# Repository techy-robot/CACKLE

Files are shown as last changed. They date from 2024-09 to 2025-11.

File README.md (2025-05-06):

---
modified: 2025-05-05T23:28:19-07:00
---
# CACKLE - Card Adaptable Controller Kinetic Link Electronics
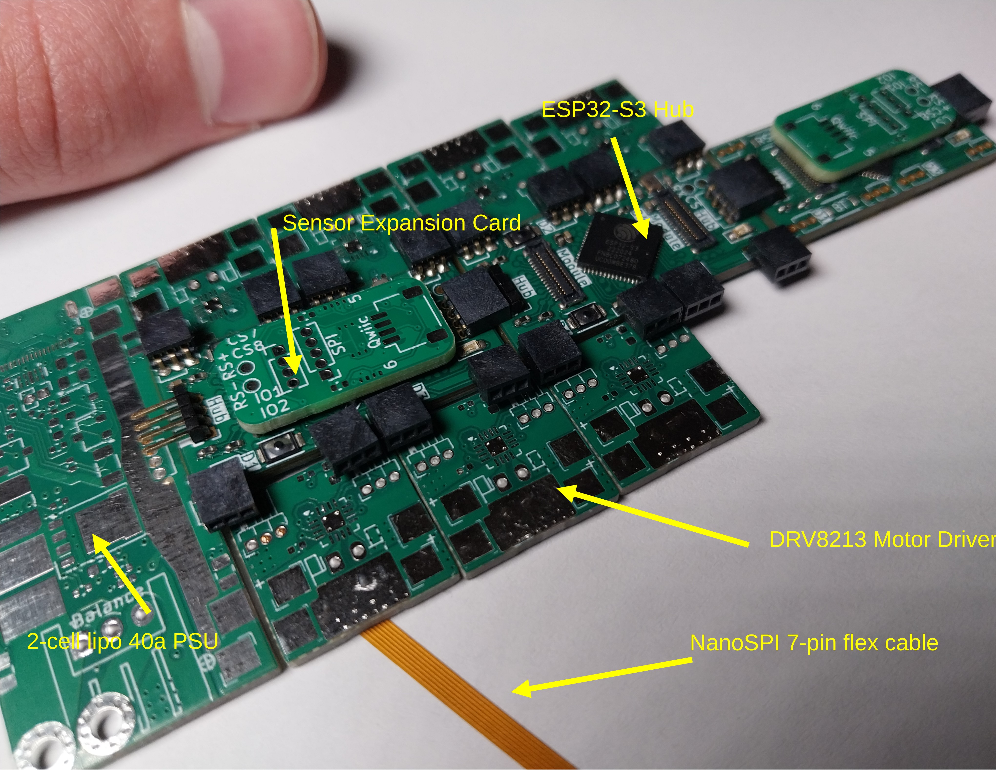
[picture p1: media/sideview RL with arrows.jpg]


This is designed to be a super small, open source, adaptable control board. Each module is arranged in units of 1.5cm squared, but can handle high power micro robotic actuators, such as my [Mighty-Micro-Motors](https://github.com/techy-robot/Mighty-Micro-Motors). Ideally this board can be reused and rebuilt for all sorts of small robots.

You can read up on specific modules in their respective folders in Hardware, or take a look at the overall architecture

Real Life pictures:




3D model demo:
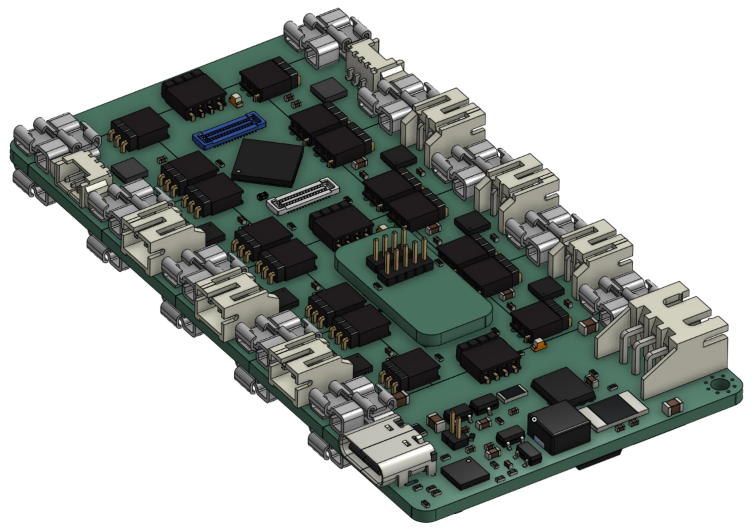
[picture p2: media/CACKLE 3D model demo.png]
CACKLE 3D model demo


# Architecture
There are currently 6 types of sub-boards:
- Hubs (with a MCU on it, supports 2 or 4 drivers, 2 expansion cards, and a chain of peers)
- PSUs (typically only one board)
- Expansion Cards (vertical mezzanine connector boards for breaking out sensors and other interfaces)
- Drivers (Any high power driver)
- nanoSPI devices (Small 7-pin flex cable SPI devices, mostly for sensors)
- Passives (spacers, end caps, etc...)

The base unit for this project is 1.5 cm squared. The expansion cards and drivers should each be 1 unit, the Hubs 1x1 or 1x2, and the PSUs 3x1 units. For example, with a 12 motor board you would need 1 PSU, 3 1-by-2 hubs, and 12 drivers; the board would be 45x105mm. nanoSPI devices can be much smaller due to the  2.4mm wide flex cable, such as a 5mm diameter magnetic encoder.

Unfortunately I was unable to create a 45x15mm PSU for the first version, it had to be extended up by 5mm to fit the high current circuitry.

My initial idea was to have spring contacts to allow easy clip in clip out, but finding no connectors quite what I wanted and unable to manufacture my own, I went with 1.27mm pitch pin headers and micro Keystone edge board connectors for power.

Original (bit outdated) sketch of the architecture:
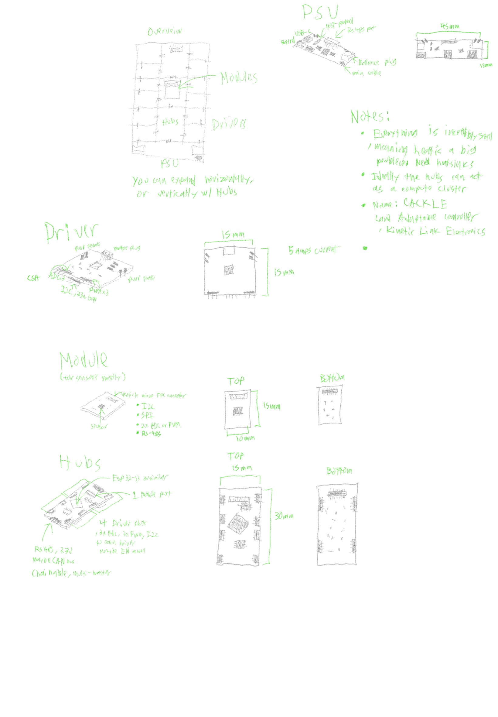
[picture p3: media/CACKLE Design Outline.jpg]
Cackle Design Outline


# Goals
- Adaptable 
- Small
- Extendable by other developers
- Easy to use
- Powerful

# Features
## Required:
- Super Small modules
- Hubs with an mcu that can talk to its peers and a master
- Motor driver boards that can handle several amps
- Sensor ports with protocols like i2c and SPI
- Extendable architecture
- PSUs
- LED status lights

## Nice to Have
- Distributed computing with a multi-master network
- Easy automatic hardware configuration
- Ability to stack hubs vertically using the Expansion Card system, in addition to horizontal chaining.

# Software
As of now software is very limited in scope, I have not had the time to fully assembly and test the boards I have made. I am planning on using SimpleFOC and Luos Engine. SimpleFOC is a motor driver library for Field Oreinted Control for motors. Luos Engine is a lightweight-distributed communication engine that aims to make hardware as modular as software. Combined, I have covered 50% of the use-cases of the code necessary for this project.

See [Software](Software/README.md) for more.

# Contributing
Feal free to contribute in any way possible! This is an open-source project, and with so many modules yet to be explored, I encourage you to help test boards, create modules or code, or ask about the project!

- GitHub Discussions: Participate in discussions on GitHub to share your experiences and ask questions.
- Contribute: Help develop the project, create PRs with new features or modules
- Report: Open issues, give me feedback!

Read the Architecture notes and [CONTRIBUTING.md](CONTRIBUTING.md) for more in-depth on this.

# A Note on Project Management
This project is managed transparently in this very repo. I am using Obsidian.md as my notetaking, documentation, and project management tool. A lot of the markdown files you will see in this repo might look a bit weird; that is due to the Wiki-links instead of markdown links and the YAML file front-matter that Obsidian supports. My system works well for one person, but I'm not sure how future proof this system is. You can find my sample vault here, which explains more: [GitHub - techy-robot/Project-Management-Obsidian-Sample-Vault](https://github.com/techy-robot/Project-Management-Obsidian-Sample-Vault).

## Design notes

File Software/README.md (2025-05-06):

# Software

Software is such a big element of any hardware project, and I do not like to write software, so I am using some really nice software libraries that I have found. The first is [SimpleFOC](https://www.simplefoc.com/), a motor driver library for Field Oreinted Control for motors, and the second is [Luos Engine](https://www.luos.io/), a lightweight distributed communication engine that aims to make hardware as modular as software. Combined, I have covered 50% of the use-cases of the code necessary for this project.

Most of the code found here are luos node definitions and driver services for each of the hardware modules, designed to be easily reusable in your project. There are also some tests and example code.

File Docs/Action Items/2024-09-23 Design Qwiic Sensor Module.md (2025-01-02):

---
title: Design Qwiic Sensor Module
aliases:
  - Design Qwiic Sensor Module
modified: 2024-09-23T19:24:35-06:00
tags: 
completed: true
itemtype: task
status: Done
date: 2024-10-21
startTime: 
endDate: 2024-10-26
endTime: 
deadline: 
allDay: true
priority: Low
effort: S
id: 
planned_hours: 
logged_hours: 
product_version: 
subitems: 
peeritems: 
milestone: 
createdby: 
assignees: 
completedby: 
completedDate: 2025-01-01
---
`BUTTON[complete, uncomplete]`

# Description:

This is just a sensor module to plug in to the top that fans out 4 adafruit qwiic connectors. Nothing major, not that important

# Comments:
- [ ] Comment ➕ YYYY-MM-DD ^1

# Time Tracking:
```simple-time-tracker
{"entries":[]}
```

# Changelog:
- 2024-09-23 Created

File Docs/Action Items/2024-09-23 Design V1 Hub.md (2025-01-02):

---
title: Design V1 Hub
aliases:
  - Design V1 Hub
modified: 2025-01-01T17:26:17-07:00
tags: 
completed: true
itemtype: task
status: Done
date: 2024-10-07
startTime: 
endDate: 2024-10-21
endTime: 
deadline: 
allDay: true
priority: Normal
effort: L
id: 
planned_hours: 30
logged_hours: 70
product_version: 
subitems: 
peeritems: 
milestone: "[[2024-09-23 Design V1 of all 4 modules|Design V1 of all 4 modules]]"
createdby: 
assignees: 
completedby: 
completedDate: 2025-01-01
---
`BUTTON[complete, uncomplete]`

# Description:

This is the central point of the modular control board. It talks to other hubs, drivers motor modules, and has multiple sensor interfaces. This is the most complex board followed by the PSU. See [[Architecture]].

This is a 6 layer board, which tries to follow the order Sig/Gnd/Pwr/Sig/Gnd/Sig. I did have to sacrifice the lower ground layer and route a few signals to make it all work together.

# Comments:
- [x] Shift all the motor pwm pins down, and stick the FREEx pins and the i2c pins near the end. Now, only the motor pins and the analog pins will have glitching. Since it is a low level glitch, and there are no pullups on those lines, it should be fine. ➕ 2024-10-17 ✅ 2024-10-17 ^1
- [x] Move out the pin headers a few 0.1mms so that the headers are exactly the distance required for connection to the motor cards ➕ 2024-10-18 ✅ 2024-10-18 ^2
- [x] Fix port 2 and 4 being swapped ➕ 2024-10-18 ✅ 2024-10-18 ^3
- [x] If I go with a 6 layer board design I will have more space to route, and JLC offers free filled vias with the increased cost, saving me even more space. ➕ 2024-10-18 ✅ 2024-10-18 ^4
- [x] The Free 1 and Free 2 pins might be more capable going on an analog capable pin. This, however, would require a fairly complex restructuring of the routing, which causes delay for not much gain ➕ 2024-10-19 ✅ 2025-01-01 ^5
- [x] There is a potentially big cross talk problem on layer In3. There is a high speed differential pair running on that layer, along with the lowspeed i2c lines, all right next to thick power traces. ➕ 2024-10-19 ✅ 2024-10-20 ^6
- [x] Disconnect all pins except RS485 and i2c from the bottom mezzanine connectors. If we stack hubs on top of eachother, we only want multi-master capable communications running through, otherwise there will be some fights. ➕ 2024-10-20 ✅ 2024-10-20 ^7

# Time Tracking:
```simple-time-tracker
{"entries":[{"name":"Schematic work","startTime":"2024-09-30T02:20:10.000Z","endTime":"2024-09-30T03:48:27.000Z"},{"name":"Schematic work","startTime":"2024-10-08T02:10:23.000Z","endTime":"2024-10-08T03:20:52.000Z"},{"name":"Finished rough schematic","startTime":"2024-10-09T01:45:54.000Z","endTime":"2024-10-09T03:20:43.000Z"},{"name":"Component Research","startTime":"2024-10-13T23:14:51.000Z","endTime":"2024-10-14T00:10:14.000Z"},{"name":"Designing footprint for mezzanine connectors","startTime":"2024-10-14T00:47:13.000Z","endTime":"2024-10-14T02:04:04.000Z"},{"name":"Component downsizing research, finished layout","startTime":"2024-10-15T20:15:11.000Z","endTime":"2024-10-16T01:59:11.000Z"},{"name":"started wire fanout","startTime":"2024-10-16T22:00:40.000Z","endTime":"2024-10-16T23:51:07.000Z"},{"name":"routing","startTime":"2024-10-17T21:36:40.000Z","endTime":"2024-10-18T00:03:41.000Z"},{"name":"routing and part rearrangement","startTime":"2024-10-18T15:54:34.000Z","endTime":"2024-10-18T16:56:00.000Z"},{"name":"routing 6 layers","startTime":"2024-10-18T19:45:01.000Z","endTime":"2024-10-19T00:06:37.000Z"},{"name":"debugging how to route a tricky wire","startTime":"2024-10-19T00:50:32.000Z","endTime":"2024-10-19T03:08:28.000Z"},{"name":"routing tricky wires","startTime":"2024-10-19T20:01:01.000Z","endTime":"2024-10-20T00:20:07.374Z"},{"name":"finished routing","startTime":"2024-10-20T14:49:04.000Z","endTime":"2024-10-20T15:50:43.000Z"},{"name":"finishing up","startTime":"2024-10-20T16:00:37.000Z","endTime":"2024-10-20T19:34:19.609Z"}]}
```

# Changelog:
- 2024-09-23 Created

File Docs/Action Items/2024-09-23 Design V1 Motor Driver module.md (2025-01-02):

---
title: Design V1 Motor Driver module
aliases:
  - Design V1 Motor Driver module
modified: 2025-01-01T17:26:04-07:00
tags: 
completed: true
itemtype: task
status: Done
date: 2024-09-23
startTime: 
endDate: 2024-10-07
endTime: 
deadline: 2024-10-07
allDay: true
priority: Normal
effort: M
id: 
planned_hours: 10
logged_hours: 7
product_version: 
subitems: 
peeritems: 
milestone: "[[2024-09-23 Design V1 of all 4 modules|Design V1 of all 4 modules]]"
createdby: 
assignees: 
completedby: 
completedDate: 2025-01-01
---
`BUTTON[complete, uncomplete]`

# Description:

# Comments:
- [x] I need to redo the power connector scheme, to make it work in reverse 180 orientation and to use the cheaper connectors. Reverse orientation capability would mean I need 4 connectors per edge. It *should* save time and hassle so that I don't have to produce a mirror board copy, but it will be costly. Another benefit is double the current capacity. ➕ 2024-10-14 ✅ 2024-10-21 ^1

# Time Tracking:
```simple-time-tracker
{"entries":[{"name":"Initial modifications from prev design","startTime":"2024-09-24T01:32:53.000Z","endTime":"2024-09-24T02:37:31.819Z"},{"name":"Finished basic layout","startTime":"2024-09-24T02:38:05.000Z","endTime":"2024-09-24T03:05:01.000Z"},{"name":"Finished basic routing","startTime":"2024-09-25T02:00:09.000Z","endTime":"2024-09-25T03:17:32.000Z"},{"name":"Finished design and silkscreen","startTime":"2024-09-27T21:37:55.000Z","endTime":"2024-09-27T23:19:31.000Z"},{"name":"Segment 5","startTime":"2024-10-21T14:00:11.000Z","endTime":"2024-10-21T15:50:21.000Z"}]}
```

# Changelog:
- 2024-09-23 Created

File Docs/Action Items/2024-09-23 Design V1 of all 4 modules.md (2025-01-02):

---
title: Design V1 of all 4 modules
aliases:
  - Design V1 of all 4 modules
modified: 2024-09-23T18:46:33-06:00
tags: 
completed: true
itemtype: milestone
status: Done
date: 2024-09-23
startTime: 
endDate: 2024-10-31
endTime: 
deadline: 2024-10-31
allDay: true
id: 
product_version: 
peeritems: 
subitems: 
createdby: 
assignees: 
completedDate: 2025-01-01
---
`BUTTON[complete, uncomplete]`

# Description:

In 1 month and 1 week, I hope to have a complete basic set of boards complete, with all 4 types of boards. See [[Architecture]]. 

# Comments:
- This I believe is achievable, because I've already done half the design work from other projects, all I need to do is change the form factor! ➕ 2024-09-23 ^1
- 
# Changelog:
- 2024-09-23 Created

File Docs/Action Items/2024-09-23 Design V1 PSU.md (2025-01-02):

---
title: Design V1 PSU
aliases:
  - Design V1 PSU
modified: 2025-01-01T17:25:49-07:00
tags: 
completed: true
itemtype: task
status: Done
date: 2024-10-25
startTime: 
endDate: 2024-11-10
endTime: 
deadline: 2024-11-10
allDay: true
priority: Normal
effort: L
id: 
planned_hours: 50
logged_hours: 40
product_version: 
subitems: 
peeritems: 
milestone: "[[2024-09-23 Design V1 of all 4 modules|Design V1 of all 4 modules]]"
createdby: 
assignees: 
completedby: 
completedDate: 2025-01-01
---
`BUTTON[complete, uncomplete]`

# Description:

# Comments:
- [x] I found several design errata from the original, such as swapped polarity on the balance plug, and incorrect input voltage source. My prototype will need modification ➕ 2024-10-27 ✅ 2025-01-01 ^1
- [-] I should add a secondary rs485 transceiver for redundancy for the host. The battery charge mcu should not have to act as a passthrough for the main compute module. Still, for this prototype it is unneccessary ➕ 2024-11-08 ❌ 2025-01-01 ^2
- [-] Use XT30 connectors for the main battery plug ➕ 2024-11-08 ❌ 2025-01-01 ^3
- [x] The BQ24780s does not handle charge profiles by itself, the i2c host has to handle all the battery charge profiles by itself. ➕ 2024-11-08 ✅ 2025-01-01 ^4

# Time Tracking:
```simple-time-tracker
{"entries":[{"name":"Initial arrangment of schem","startTime":"2024-10-26T02:39:49.000Z","endTime":"2024-10-26T03:48:16.000Z"},{"name":"schematic verification","startTime":"2024-10-26T22:47:46.000Z","endTime":"2024-10-27T00:24:49.000Z"},{"name":"rearranging schematic","startTime":"2024-10-27T00:57:04.000Z","endTime":"2024-10-27T02:34:08.000Z"},{"name":"component research, schematic work","startTime":"2024-10-27T22:02:31.000Z","endTime":"2024-10-28T00:08:18.000Z"},{"name":"verification and component switching","startTime":"2024-10-28T00:53:49.000Z","endTime":"2024-10-28T01:40:12.000Z"},{"name":"Adding MCU","startTime":"2024-11-07T02:06:24.000Z","endTime":"2024-11-07T03:01:16.000Z"},{"name":"Starting routing from scratch","startTime":"2024-11-08T00:29:47.000Z","endTime":"2024-11-08T01:08:36.609Z"},{"name":"Working on MCU section again","startTime":"2024-11-08T02:23:47.000Z","endTime":"2024-11-08T05:26:09.000Z"},{"name":"schematic work","startTime":"2024-11-08T16:56:29.000Z","endTime":"2024-11-08T17:57:02.000Z"},{"name":"research of components","startTime":"2024-11-08T22:13:40.000Z","endTime":"2024-11-09T01:58:19.000Z"}]}
```

# Changelog:
- 2024-09-23 Created

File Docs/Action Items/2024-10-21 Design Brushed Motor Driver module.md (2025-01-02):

---
title: Design V1 Motor Driver module
aliases:
  - Design V1 Motor Driver module
modified: 2024-10-25T17:01:51-06:00
tags: 
completed: true
itemtype: task
status: Done
date: 2024-10-21
startTime: 
endDate: 2024-10-26
endTime: 
deadline: 2024-10-26
allDay: true
priority: Normal
effort: M
id: 
planned_hours: 10
logged_hours: 9
product_version: 
subitems: 
peeritems: 
milestone: "[[2024-09-23 Design V1 of all 4 modules|Design V1 of all 4 modules]]"
createdby: 
assignees: 
completedby: 
completedDate: 2025-01-01
---
`BUTTON[complete, uncomplete]`

# Description:

# Comments:
- [ ]  ➕ 2024-10-14 ^1

# Time Tracking:
```simple-time-tracker
{"entries":[{"name":"Initial work","startTime":"2024-10-22T00:30:45.000Z","endTime":"2024-10-22T03:30:47.000Z"},{"name":"edited schemtatic for the more complex chip","startTime":"2024-10-24T03:18:30.000Z","endTime":"2024-10-24T03:45:03.000Z"},{"name":"Changing Schematic","startTime":"2024-10-24T16:01:49.000Z","endTime":"2024-10-24T16:20:35.000Z"},{"name":"Changing Schematic to enable inrush limits at all times","startTime":"2024-10-24T18:30:52.000Z","endTime":"2024-10-24T19:11:00.554Z"},{"name":"routing and adding testpoints","startTime":"2024-10-25T02:22:25.000Z","endTime":"2024-10-25T03:50:00.000Z"},{"name":"Segment 6","startTime":"2024-10-25T19:56:10.000Z","endTime":"2024-10-25T22:56:19.697Z"}]}
```

# Changelog:
- 2024-09-23 Created

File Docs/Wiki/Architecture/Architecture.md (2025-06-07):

---
aliases: 
tags: 
append_modified_update: true
modified:
  - 2024-08-09T20:39:57-06:00
  - 2024-08-11T20:12:22-06:00
  - 2024-09-07T17:55:38-06:00
  - 2024-09-08T09:46:12-06:00
  - 2024-09-16T21:17:40-06:00
  - 2024-09-23T18:45:05-06:00
  - 2024-10-19T17:45:06-06:00
  - 2024-11-06T17:24:05-07:00
  - 2024-11-22T22:24:30-07:00
  - 2025-01-01T19:29:53-07:00
  - 2025-03-02T16:29:23-07:00
---
# Types of sub-boards
- Hubs (with an MCU on it, supports 2 or 4 drivers, 2 expansion cards, and a chain of peers)
- PSUs (typically only one board)
- Expansion Cards (vertical mezzenine connector boards for breaking out sensors and other interfaces)
- Drivers (Any high power driver)
- nanoSPI devices (Small 7-pin flex cable SPI devices, mostly for sensors)
- Passives (spacers, end caps, etc...)

# Dimensions
The base unit for this project is 1.5 cm squared. The expansion cards and drivers should each be 1 unit squared, the Hubs 1x1 or 1x2, and the PSUs 3x1 units. With a 12 motor board with PSU for example, the board would be 45x105mm. nanoSPI devices can be much smaller due to the flex cable, such as a 5mm diameter tip and 2.4mm wide cable.

Any board on the ends of the main board (PSUs or sensor arrays) can be extended beyond the 1 unit vertical limitation. For example, the V1 PSU is 20mm instead of 15mm high, meaning its 3x1 & 1/3 units.

# Communication Protocol
The Hubs communicated over a 3.3v (NOT 5v!) RS485 bus using Modbus or a derivative communication protocol. It is a multi master system.

Sensors can communicate to the hubs using I2c or SPI, and the hubs can subsequently advertise the sensor resources on the main network.

The one exception to the RS485 network is for GPU intensive modules, such as displays or cameras. Those are expected to go directly to the board requiring the resources and not to be broadcasted over the network, due to bandwidth limitations.

# MCU requirements
Highspeed 32-bit MCUs for the hubs are ideal with over 100mhz clock speed. Dual-core MCUs are nice but not required. The chips should operated on 3.3volts and not be sensitive to voltage fluctuations. 

The chips should also have DMA access or a highspeed peripherial for PWM and ADC pins, and all external driver connections must be connected directly to them. Other pins do not have to be connected directly to the hub since they are less demanding. 

At least one I2c and one SPI bus is required for the expansion ports and the nanoSPI connectors. If the device has multiple buses and can afford it in pins, you can split the networks per expansion connector or between nanoSPI connectors and expansion connectors.

Only 2 ADC lines per driver slot are required, though 3 is nice. There isn't currently a need for 3 ADC lines because both brushed and brushless motor drivers can work fine with only 2 current sense feedback lines. This may change

The first chip I used is the esp32-s3. This chip is a low on pins, so some tricks such as disabling USB, programming over the sensor SPI bus, and using a shift register for SPI chip selects were used. I also have exposed only 2 adc lines per driver.

# Numbering Scheme
The numbering scheme between hubs is bottom up, with the PSU at the very bottom as address 0, and hubs connected on top of that with subsequent numbers. All the sensor and motor ports per hub follow this numbering scheme as well, with a left to right scheme added. Even the individual driver pins follow the bottom up scheme

# Changelog:
- 2024-08-09 Created
- 2025-01-01 Updated ideas and spec
- 2024-03-02 Added jumbo size and power bypass ideas

See also:
```dataview
LIST
FROM outgoing([[]])
```

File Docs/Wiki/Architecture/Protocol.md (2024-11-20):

---
aliases: 
tags: 
append_modified_update: true
modified:
  - 2024-09-16T21:19:03-06:00
  - 2024-09-29T21:48:08-06:00
  - 2024-10-08T20:11:50-06:00
  - 2024-10-27T21:47:33-06:00
---

# Protocol
Ideally I want this board is to be **asymmetrical** in communication, where no one MCU is master. This theoretically would allow me to have a **compute cluster** using onboard MCUs, without relying on a powerful SBC. I will still likely have a host SBC talk with the board for advance AI. Each MCU has a customizable config that can be updated to help it understand it's place and connected motors and sensors. The best multi-master/ multi-drop busses I found are differential, such as RS485, ethernet, and CAN. They all support buses and collision detection, though RS485 is just a hardware spec and you have to write your own multi-master protocol on top.

Yet there are also a lot of **dis-advantages** with this setup, namely **Speed and cost**. Any sort of differential bus is NOT usually supported natively, and therefore will require a 1 dollar transceiver per board. It is also really slow, with CAN bus topping out at 1MB/s. Ethernet is much higher speed, but it requires really expensive chips or a lot of pins. SPI bus in this case would win for speed and cost savings, though it would mean a master and slave architecture

SPI bus has its own problems though, such as not being infinitely expandable. The number of devices is limited to the number of pins on the master, meaning I can't plug in boards forever.

It appears like I am in a sticky conundrum, with no where to turn without sacrifices. I want infinite expandibilty, high speed, and low cost. I could write my own ring-based protocol, but that would be slow speed and probably not that reliable. If I wrote a protocol and wanted it high-speed, the best way to achieve that would be to use an existing hardware protocol..

For a project like my robot dog with limited motor potential, it is easier to choose a protocol. I could probably just use SPI, since I will unlikely have more than 4 hubs. I loose out on asymmetrical, but I save cost and have super high speeds. For any other projects though it is tough, especially since the board will be its own commercial product.

THE ONLY bus that seems to balance everything is I2C. It is low speed like CAN bus, but it is virtually in every micro controller in modern times, which is cheap. If you add a layer on top you get SMbus, which supports arbitration and multimaster easily. Bus speeds are limited to 100khz with SMbus.

A bus that I found very interesting is called I3C. Its meant to be a replacement bus operating at 12.5mhz and supporting everything that i2c does. Think SMbus, with hotplug and a 100x speed. It is not supported by most board yet though.

RS-485 is my ideal second choice, because I can implement whatever protocol I wanted and use some cheap $1 transceivers (like the TI 1420 ($1.03) or  ISP3485EN-L/TR ($0.87)). CAN bus transceivers cost more, even in the same SOIC-8 package. If I wanted a smaller package I could pay more and get THVD1420DRLR for $1.42

Another Idea I had was using a RP2040 as a repeater. If I had a 15x15mm module between, then it could repeate the SPI signals and have infinite number of chip selects. The RP2040 can also have 2 motor driver modules plugged in, (it has exactly 4 ADC), and it can also act as a node itself for computing. Its only a dollar, which is about the price of a differential bus transceiver!

I could write a protocol that supports user-assisted auto addressing. The user could press the BOOT buttons on each board in order, and the address will be broadcasted on the network on by one! The ordered number would also be saved on chip, and each chip would have its own map. This idea works for both multi-master and master-slave architecture, and does not need external connections to setup a network. Each device added afterward initial setup would broadcast its mac address, and would be assigned a number based on the existing map. You can trigger a map reset too. 

For hotplugging rs 485 support I should have the chip assume on powerup that nothing is talking to it, and only after a set delay of idle bus should it respond

I also found an opensource product that does almost exactly what I want for my modular robot control system! Its called [luos_engine](https://github.com/Luos-io/luos_engine). Every MCU knows all the others in the system and can communicate with any of the servicies. This was just a random discussion I found on the SimpleFOC discord about its integration. [Luos Technology | Luos](https://www.luos.io/docs/luos-technology). Luos has its own communication protocol built in, called Robus, which supporst Rs485 or One wire. It supports 700kbs per second for data max on a 1mhz bus. I would write my own motor services and process data commands.

# Changelog:
- 2024-09-16 Created

See also:
```dataview
LIST
FROM outgoing([[]])
```

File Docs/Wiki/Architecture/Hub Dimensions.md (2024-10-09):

---
aliases: 
tags: 
append_modified_update: true
modified:
  - 2024-10-08T21:05:46-06:00
---

Each hub has 4 motor ports, with 1.27mm pin header sockets sticking past the edge of the board

The board should have two M2 screw holes in the board somewhere.

There are two mezzanine connectors receptors on the top, and two headers on the bottom. They are centered in each half of the board, so 8.5mm away from the edges. This provides room for the esp32 to be in the direct center, and it provides future opportunities such as 2 sensors per board, spanning sensor mounts between boards, or a half length 2 motor hub.

# Changelog:
- 2024-10-08 Created

See also:
```dataview
LIST
FROM outgoing([[]])
```

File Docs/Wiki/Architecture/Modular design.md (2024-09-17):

---
aliases: 
tags: 
append_modified_update: true
modified:
  - 2024-08-09T20:39:57-06:00
  - 2024-08-11T20:12:22-06:00
  - 2024-09-07T17:55:38-06:00
  - 2024-09-08T09:46:12-06:00
  - 2024-09-16T21:17:40-06:00
---
It is a modular control board design, with 4 main types of units:
- Hubs (with an MCU on it, supports 4 drivers, one sensor with a vertical micro connector, and a chain of peers)
- PSUs (typically only one board)
- Modules/ Sensors (vertical mezzenine connector boards for sensors)
- Drivers (Any high power motor driver, plus a SPI bus for feedback sensors)

The base unit for this project is 1.5 cm squared. The modules and drivers should each be 15x15mm, while the Hubs are 15x30mm. There is a slight possibility it can be 15x10mm instead.

With a 12 motor board that would be 45x90mm

The PSU and any extra peripheral such as speakers will have to be off-board and crammed somewhere else, though small sensors can be mounted vertically on the connectors. If the Battery charger is too difficult to cram in the provided space, I could move the battery charger off the board and have the battery protector in the robot only.

My idea is to use some highspeed dual core MCUs for the hubs, something like the ESP32-s3. The esp32-s3 is low on pins, therefore I will have to use some tricks such as disabling USB, programming over the sensor SPI bus, and using a multiplexor or shift register for SPI chip select. Depending on the chosen inter-hub protocol I may have a few more pins.

Ideally I will have spring contacts for all the modules, and you can just clip them in. But I will have to custom manufacture these board springs that clip into through holes, because I haven't found any commercially available ones. Alternately I can use some Keystone micro SMD tab pins.

3.3v should be supplied to the Drivers, in case I wanted to plug in a bigger or power hungry sensor board, or if I have a driver chip that doesn't have a built in regulator.

# Changelog:
- 2024-08-09 Created

See also:
```dataview
LIST
FROM outgoing([[]])
```

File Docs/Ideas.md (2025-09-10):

---
aliases:
tags:
append_modified_update: true
modified:
  - 2025-06-06T20:38:58-06:00
  - 2025-09-09T16:25:11-06:00
---

# New Module Types
- A compute board would be nice, I'm thinking it would be a 45mm x45mm SBC with connectors to pass power and signals through
- Various "passive" board types, like power hubs, horizontal or vertical spacers where you want empty space, and blank driver and sensor boards where all the signals are exposed for easier prototyping and soldering.
- I also have an idea for sensor array's, which are on the opposite ends of a PSU. They measure 15x45 and exist for advanced sensors such as cameras, LIDAR, or anything really that doesn't fit in the normal 10mmx15mm sensor package.
- Jumbo sized modules, that are 30x30. This is for really complex items that need highpower and more surface area, like a mosfet or relay.
- Isolators for power and signals that prevent interferance
- Translators, for rs485 to canbus or usb or whatever.
- 1 sided PSUs and PSUs with no driver output

# New Modules
- DRV8850 motor driver, a high current (5-8amps), low voltage (5v) H-bridge driver. Needs 4 control pins

# Other ideas
- Move from 3pwm outputs to 4 pwm outputs for each port on the hubs, in-case you wanted to have a manual h-bridge a dual motor controller, or a stepper driver that didn't have step/dir control.
- Shrink the base unit from 15mm squared to 10mm squared.
- Power Bypass connection ecosystem, a bunch of thick wires and jumpers between boards instead of board to board. This should be for highvoltage or high currant applications

# Changelog:
- 2025-06-06 Created

See also:
```dataview
LIST
FROM outgoing([[]])
```

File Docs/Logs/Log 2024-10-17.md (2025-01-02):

---
aliases:
  - 2024-10-17
append_modified_update: true
modified:
  - 2024-10-17T22:31:13-06:00
  - 2025-01-01T17:30:37-07:00
---
←[[Log 2024-09-23|2024-09-23]] [[Logs]] [[Log 2025-01-01|2025-01-01]]→
# Thursday
___

I've started the pcb routing and have discovered some issues.

I changed the schematic so that the Shift Register clock is also on a dual high/low glitching pins. I swapped out a test pad for a Free 2 pin, for the second expansion connector.

I2c w/ pullups will likely have problems with glitching on those first 20 pins, so I have shifted all the motor pwm pins down, and stuck the FREEx pins and the i2c pins near the end. Now, only the motor pins and the analog pins will have glitching. Since it is a low level glitch, and there are no pullups on those lines, it should be fine.

# Ongoing:
- 
# Changelog:
- 2024-10-17 Created

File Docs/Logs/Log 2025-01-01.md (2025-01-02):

---
aliases:
  - 2025-01-01
append_modified_update: true
modified:
  - 2025-01-01T17:30:29-07:00
---
←[[Log 2024-10-17|2024-10-17]] [[Logs]] [[]]→
# Wednesday
___

I finally finished all my designs! Horray! It was really difficult and I made many mistakes that had to be fixed.

I haven't kept the most faithful time track, mostly due to other activities and finding a better time tracking method with Wakatime.

# Ongoing:
- Order V1 boards!
# Changelog:
- 2025-01-01 Created

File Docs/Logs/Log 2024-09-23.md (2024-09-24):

---
aliases:
  - 2024-09-23
append_modified_update: true
modified:
  - 2024-09-23T21:06:18-06:00
---
←[[]] [[Logs]] [[]]→
# Monday
___

Today I am kicking off my design phase. I will design one of each type of board, and I have 1 month and 1 week to do so. Milestone: [[2024-09-23 Design V1 of all 4 modules|Design V1 of all 4 modules]]. 

I finished the basic layout of a 15mmx15mm driver card. It will need some tuning, and the power connectors as of now have no way of contacting adjacent cards.

# Ongoing:
- [[2024-09-23 Design V1 Motor Driver module|Design V1 Motor Driver module]]
# Changelog:
- 2024-09-23 Created

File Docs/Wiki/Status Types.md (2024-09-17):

---
modified:
  - 2024-01-11T15:55:46-07:00
  - 2024-05-13T11:26:11-06:00
append_modified_update: true
---

Ideally these will all have specific colors. I will list the colors here, even if I haven't implemented the css yet.

status:
- New:   Dark Blue
- Blocked:   Red
- In Progress:   Yellow
- Pending:   Yellow
- Done:  Green
- Archived:  Grey

priority:
- Low: Dark Green
- Normal: Green
- Medium: Yellow
- High: Orange
- Critical: Red

effort:
- XS
- S
- M
- L
- Xl
- XXL

type:
- task
- subtask
- bug
- story
There are also types that have their own template:
- milestone
- goal

goalstatus:
- On Track: Green
- Off-Track: Yellow
- At Risk: Yellow
- Miss: Red
- Not Started: Grey
- Finished: Green
- Discontinued: Grey

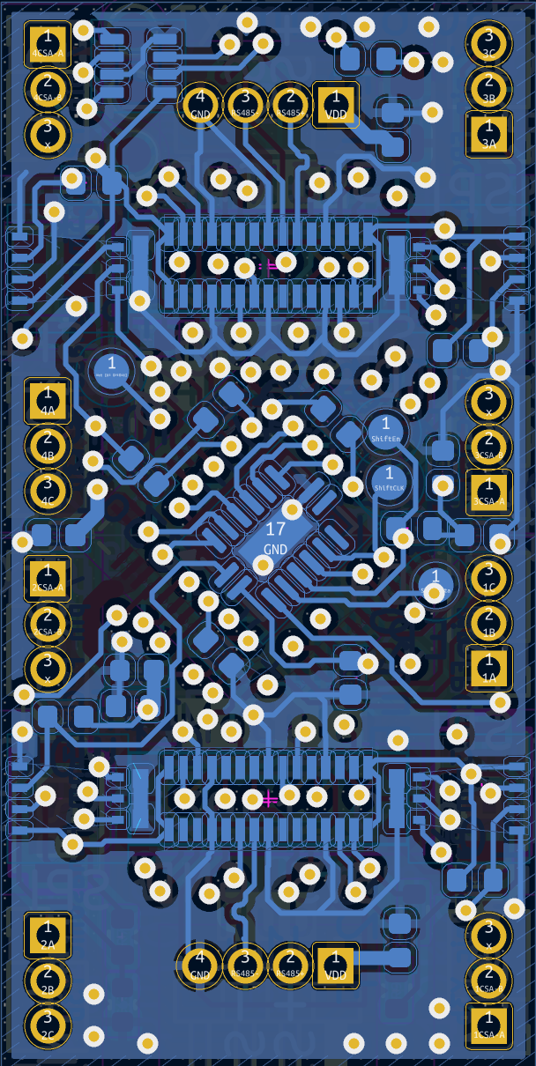
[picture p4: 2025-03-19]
Hardware/Hubs/ESP32-S3 Hub/media/ESP32-S3 hub Bottom.png

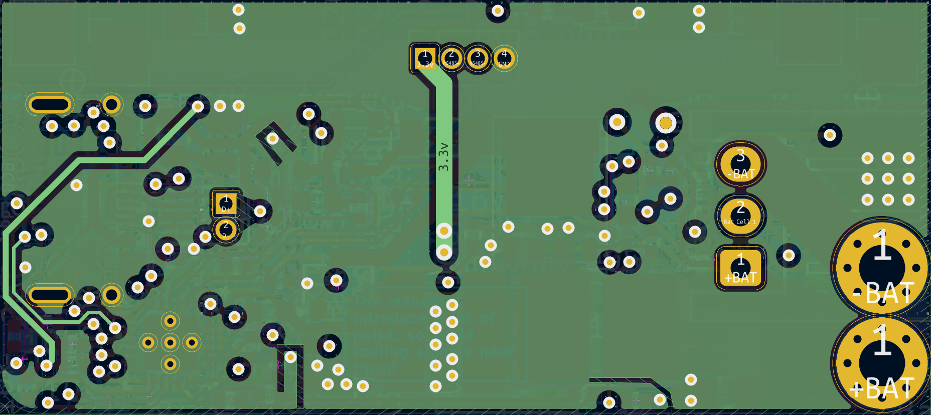
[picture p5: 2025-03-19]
Hardware/PSUs/2s 40A PSU and charger/media/2s 40a PSU In1.png

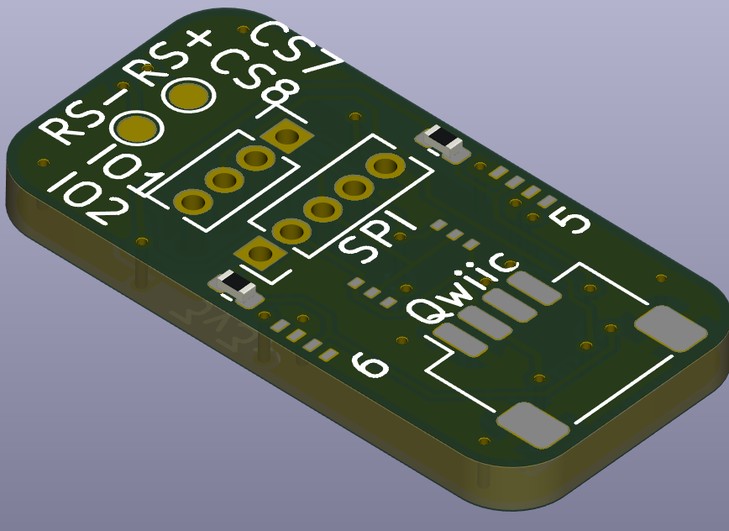
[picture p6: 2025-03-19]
Hardware/Expansion cards/2 connector Sensor Board/media/2 conn Sensor Board 3D.png

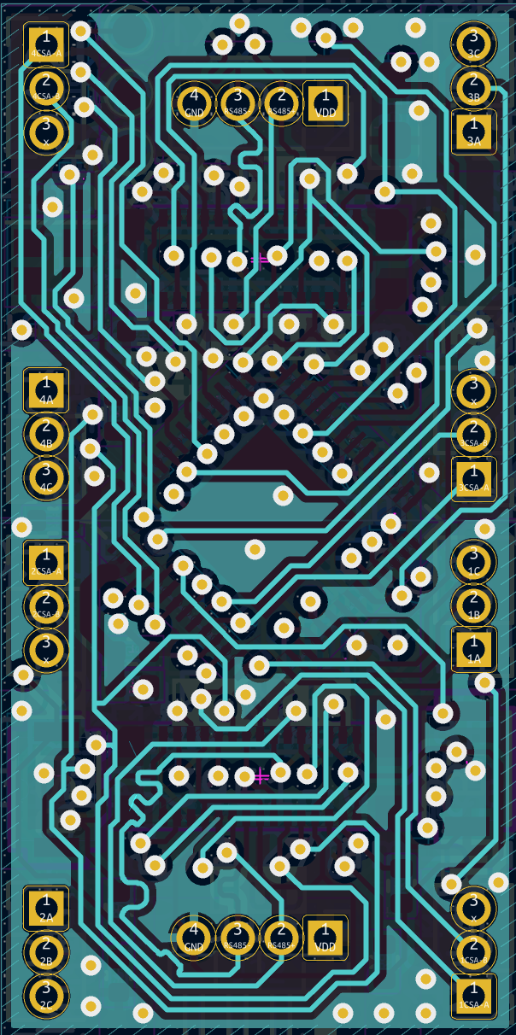
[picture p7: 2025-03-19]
Hardware/Hubs/ESP32-S3 Hub/media/ESP32-S3 hub In3.png

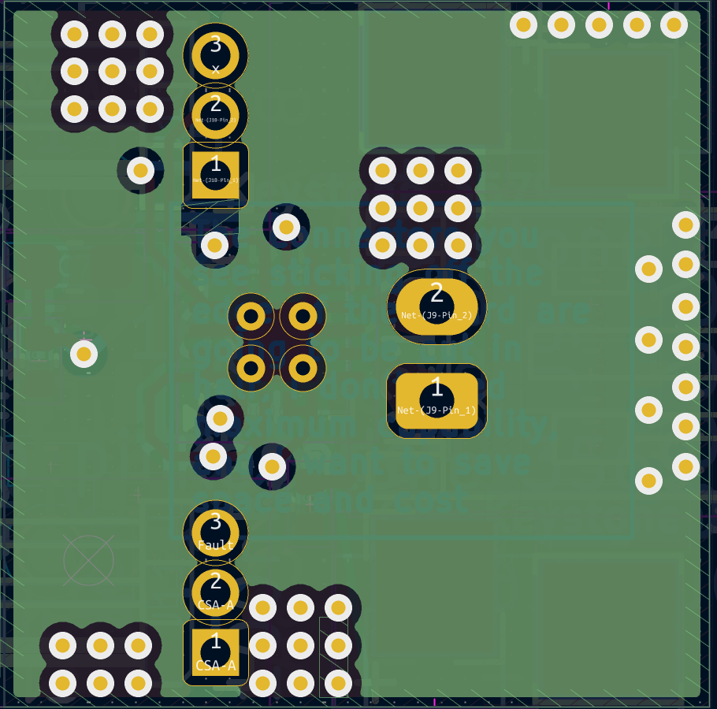
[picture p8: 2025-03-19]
Hardware/Drivers/DRV8213 brushed Motor Driver/media/DRV8213 In1.png

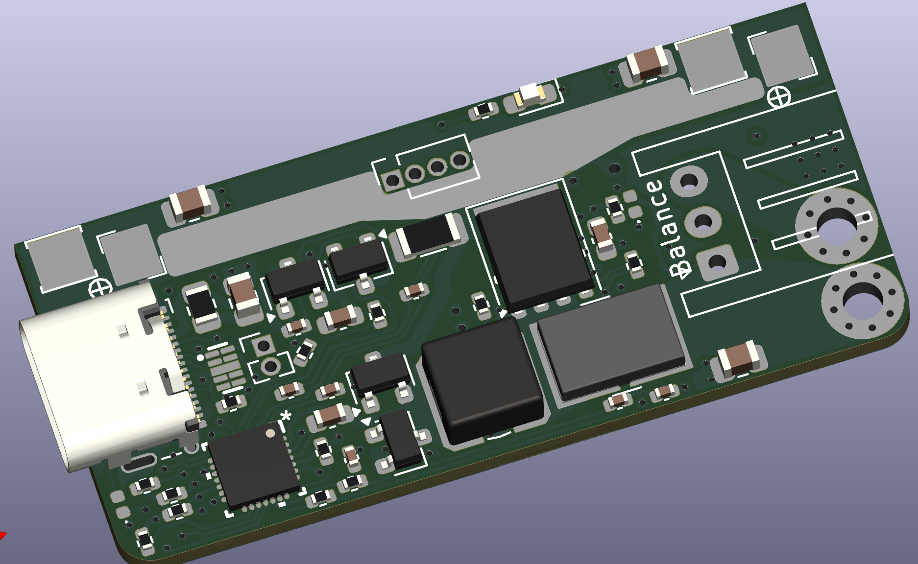
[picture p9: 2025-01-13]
Hardware/PSUs/2s 40A PSU and charger/media/2s 40a PSU 3D picture.png

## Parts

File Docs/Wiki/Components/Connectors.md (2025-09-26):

---
aliases:
tags:
append_modified_update: true
modified:
  - 2024-10-14T22:13:06-06:00
  - 2025-09-23T16:41:40-06:00
---

I am trying to save money while still acheiving what I need. Currently, for signal lines I am using 1.27mm right angle pin headers, and for Power, I'm using Keystone 6100 and 6102 quick connect edge connectors. For vertical Mezzanine connectors, I am using TE 3-2363961-0 receptacle and TE 3-2363962-0 connector, 30 pins.

The power connectors are expensive, around $1.8 per pair. I have found a sister product that is much cheaper however, and provides almost the exact same functionality. Its Keystone 3579, which is tin plated instead of gold plated. It can still carry 10 amps per connector. The matching component is 3569, which is a fuse clip. Now, this is much longer than the 610x receptacle, and the blade doesn't stick completely into it. I had a fun idea of chopping the part in half, and using it twice. The length would match, it would just be unstable on the board (ie not usable on a PnP).

If I cut in half, the price per pair would be $0.83! This seems like a pretty good deal for a high current SMD connector, at least compared to everything else I've seen. I would probably get lower only if I stamped my own spring connectors.

# Alternative connectors:
- https://www.digikey.com/en/products/detail/amphenol-cs-fci/10120045-401LF/4996150. 4 position LED lighting connector. This has a much wider spacing than I want, but is a good style with the blades. The connector is Hermaphroditic too.
- https://www.digikey.com/en/products/detail/hirose-electric-co-ltd/TB4-10P-1F-800/26223934 This is interesting, fpc connector to a different type of connector. There is no board to board option though.
- https://www.digikey.com/en/products/detail/sullins-connector-solutions/EBC06MMBD/1922770 This is the only right angle edge card connector I can find, there are millions of female connectors.
- https://www.digikey.com/en/products/detail/amphenol-cs-fci/10162583-411111LF/15216696 Something that has right angle header but no right angle receptacle.
- [504275-E : ERNI PCB Headers & Receptacles \| TE Connectivity](https://www.te.com/en/product-504275-E.html) This is pretty good.
- [917360-6 : AMPMODU PCB Headers & Receptacles \| TE Connectivity](https://www.te.com/en/product-917360-6.html) Looks like what I want, but its obselete!!

# Changelog:
- 2024-10-14 Created

See also:
```dataview
LIST
FROM outgoing([[]])
```

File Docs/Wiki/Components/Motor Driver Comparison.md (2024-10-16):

---
modified:
  - 2024-03-10T20:55:09-06:00
  - 2024-03-25T23:00:11-04:00
  - 2024-03-26T23:00:08-04:00
  - 2024-03-27T23:03:02-04:00
  - 2024-03-28T20:45:51-05:00
  - 2024-03-29T21:33:36-06:00
  - 2024-04-18T10:13:47-06:00
  - 2024-04-23T19:48:00-06:00
  - 2024-04-25T20:01:09-06:00
  - 2024-04-27T14:00:26-06:00
  - 2024-04-29T18:03:12-06:00
  - 2024-10-14T22:05:33-06:00
append_modified_update: true
---

I want a FOC controller that is compact and not to expensive. This is not in the task/goal system.

Helpful page for TI drivers: [Brushless DC (BLDC) motor drivers | TI.com](https://www.ti.com/motor-drivers/brushless-dc-bldc-drivers/overview.html)

# Position Control

FOC controllers already can detect relative position of a motor. However it is not that precise, and at slow speed useless. Since my motors will be on a reduction gear box, it should be fine. I will have to figure out absolute position anyway. 3d Hall effect sensors are an attractive option, because they don't need an encoder wheel.

Another option is designing a complex driver that can inject high-frequency pulses and measuring those to get absolute motor position.

# Types
Most of these chips still require output gate transistors.

- Integrated XXX. A chip that has everything already built in to drive. Replace XXX with the control algorithm. It may or may not be a FOC, but it still is standalone and space saving. 
- Normal cheap ESC.
- Driver. These have FETs and current sensors, but they still need a microchip to support. Has 3 PWM inputs usually
- Microcontroller [[Microcontroller Comparison]]. Useful for installing Simple FOC, it may be a good cheap option, but a microchip + driver takes up more space
- 
# Driver Table

| Driver | Type | Voltage | Drive Current | Indv Price per 10 Qty | Online Rating | Notes | Link |
| --- | --- | --- | --- | --- | --- | --- | --- |
| AMT49406 | Integrated FOC | 5.5-50v | Needs FETs | $2.91 | | First option I found for code-less FOC. Similar is A89301 | [AMT49406GESSR \| Digikey](https://www.digikey.com/en/products/detail/allegro-microsystems/AMT49406GESSR/10498710) |
| TI DRV8311  | Driver | 3-20v | 5A | $1.41 | | S and P variants have a 1 pwm input mode that automatically generates signals. Also SPI interface, which can be a driver | [Site Unreachable](https://www.mouser.com/new/texas-instruments/ti-drv8311-bldc-motor-driver/) |
| TI MCT8315Z | Integrated trapezoidal | 4.5-40v | 4A | ($0.98 per 1k) exception | | 1 PWM input. Cant purchase from distributer | [MCT8315Z data sheet, product information and support \| TI.com](https://www.ti.com/product/MCT8315Z) |
| TI DRV10974 | Integrated sinusoidal  | 4.4-20v | 2.5A | $1.21 | | Order from Arrow. Smallest ESC. | [DRV10974 data sheet, product information and support \| TI.com](https://www.ti.com/product/DRV10974) |
| TI DRV10970 | Integrated sinusoidal  | 5-20v | 3A | $2.2 | | Similar to DRV10974  except more current, and require hall sensors. In TSSOP package | |
| TI DRV8313  | Driver | 8-65v | 2.5A | $3.19 | | | [DRV8313 data sheet, product information and support \| TI.com](https://www.ti.com/product/DRV8313) |
| TI DRV8317  | Driver | 4.5-24v | 5A | | | Need to order 1k | |
| ST SPIN233  | Driver | 1.8-10v | 1.3A | $1.96 | | Nice and simple triple half bridge, Smallest ESC. Over priced for functionality | [Fetching Title#mc68](https://www.st.com/en/motor-drivers/stspin233.html) |
| TI DRV8316c | Driver | 4.5-40v | 8A | | | Has better current sensing than 8316. Need to be in 3k orders. | |
| ST L6234 | Driver | 7-45v | 5A | | | Basic, bigger package | |
| MCF8316A | Integrated FOC | 4.5-40v | 8A | $4.12 | | An interesting option from TI. I think it is limited to 12-24 volt motors | |

## Top Picks:
- TI DRV8311.
- TI DRV10974. 

Both are cost effective. DRV10974 is more design compact, with a sinusoidal wave generation built in. Sinusoidal is the best thing below FOC control. It also is a little bit smaller, with 4 pins on each side

However the DRV8311 supports a voltage and current range more suitable for my application. The docs specifically state 1s-4s for mobile applications. Unbalanced 5x7 pin count. It supports SPI control(S variant, P variant for multi-device address selector), which will reduce a lot of pin count if it works. Maybe I can do FOC control over SPI, but this is a bit of a stretch. Note that the P variant has NO support for hardware, and vice-versa. I will have to buy two chip versions and test each to see how SPI FOC works. This may help[TMC6200 SPI With Simple FOC - hardware support - SimpleFOC Community](https://community.simplefoc.com/t/tmc6200-spi-with-simple-foc/4157/3) BTW the S variant IS NOT PRUCHASABLE.

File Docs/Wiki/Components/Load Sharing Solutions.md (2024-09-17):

---
aliases: 
tags: 
append_modified_update: true
modified:
  - 2024-04-26T22:01:06-06:00
  - 2024-04-27T22:10:46-06:00
  - 2024-04-28T21:32:27-06:00
  - 2024-05-03T21:08:05-06:00
  - 2024-05-04T16:27:51-06:00
  - 2024-05-07T22:05:46-06:00
  - 2024-05-08T17:33:46-06:00
  - 2024-05-27T22:30:01-06:00
---
[[2024-04-26 21-30-46 - Lithium Ion Battery Charger Circuit Load Sharing]]
[[2024-04-26 22-00-06 - Power path management  diode OR-ing  Details  Hackaday.io]]

Article on designing power path using discrete components: [BQ24650: Power path design using BQ24650 - Power management forum - Power management - TI E2E support forums](https://e2e.ti.com/support/power-management-group/power-management/f/power-management-forum/756067/bq24650-power-path-design-using-bq24650)

The LTC44 series from Analog Devices seams like a good option. There also is the TI BQ series.

I'm looking for a controller that has something like DPPM (Dynamic Power-Path Management) from TI's DQ charger series. This prioritizes output current.

Another thing I may need is a Load switch IC or a hot swap controller.

# Power Path Chips:
All the chips on here must meet one requirement: Supports an external FET between battery and Vout

| Name | Voltage | Current | Price | Notes | Link |
| --- | --- | --- | ----- | --- | --- |
| LTC4416 | | | | Can drive 2 supplies | |
| | | | | | |
| bq25060 | | 1 | 1.62  | Nice simple charger design, 1 cell 1 amp | |
| bq25050 | | 1 | 1.65  | Same as 25060 except it has a single input control, and current sense output. | |
| BQ25730 | | | 2.77  | Complex external circuit, supports USB PD. Similar to BQ25700A Needs 5 mosfets. 1-5 cell, and i2c controlled | |
| bq24780S  | | | 2.81  | i2c controlled charger 1-4 cells. Doesn't have power path but instead calls it hybrid power boost. Complex layout, not as bad as BQ25730.  Needs 5 mosfets | |
| bq24600 | | | 2.89  | Very complex with all required external components. 1-6 cell charger. Can't tell if it has power path though | |
| BQ24133 | | | 3.22  | 1-3 cells. Medium complexity circuit Needs 3 mosfets. 2.5 amps charge. Doesn't support battery suplliment | |
| bq24170 | | | 3.36  | 1-3 cell. Medium complexity circuit, needs only 3 mosfets. Virtually identical circuit to BQ24133, except supports higher charge current. | |
| LTC4412 | 2.5-28v | | 4 | Single fet controller (Mimics an Ideal Diode). Can be daisy chained for multiply supples. Very common, and it has lots of potential applications | |
| BQ24725A  | | | 4.22  | I2c controlled charger, supports big power supplies and 1-4 cells. Needs 5 mosfets. Can't be configured in standalone | |
| LTC4088-2 | | | 4.49  | Charges battery and load shares, with external mosfet for battery. downside is its tailored to USB charging at low currents.  It has fixed charge values (100, 500, or 1000mah), and only has one power input. The -1 and -2 variants don't have a 3.3v regulator, but instead have auto charge current reduction, and show the external gate driver as default. For Li-ion, but should be fine for lipo with 4.2 float | |
| LTC4085 | | | 5.38  | Nice charger, similar to 4088. Has support for both wall input and USB. Max charge 1.5 amps. The -3 or -4 variant have a 3.95 float voltage. For Li-ion, but if I get a variant with 4.2 float voltage it should be fine. | |
| LTC4162-L | | | 7.24  | Almost perfect! Supports a variety of power inputs. Only requires 2 mosfets and a lot of inductors. I2c telementary, but not required for control. Power path bit is unclear if it has battery suppliment when the power supply is on. | [Site Unreachable](https://www.digikey.com/en/products/detail/analog-devices-inc/LTC4162EUFD-LAD-PBF/9446106) |
| BQ25750 | | | 8.39  | 1-14 lipo batteries, High voltage and current. Standalone or i2c controlled | |
| bq2477x | | | | 1-4 cell i2c controlled charger | |
| | | | | | |
A lot of the medium complexity circuits have inductors on the power lines, and resistor voltage dividers for all the settings.

Honorable mentions:

| Name | Voltage | Current | Price | Notes | Link |
| --- | --- | --- | ----- | --- | ---- |
| BQ25180 | | | 2.65  | 8 pin BGA package with 1 amp charge current. I2c | |
| LTC1479 | | | 19 | Manages a ton of other power related chips. Too complex | |
| BQ2461x | | | | Supports a lot, but it unfortunately does not prioritize output current | |
| bqTINY  | | | | A series of chips with integrated fets | |

# Battery Chargers
Chargers W/O power path control

| Name | Voltage | Current  | Price | Notes | Link |
| --- | --- | --- | ----- | --- | --- |
| TP4056 | 4.2v | up to 1A | 0.5 | VERY common in chinese battery charging stuff. Seems decent | |
| MCP73871 | 4.2v | 2a | 3 | Nice all around charger and PMIC | [ww1.microchip.com/downloads/en/DeviceDoc/MCP73871-Data-Sheet-20002090E.pdf](https://ww1.microchip.com/downloads/en/DeviceDoc/MCP73871-Data-Sheet-20002090E.pdf) |

# Battery balancers/ protectors 
| Name | Voltage | Current | Price | Notes | Link |
| --- | --- | --- | ----- | --- | ---- |
| BQ76905  | 27 | | 1.85  | 2-5 cell i2c protector, battery balancer and battery monitor (coulomb and voltage). Honestly really good for a BMS | |
| BQ28Z620 | | | | i2c fuel gauge, 1-2 cell, balancing, battery protection. Logic level 1.8v | |
| bq78z100 | | | | Virtually the same as BQ28Z620, except provides HDQ protocol. Has a more limited current resitor range | |
| BQ77307  | | | | 2-7 cell protector, no balancing just measurement | |
| bq298xxx | | | | 1 cell battery protector. | |

# Top Picks 
- LTC4088-2 Most expensive
-  ~~BQ24133~~ Doesn't support DPPM, where output current is prioritized
- bq25060. Single cell, simple
- BQ25730. Most complex. Requires i2c host for settings
- bq24780S. Requires SMbus host for settings. For hybrid boost the input current must be over 1.5 amps
- LTC4162-L Expensive ($7~9), but it only requires two mosfets, and some inductors. Supports i2c telementary, not required. Power path is unclear if the battery can supply current if the system is overloaded, see note.
- BQ24171 (ADD TO LIST) A cheap 2 dollar charger that is stand-alone. Requires 3 mosfets. Switches mode with a 200mV difference

It seems like for anything above 1 cell batteries I have to have a really complex circuit and an additional microchip to control it all. This is frustrating, that I can't find a standalone, cheap, DPPM or Hybrid Boost Mode battery charger chip with external FETs and support for several lipo cells and high amperage.

The ones that require a host also have very low regulator output currents. I mean, seriously 6volts at 13ma?!! I can't run a host very well on that. I did find a low current regulator that could work: TPS62745. The chip I chose for motor power seems to have low current consumption, but I think that would be pushing the limits when the peripheral is enabled. If I have to have a dedicated chip, I may go with the RP2040 to save cost.

**LTC4162-L**
> These drivers make up a dual unidirectional power path system that allows power to be delivered to the system load by either the input supply or the battery, whichever is greater

I think if the system draws too much current the voltage should drop and the system will switch over to the battery. The datasheet says 20mV is the threshold.

# Changelog:
- 2024-05-27 Added battery balancers and protections

See also:
```dataview
LIST
FROM outgoing([[]])
```

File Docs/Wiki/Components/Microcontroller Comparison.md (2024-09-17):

---
aliases: 
tags: 
append_modified_update: true
modified:
  - 2024-04-25T22:05:07-06:00
  - 2024-04-26T18:00:30-06:00
  - 2024-04-27T14:00:19-06:00
  - 2024-06-02T22:10:16-06:00
  - 2024-06-03T14:10:25-06:00
  - 2024-07-05T13:40:14-06:00
---

# Micro-controller Table

| Chip | Voltage  | Current | Indv Price per 10 Qty | Online Rating | PWM | ADC | Price per Motor | Flash/RAM | MHz | Notes | Link |
| --- | --- | --- | --- | --- | --- | --- | --- | --- | --- | --- | --- |
| ATTinyXX | 3.3-5v | | $0.5~$1 | | | | | | | bad budget option, if it is even fast enough. | |
| STM32G474RC  | 1.7-3.3  | | $7.47 | | 52  | 42  | 0.53 | 256/64kb  | 170 | 12 are advanced motor control PWM. Digikey is cheaper. Not all capabilities are exposed in 64 pin package | |
| STM32U073CC  | 1.7-3.3  | | $3.03 | | 16  | 16  | 0.61 | 256/40kb  | 48  | Seem to be in low stock. Low power chip. Very good value | |
| STM32G474RE  | 1.7-3.3  | | $8.78 | | 52  | 42  | 0.63 | 512/128kb | 170 | 12 are advanced motor control PWM. Digikey is cheaper. | |
| stm32g070rb  | 1.7-3.3  | | $2.67 | | 12  | 16  | 0.67 | 128/36kb  | 64  | Similar to other g070. Very good value. Rb is the highest pin count at 64 | |
| STM32G071R8  | 1.7-3.3  | | $3.57 | | 16  | 16  | 0.71 | 64/36kb | 64  | Its confusing with the PWM, as they have many different timers that have different channel amounts. Can have 5 | |
| STM32F072R8  | 1.7-3.3  | | $3.53 | | 16  | 16  | 0.71 | 64/16kb | 48  | | |
| ATSAMD51P20A | 1.7-3.3v | | $8.1 | | 40  | 32  | 0.81 | 128kb | 120 | 15 ADC, 22 PWM, on Adafruit Grand central. In datasheet it can go upto 32 ADC, 40 PWM. This is a beast that could support 5 motors or 10 with bare chip | |
| STM32G071RB  | 1.7-3.3  | | $4.11 | | 16  | 16  | 0.82 | 128/36kb  | 64  | | |
| STM32G473RB  | | | $6.77 | | 24  | 42  | 0.85 | 128kb | 170 | 12 are advanced motor timers. Has usb controller | |
| STM32G0B1RB  | | | $5.17 | | 20  | 16  | 1.03 or 0.86 | 128/144kb | 64  | Mouser. same as other 0b1 | |
| STM32G0B1RC  | 1.7-3.3  | | $5.2 | | 20  | 16  | 1.04, or 0.87 | 256/144kb | 64  | Interesting upgrade to the other G0x1s. Can have 5 motors, unless you drop a current sense line . USB c controller built in. | |
| STM32L412RB  | 1.7-3.3v | | $4.55 | | 11  | 16  | 1.52 | | 80  | Low power chip | [Site Unreachable](https://www.mouser.com/ProductDetail/STMicroelectronics/STM32L412RBT6P?qs=l7cgNqFNU1hh%252BU1wOZs5Xg%3D%3D) |
| Esp32-s3F8 | | | $2.28 | | 12  | | 0.46 | | | Supports running pwm on ANY pin using MCPWM, and has several adcs. Up to 4 motors. This has 8mb flash | |
| | | | | | | | | | | | |
## Notes
The STM 32 G0x1 series seems to be the best budget option for chips, and most 64 pin chips have enough outputs to drive 4-5 motors. Cortex M0. $3.5~6

The price is higher for STM32 G4XXX, only the lowest option is 3.95 for 64 pin. This is good if I can operate a lot of motors.

Each motor needs 3 pwm out, and 3 adc lines for current sensing. Another unspecified requirement are pins for encoders, which I have not figured out. I will most likely be doing a 3d hall effect sensor over i2c or spi. You can drop a current sense line, but I don't know the performance impact.

All chips on the table have at least one SPI port. I have not identified which chips are easier to set up however.

Most chips are qfn 64, and 32 bit. I have not checked if all the outputs listed are available in that package format

STM32 chips are well supported in Simple FOC.

**My current choice:** stm32g070cb. **Reasons:** Supports 4 motors w/ simple config tweak, $0.64 a motor, supports a cheaper clock type, same size as 32 pin packages.

# Top Picks
- STM32G071RB
- STM32G0B1RC 
- stm32g070cb
- STM32U073CC
- STM32G474RC
- STM32G473RB
- ESP32-S3 with built in flash

## Findings from using STM-32 Cube MX for pin configs.
Note that cost is still per 10 units.

### STM32G071KB 
- 32 pin package 
- Max 10 ADC
- Max 10 PWM
- 1 i2c, 1 spi, 1 swd
- 2 extra gpio.
- Cost 2.85 Mouser
- 3 motors, 0.95 per motor
- 
### STM32G071RB 
- 64 pin package 
- Max 12 ADC
- Max 17 PWM
- All comms are able to run with this 2 i2c and 2 spi. USB is not on this chip.
- Cost 4.11
- 4 motors, 1.03 per motor

### STM32G0B1KC 
- 32 pin package, no leads.
- Max 9 ADC
- Max 9 PWM
- 1 i2c, 1 spi, 1 usb, and 1 SWD
- 3 extra GPIO, BOOT0 is conflicting. This is a very dense layout.
- cost $4.63. KB is 4.18, 1.39 a motor
- 3 motors, $1.54 a motor. Expensive with 256 kb flash, a little smaller package, USB capability and other features I don't need.
- DO NOT GET THE N version. It is impossible to get all outputs.
![[STM32G0B1KCUx.jpg|400]]
### STM32G0B1RC 
- 64 pin package 
- Max 12 ADC
- Max 21 PWM
- All comms are available except USB pwr delivery.
- Has USB-C pwr delivery and USB.
- cost $5.2
- 4 motors, $1.3 a motor

### stm32g070kb.
- 32 pin package 
- 9 ADC
- 10 PWM
- 1 I2c and 1 SPI, no usb, 1 SWD
- 3 GPIO pin free
- Cost $1.89
- 3 motors, $0.63 a motor
![[STM32G070KB.jpg|400]]

### stm32g070cb GOOD DEAL W/O USB
![[STM32G070CB.jpg|400]]
- 48 pin package 
- Max 12 adc
- Max 12 PWM (10w/o the config change below)
- All comms are available. No usb
- Cost $2.57
- 4 motor, $0.64 PPM (old: 3 motor support, $0.89 a motor)
- There is a confusing setting in STMCube MX called Sequencer. If this is set to not fully configurable, then two more ADC pins appear, and I can rearrange stuff to get 12 pwm pins. PPM would then be $0.64! Reading online forums it appears that the only thing that would change is setting different sampling rates for different channels, which I don't care about.
- This package is the same size as KB, except with finer pitch.
- Combined with a cheaper clock (Since I now have OSC in and out), I could actually save quite a few dimes!
UPDATE: With simplefoc you can only run 3 motors because not all timers support syncing. Also, the price changed to $2.01 !! That means it is $0.67 a motor

### stm32g070rb 
- 64 pin package 
- Max 12 adc
- Max 13 PWM
- All comms are available. No usb
- Cost $2.67
- 4 motor support, $0.67 a motor

### STM32U073CC 
- 48 pin package 
- Max 8 ADC pins
- Max of 14 PWM pins (Don't do N channels, which eliminates all communication interfaces besides SWD
- I can disable output from TIM1_CH4 to get USB, and TIM16_CH1 to get I2C1.
- I can disable TIM2_CH2, TIM3_CH1, and TIM3_CH2 to get SPI1.
- That leaves me with 9 PWM
- The ADC pins and the PWM pins stay in separate areas, broken up by communication interfaces
- cost ~~$3.03~~ $3.37
- 2 motors max, ~~$1.52~~ $1.69 a motor. Not a good deal. The 32 pin version also has 8 adc ports

UPDATE: I got it to 3 motors, which is $1.12 a motor.

### STM32U073RC. GOOD DEAL, Lot of space
- 64 pin package 
- Max 12 ADC pins
- Max 15 PWM pins
- 3 I2c and 2 SPI buses are available without disabling other pins, but USB needs TIM1_CH4 disabled like above.
- Cost $3.11
- 4 motors, $0.78

### STM32G474RC. BIG BOY
- Max 26 ADC
- Max 29 PWM
- Not all ADC and PWM can be on at once, and I need other communication interfaces. 
- If I enable USB, SPI3 and I2C1, and all other pins in various configurations, then I could have 20 ADC and 20 PWM. 
- Cost $7.47
- 6 motors a chip, $1.25 a motor. Not the best deal.
- It reduces the amount of chips, but I'm not sure about actual space savings because LQFP64 is 10mm x 10mm chip, vs 7mm of a LQFP48.

Config:
![[STM32G474RC.jpg|400]]

### STM32G473CB
- 48 pin
- Cost $6 per 10 at digikey
- Max 20 ADC
- Max 27 PWM
- Similar to above, it needs some playing around. With one usb, SPI, and I2c, I can have 13 ADC, and 14 PWM. This maximizes most of the pins
- 4 motors, $1.5 per motor, expensive
Config:
![[STM32G473CB.jpg|400]]

### ESP32-S3 

Yes, this is not an stm32 product. But it is still a top pick due to the price and capability
- 240 mhz dual core
- 12 pwm all through a dedicated motor interface 
- $2.28, $0.57 a motor
- 20 channels and two adcs
- Side note that it has fewer strapped pins than the original esp32
- I2c, spi, and USB.
- Very particular on some pins about behavior.

Helpful website for finding what all the pins do on power up, reset, etc... [Schematic Checklist - ESP32-S3 - — ESP Hardware Design Guidelines latest documentation](https://docs.espressif.com/projects/esp-hardware-design-guidelines/en/latest/esp32s3/schematic-checklist.html)

Specifics: I need to use pins all on the same adc for Simplefoc

# Changelog:
- Migrated microcontrollers to this file from [[Motor Driver Comparison]]
- Reconsidered STM32G070cb as an option, with a simple config change I now get a better clock source option and 4 motor support.
- 2024-06-02 Added ESP32-S3 option

See also:
```dataview
LIST
FROM outgoing([[]])
```

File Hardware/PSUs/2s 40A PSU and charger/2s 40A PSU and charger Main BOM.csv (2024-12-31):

Id | Designator | Footprint | Quantity | Designation | Supplier and ref
1 | R14 | R_2512_6332Metric_6W | 1 | 1mOhm, 6W
2 | R18 | R_Vishay_2818 | 1 | 5mOhm, 10W, 2818
3 | C9,C23,C10,C21,C11,C22,C32,C25,C4,C3 | C_0402_1005Metric | 10 | 100nF, 16v
4 | D11 | CDDFN103324P | 1 | CDDFN10-3324P
5 | R24,R20,R23,R29,R11 | R_0402_1005Metric | 5 | 10k
6 | R10,R8,R7 | R_0402_1005Metric | 3 | 4.02k
7 | C20,C12,C7,C14 | C_0805_2012Metric | 4 | 10uF, 16v
8 | R1 | R_1206_3216Metric | 1 | 10mOhm, 1W
9 | Q1,Q5,Q4,Q2 | SC-59 | 4 | PJA3430, or HL 2320A
10 | D1,D3,D2 | D_0402_1005Metric | 3 | GSDH3005
11 | R19,R6,R33 | R_0402_1005Metric | 3 | 5.1k
12 | C2,C24 | C_0603_1608Metric | 2 | 2.2uf, 16v
13 | R25 | R_0402_1005Metric | 1 | 80.6 ohm
14 | C5 | C_0402_1005Metric | 1 | 1nF, 16v
15 | J3,J1,J7,J6 | Keystone_3579 | 4 | Keystone 3579
16 | R3,R5,R4 | R_0402_1005Metric | 3 | 100ohm
17 | L2 | L_Bourns_SDR0604 | 1 | 6.8uH HPC HPC5040NF-6R8M
18 | J2 | JST_XH_S3B-XH-A_1x03_P2.50mm_Horizontal | 1 | JST XH-S Balance Plug
19 | J5,J4,J8,J9 | Keystone_3569_half | 4 | Keystone 3569
20 | J11 | PinSocket_1x04_P1.27mm_Vertical | 1 | 1.27mm 4 pin socket
21 | R2 | R_0805_2012Metric | 1 | 2ohm
22 | R21,R12,R22,R16,R17,R15 | R_0402_1005Metric | 6 | 10ohm
23 | D4 | LED_0603_1608Metric_Pad1.05x0.95mm_HandSolder | 1 | 2.6~3.1 Fv Green 5ma
24 | Q3,Q6 | PQFN-8-EP_6x5mm_P1.27mm_Generic | 2 | Vishay sir404dp, or SiR500DP
25 | U3 | RUY0028A | 1 | BQ24780SRUYR
26 | C6,C17 | C_0603_1608Metric | 2 | 47nF, 16v
27 | J10 | USB_C_G-Switch_GT-USB-7025-JLCPCBv | 1 | G-Switch-GT-USB-7025
28 | R30,R31 | R_0402_1005Metric | 2 | 866k
29 | U7 | WSON-6-1EP_2x2mm_P0.65mm_EP1x1.6mm | 1 | TPS7A2633DRV
30 | R26,R27,R28 | R_0402_1005Metric | 3 | 120 ohm
31 | C15 | C_0402_1005Metric | 1 | 1uf, 16v
32 | C28,C27 | C_1206_3216Metric | 2 | 22uf, 16v CL31A226MOCLNN
33 | C31 | C_0603_1608Metric | 1 | 10uF, 16v
34 | C40 | C_0603_1608Metric | 1 | 100nF, 16v
35 | U5 | SOT-583-8 | 1 | THVD1420DRLR
36 | C13,C19,C18 | C_0402_1005Metric | 3 | 220nF, 16v
37 | L3 | L_1008_2520Metric | 1 | 2.2uH, WIP322512A-2R2MLDG
38 | C30,C29 | C_0402_1005Metric | 2 | 100pF
39 | C33 | C_0402_1005Metric | 1 | 2.2uF, 16v
40 | U1 | VQFN20_RGR_TEX | 1 | BQ76905RGRR
41 | U6 | QFN-28-1EP_4x4mm_P0.4mm_EP2.8x2.8mm | 1 | CH32X035G8U6
42 | R9 | R_0805_2012Metric | 1 | 10ohm
43 | U2 | TSOT-23-6 | 1 | AP63203WU
44 | C26 | C_0603_1608Metric | 1 | 4.7uF, 16v

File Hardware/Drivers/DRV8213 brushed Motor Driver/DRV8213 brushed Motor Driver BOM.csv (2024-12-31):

Id | Designator | Footprint | Quantity | Designation | Supplier and ref
1 | J3,J2,J7,J6 | Keystone_3579 | 4 | Keystone 3579
2 | J4,J1,J8,J5 | Keystone_3569_half | 4 | Keystone 3569
3 | C6,C8 | C_0402_1005Metric | 2 | 100nF, 16v
4 | J11,J10 | PinHeader_1x03_P1.27mm_Horizontal | 2 | 1.27mm pin header
5 | C7,C1,C4,C5,C3,C2 | C_0603_1608Metric | 6 | 10uF, 16v
6 | J9 | JST_PH_S2B-PH-K_1x02_P2.00mm_Horizontal | 1 | JST PH 2mm horizontal
7 | U1 | WQFN-16-1EP_3x3mm_P0.5mm_EP1.68x1.68mm_ThermalVias | 1 | DRV8213RTER
8 | C9 | C_0402_1005Metric | 1 | 2.2uF, 10v
9 | R2 | R_0402_1005Metric | 1 | 3.3k
10 | U2 | SOT-23-5 | 1 | LP2981-3.3
11 | R1 | R_0402_1005Metric | 1 | 10k

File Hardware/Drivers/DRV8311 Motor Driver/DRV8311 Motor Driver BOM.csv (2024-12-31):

Id | Designator | Footprint | Quantity | Designation | Supplier and ref
1 | J7,J9,J3,J11 | Keystone_3579 | 4 | Keystone 3579
2 | J4 | Molex_PicoBlade_53048-0310_1x03_P1.25mm_Horizontal | 1 | Molex Picoblade
3 | C1 | C_0402_1005Metric | 1 | 4.7uF, 10v
4 | U1 | DRV8311_0.3mmVias | 1 | DRV8311HRRWR
5 | J8,J6,J10,J5 | Keystone_3569_half | 4 | Keystone 3569
6 | C6,C2 | C_0603_1608Metric | 2 | 100nF, 16v
7 | J2,J1 | PinHeader_1x03_P1.27mm_Horizontal | 2 | 1.27mm pin header
8 | C7,C3 | C_0402_1005Metric | 2 | 100nF, 16v
9 | R1 | R_0402_1005Metric | 1 | 300k
10 | C4,C9,C10,C8,C5 | C_0603_1608Metric | 5 | 10uF, 16v
11 | R3 | R_0402_1005Metric | 1 | 47k
12 | R2 | R_0402_1005Metric | 1 | 100k

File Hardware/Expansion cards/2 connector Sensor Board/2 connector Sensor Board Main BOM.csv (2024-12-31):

Id | Designator | Footprint | Quantity | Designation | Supplier and ref
1 | J1 | PinHeader_1x05_P1.27mm_Vertical | 1 | SPI
2 | J7 | JST_SH_SM04B-SRSS-TB_1x04-1MP_P1.00mm_Horizontal | 1 | JST SH
3 | R2,R4 | R_0402_1005Metric | 2 | 10k
4 | J3 | PinHeader_1x04_P1.27mm_Vertical | 1 | free pins
5 | J2,J5 | fpc_7pin_0.3mm_connector Panasonic | 2 | 7 pin FPC 0.3mm Panasonic Y3b
6 | J4,J15 | TE_mezzanine_conn_3-2363962-0 | 2 | TE 3-2363962-0 Connector

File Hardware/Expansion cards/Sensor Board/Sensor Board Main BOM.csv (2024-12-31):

Id | Designator | Footprint | Quantity | Designation | Supplier and ref
1 | J1 | PinHeader_1x05_P1.27mm_Vertical | 1 | SPI
2 | J7 | JST_SH_SM04B-SRSS-TB_1x04-1MP_P1.00mm_Horizontal | 1 | JST SH
3 | J3 | PinHeader_1x03_P1.27mm_Vertical | 1 | free pins
4 | J2,J5 | fpc_7pin_0.3mm_connector Panasonic | 2 | 7 pin FPC 0.3mm Panasonic Y3b
5 | R2,R4 | R_0603_1608Metric | 2 | 10k
6 | J15 | TE_mezzanine_conn_3-2363962-0 | 1 | TE 3-2363962-0 Connector

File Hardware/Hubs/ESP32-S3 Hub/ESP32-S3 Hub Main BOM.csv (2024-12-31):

Id | Designator | Footprint | Quantity | Designation | Supplier and ref
1 | D1 | LED_0603_1608Metric_Pad1.05x0.95mm_HandSolder | 1 | 2.6~3.1 Fv Green 5ma
2 | J22 | PinHeader_1x04_P1.27mm_Horizontal | 1 | 1.27mm 4 pin header
3 | C13,C9,C2,C7 | C_0402_1005Metric | 4 | 1uF
4 | C10,C4,C6,C8,C5,C3 | C_0402_1005Metric | 6 | 0.1uF
5 | R8,R9,R7,R20,R19,R11,R18,R2 | R_0402_1005Metric | 8 | 10k
6 | J10,J6,J2,J1,J7,J12,J4,J9 | PinHeader_1x03_P1.27mm_Vertical | 8 | 1.27mm 3pin socket
7 | C12,C11 | C_0402_1005Metric | 2 | 12pF
8 | SW2,SW1 | R-667995_MIT | 2 | Mitsumi R-667996
9 | Y1 | Crystal_SMD_2016-4Pin_2.0x1.6mm | 1 | ABM11-40.000MHZ-B1U-T3, 10ppm, 10pF
10 | FB1 | L_0402_1005Metric | 1 | 120ohm imp @100mhz, 1 amp
11 | U1 | QFN-56-1EP_7x7mm_P0.4mm_EP4x4mm | 1 | ESP32-S3
12 | J16,J13 | TE_mezzanine_rec_3-2363961-0 | 2 | TE 3-2363961-0 receptacle
13 | J21 | PinSocket_1x04_P1.27mm_Vertical | 1 | 1.27mm 4 pin socket
14 | R6 | R_0402_1005Metric | 1 | 22 ohm
15 | R1 | R_0402_1005Metric | 1 | 100k
16 | R10 | R_0402_1005Metric | 1 | 80.6 ohm
17 | C1,C14 | C_0402_1005Metric | 2 | 22uF
18 | U2 | DHVQFN-16-1EP_2.5x3.5mm_P0.5mm_EP1x2mm | 1 | 74HC595
19 | R3,R4,R5 | R_0402_1005Metric | 3 | 33ohm
20 | J14,J17 | TE_mezzanine_conn_3-2363962-0 | 2 | TE 3-2363962-0 Connector
21 | J11,J8,J5,J3 | fpc_7pin_0.3mm_connector Panasonic | 4 | 7 pin FPC 0.3mm Panasonic Y3b
22 | U3 | SOT-583-8 | 1 | THVD1420DRLR

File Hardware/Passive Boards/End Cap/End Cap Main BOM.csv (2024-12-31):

Id | Designator | Footprint | Quantity | Designation | Supplier and ref
1 | J1 | PinHeader_1x04_P1.27mm_Vertical | 1 | 1.27mm 4 pin header
2 | J3,J7,J5,J9 | Keystone_3569_half | 4 | Keystone 3569
3 | J2,J6,J4,J8 | Keystone_3579 | 4 | Keystone 3579
4 | TP3 | TestPoint_Pad_D1.0mm | 1 | 3.3v
5 | R1 | R_0402_1005Metric | 1 | 120ohm
6 | TP4 | TestPoint_Pad_D1.0mm | 1 | GND

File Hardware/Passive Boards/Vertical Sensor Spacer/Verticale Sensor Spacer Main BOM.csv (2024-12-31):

Id | Designator | Footprint | Quantity | Designation | Supplier and ref
1 | J1 | TE_mezzanine_rec_3-2363961-0 | 1 | TE 3-2363961-0 Connector
2 | J15 | TE_mezzanine_conn_3-2363962-0 | 1 | TE 3-2363962-0 Connector

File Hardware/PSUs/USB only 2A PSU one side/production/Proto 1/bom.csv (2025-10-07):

Designator | Footprint | Quantity | Value | LCSC Part #
C1, C31 | 0805 | 2 | 10uF, 16v | C96446
C2, C27, C28, C3 | 1206 | 4 | 22uf, 16v CL31A226MOCLNN | C159758
C32, C5 | 0805 | 2 | 100nF, 16v | C1525
C33 | 0805 | 1 | 2.2uF, 16v | C12530
C4, C40 | 0805 | 2 | 100nF, 16v | C14663
C6 | 0805 | 1 | 4.7uF, 16v | C19666
C7 | 0805 | 1 | 10uF, 16v | C15850
D11 | CDDFN103324P | 1 | CDDFN10-3324P | C913227
D3 | 0402 | 1 | GSDH3005 | C2837790
D4 | 0603 | 1 | 2.6~3.1 Fv Green 5ma | C3028858
J1 | PinHeader_2x02_P1.27mm_Horizontal | 1 | Precidip 853-87-004-20-001101
J10 | USB_C_G-Switch_GT-USB-7025-JLCPCBv | 1 | G-Switch-GT-USB-7025 | C963213
L3 | 1008 | 1 | 2.2uH, WIP322512A-2R2MLDG | C5832372
Q1, Q2 | SC-59 | 2 | PJA3430, or HL 2320A
R1 | 2512 | 1 | 50mOhm
R19, R33 | 0805 | 2 | 5.1k | C25905
R2 | 0805 | 1 | 2ohm | C17521
R25 | 0805 | 1 | 80.6 ohm | C185392
R26, R27, R28 | 0805 | 3 | 120 ohm | C25079
R3, R4 | 0805 | 2 | 10k | C25744
R9 | 0805 | 1 | 10ohm | C17415
U1 | SOT-23-5 | 1 | FAN3111E
U2 | TSOT-23-6 | 1 | AP63203WU | C780769
U3 | SOT-23-8 | 1 | INA219AxDCN
U4 | QFN-28-1EP_4x4mm_P0.4mm_EP2.8x2.8mm | 1 | CH32X035G8U6 | C7437027
U5 | SOT-583-8 | 1 | THVD1420DRLR
U7 | WSON-6-1EP_2x2mm_P0.65mm_EP1x1.6mm | 1 | TPS7A2633DRV | C2876256

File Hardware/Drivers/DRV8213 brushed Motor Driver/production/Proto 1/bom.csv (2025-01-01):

Designator | Footprint | Quantity | Value | LCSC Part #
C1, C2, C3, C4, C5, C7 | 0603 | 6 | 10uF, 16v | C96446
C6, C8 | 0402 | 2 | 100nF, 16v | C1525
C9 | 0402 | 1 | 2.2uF, 10v | C12530
J9 | JST_PH_S2B-PH-K_1x02_P2.00mm_Horizontal | 1 | JST PH 2mm horizontal | C160237
R1 | 0402 | 1 | 10k | C25744
R2 | 0402 | 1 | 3.3k | C25890
U2 | SOT-23-5 | 1 | LP2981-3.3 | C129997

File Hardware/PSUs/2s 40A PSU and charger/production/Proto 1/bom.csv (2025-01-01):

Designator | Footprint | Quantity | Value | LCSC Part #
C10, C11, C21, C22, C23, C25, C3, C32, C4, C9 | 0402 | 10 | 100nF, 16v | C1525
C12, C14, C20, C7 | 0805 | 4 | 10uF, 16v | C15850
C13, C18, C19 | 0402 | 3 | 220nF, 16v | C16772
C15 | 0402 | 1 | 1uf, 16v | C52923
C17, C6 | 0603 | 2 | 47nF, 16v | C1622
C2, C24 | 0603 | 2 | 2.2uf, 16v | C23630
C26 | 0603 | 1 | 4.7uF, 16v | C19666
C27, C28 | 1206 | 2 | 22uf, 16v CL31A226MOCLNN | C159758
C29, C30 | 0402 | 2 | 100pF | C1546
C31 | 0603 | 1 | 10uF, 16v | C96446
C33 | 0402 | 1 | 2.2uF, 16v | C12530
C40 | 0603 | 1 | 100nF, 16v | C14663
C5 | 0402 | 1 | 1nF, 16v | C1523
D1, D2, D3 | 0402 | 3 | GSDH3005 | C2837790
D11 | CDDFN103324P | 1 | CDDFN10-3324P | C913227
D4 | 0603 | 1 | 2.6~3.1 Fv Green 5ma | C3028858
J10 | USB_C_G-Switch_GT-USB-7025-JLCPCBv | 1 | G-Switch-GT-USB-7025 | C963213
L2 | L_Bourns_SDR0604 | 1 | 6.8uH HPC HPC5040NF-6R8M | C357072
L3 | 1008 | 1 | 2.2uH, WIP322512A-2R2MLDG | C5832372
Q1, Q2, Q4, Q5 | SC-59 | 4 | PJA3430, or HL 2320A | C7437078
Q3, Q6 | PQFN-8-EP_6x5mm_P1.27mm_Generic | 2 | Vishay sir404dp, or SiR500DP | C3289487
R1 | 1206 | 1 | 10mOhm, 1W | C473031
R10, R7, R8 | 0402 | 3 | 4.02k | C43251
R11, R20, R23, R24, R29 | 0402 | 5 | 10k | C25744
R12, R15, R16, R17, R21, R22 | 0402 | 6 | 10ohm | C25077
R14 | 2512 | 1 | 1mOhm, 6W | C19270875
R18 | R_Vishay_2818 | 1 | 5mOhm, 10W, 2818 | C2090564
R19, R33, R6 | 0402 | 3 | 5.1k | C25905
R2 | 0805 | 1 | 2ohm | C17521
R25 | 0402 | 1 | 80.6 ohm | C185392
R26, R27, R28 | 0402 | 3 | 120 ohm | C25079
R3, R4, R5 | 0402 | 3 | 100ohm | C25076
R30, R31 | 0402 | 2 | 866k | C137931
R9 | 0805 | 1 | 10ohm | C17415
U1 | VQFN20_RGR_TEX | 1 | BQ76905RGRR | C22394458
U2 | TSOT-23-6 | 1 | AP63203WU | C780769
U3 | RUY0028A | 1 | BQ24780SRUYR
U6 | QFN-28-1EP_4x4mm_P0.4mm_EP2.8x2.8mm | 1 | CH32X035G8U6 | C7437027
U7 | WSON-6-1EP_2x2mm_P0.65mm_EP1x1.6mm | 1 | TPS7A2633DRV | C2876256

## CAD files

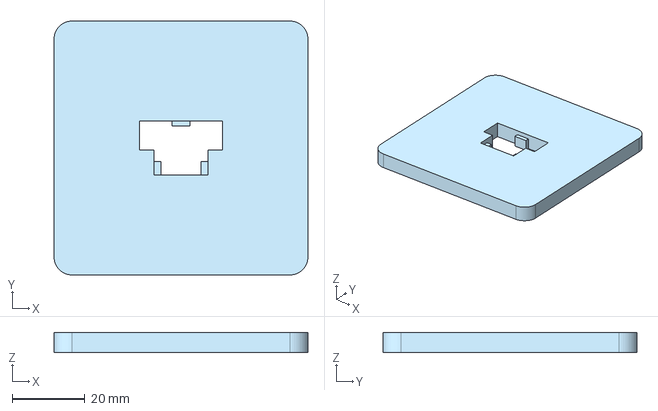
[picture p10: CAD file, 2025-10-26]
Hardware/Assembly Jigs/DRV8213 2nd side Stencil Jig.step
70.0 x 70.0 x 5.60 mm

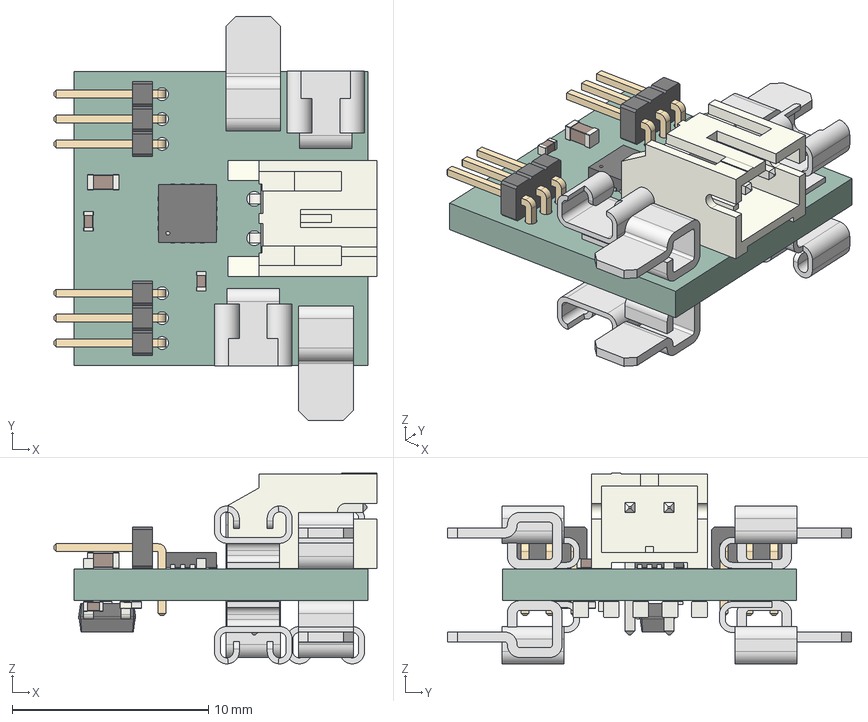
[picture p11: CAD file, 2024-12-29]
Hardware/Drivers/DRV8213 brushed Motor Driver/DRV8213 brushed Motor Driver.step
16.4 x 20.6 x 9.73 mm
Keystone 3579 x 4
Keystone 3569 half x 4
C_0402_1005Metric x 3
PinHeader_1x03_P127mm_Horizontal x 2
C_0603_1608Metric x 6
JST_S2B_PH_K
WQFN_16_1EP_3x3mm_P05mm_EP16x16mm
R_0402_1005Metric x 2
SOT_23_5
DRV8213 brushed Motor Driver_PCB

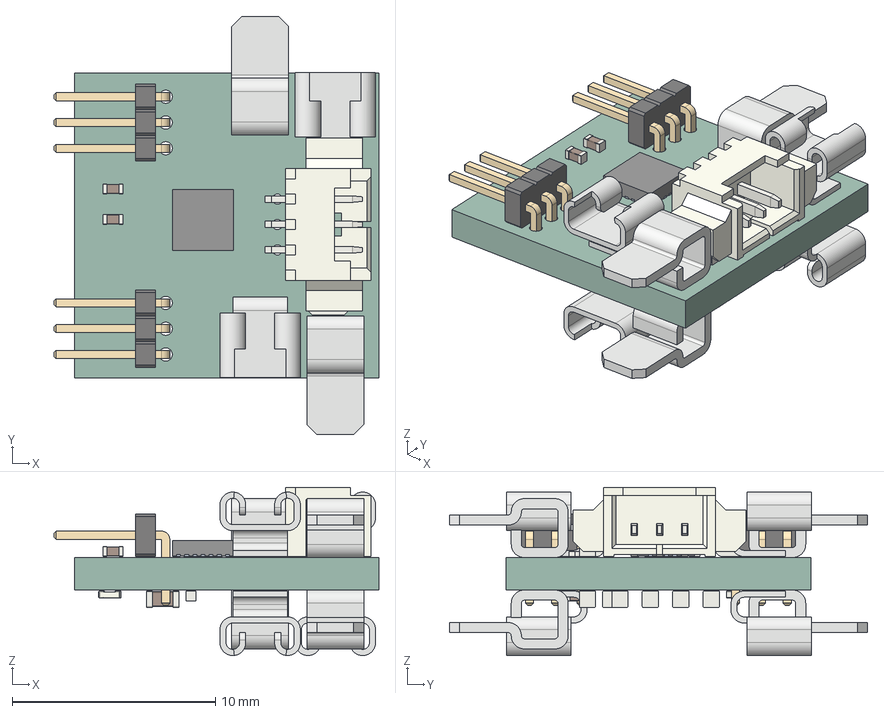
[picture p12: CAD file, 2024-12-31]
Hardware/Drivers/DRV8311 Motor Driver/DRV8311 Motor Driver.step
16.0 x 20.6 x 8.28 mm
Keystone 3579 x 4
Molex_53261_0371
C_0402_1005Metric x 3
RRW0024A_ASM
Keystone 3569 half x 4
C_0603_1608Metric x 7
PinHeader_1x03_P127mm_Horizontal x 2
R_0402_1005Metric x 3
DRV8311 Motor Driver_PCB

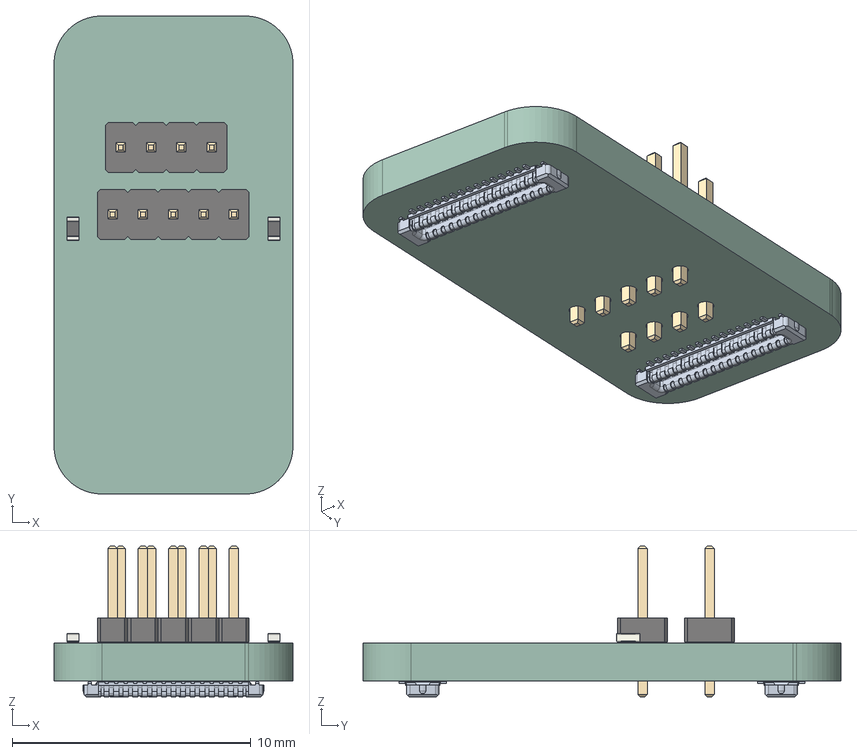
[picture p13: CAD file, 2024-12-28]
Hardware/Expansion cards/2 connector Sensor Board/2 connector Sensor Board.step
10.0 x 20.0 x 6.30 mm
PinHeader_1x05_P127mm_Vertical
R_0402_1005Metric x 2
PinHeader_1x04_P127mm_Vertical
C-3-2363962-0 x 2
2 connector Sensor Board_PCB

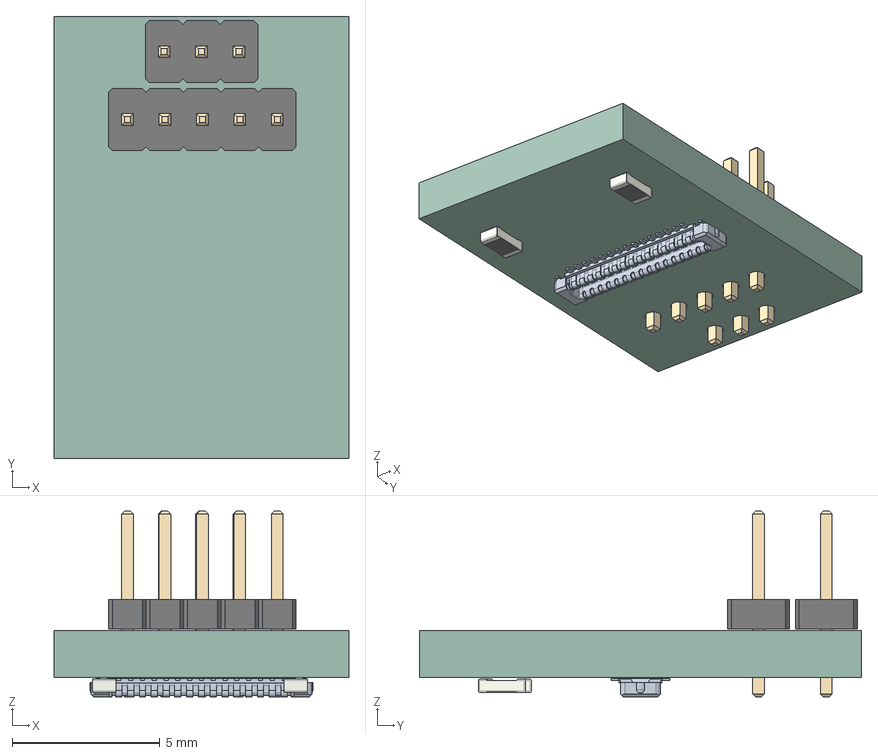
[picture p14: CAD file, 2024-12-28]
Hardware/Expansion cards/Sensor Board/Sensor Board.step
10.0 x 15.0 x 6.30 mm
PinHeader_1x05_P127mm_Vertical
PinHeader_1x03_P127mm_Vertical
R_0603_1608Metric x 2
C-3-2363962-0
_autosave-Sensor Board_PCB

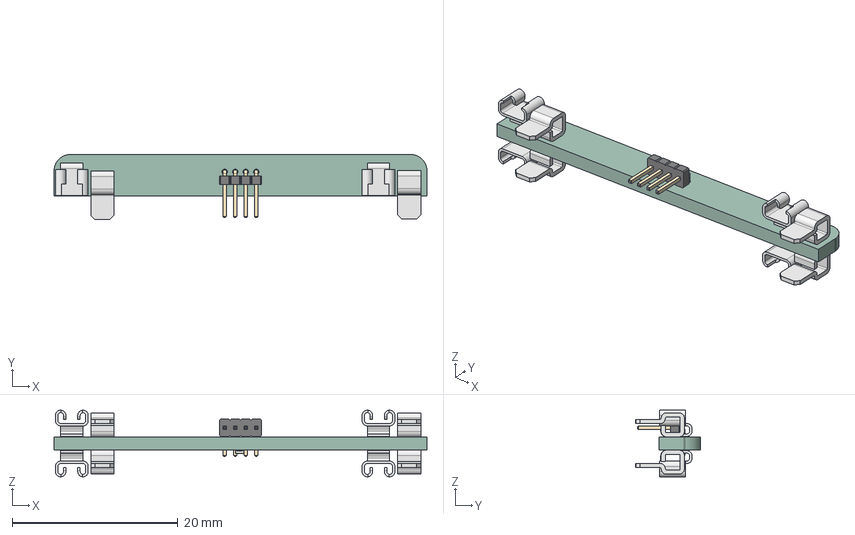
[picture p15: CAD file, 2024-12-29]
Hardware/Passive Boards/End Cap/End Cap.step
45.0 x 7.85 x 8.05 mm
PinHeader_1x04_P127mm_Horizontal
Keystone 3569 half x 4
Keystone 3579 x 4
R_0402_1005Metric
End Cap_PCB

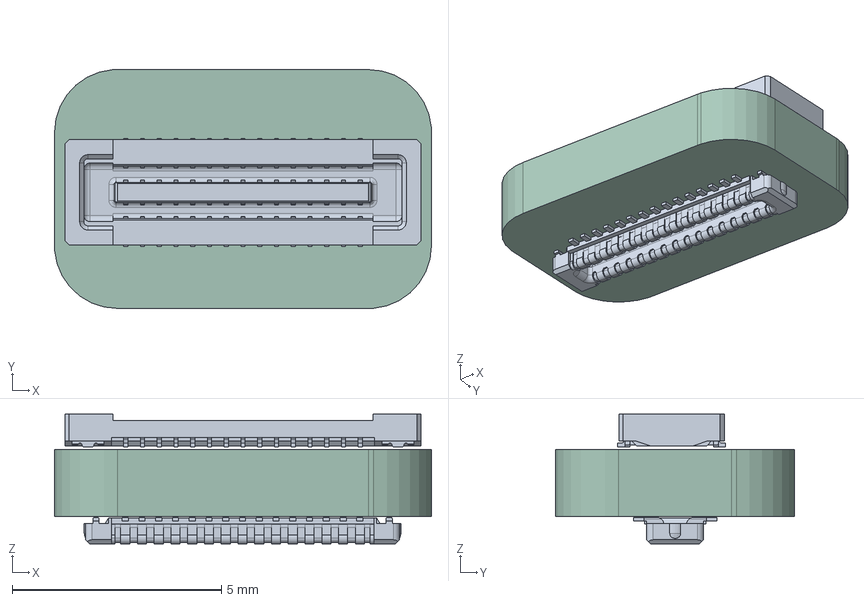
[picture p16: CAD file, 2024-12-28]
Hardware/Passive Boards/Vertical Sensor Spacer/Verticale Sensor Spacer.step
9.00 x 5.70 x 3.10 mm
C-3-2363961-0
C-3-2363962-0
Verticale Sensor Spacer_PCB

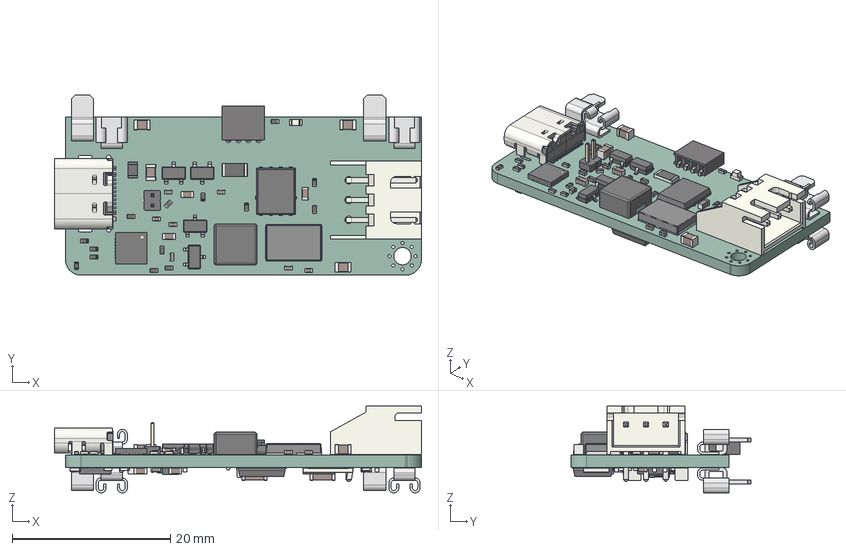
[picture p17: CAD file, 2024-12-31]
Hardware/PSUs/2s 40A PSU and charger/2s 40A PSU and charger.step
46.4 x 22.8 x 11.0 mm
C_0402_1005Metric x 18
R_0402_1005Metric x 26
C_0805_2012Metric x 4
R_1206_3216Metric
SC_59 x 4
C_0603_1608Metric x 7
Keystone 3579 x 4
WSHM2818
CQ assembly
JST_S3B_XH_A
Keystone 3569 half x 4
BD090-04-A-L-G
R_0805_2012Metric x 2
PinHeader_1x02_P127mm_Vertical
LED_0603_1608Metric
Vishay_PowerPAK_SO-8 x 2
QFN-28-1EP_4x4mm_Pitch0.4mm x 2
USB_C_Receptacle_16P_TopMnt_Horizontal_GCT_USB4105-xx-A
WSON_6_1EP_2x2mm_P065mm_EP1x16mm
C_1206_3216Metric x 2
SOT_563
L_1008_2520Metric
R_2512_6332Metric
QFN-20-1EP_4x4mm_Pitch0.5mm
TSOT_23_6
_autosave-2s 40A PSU and charger_PCB

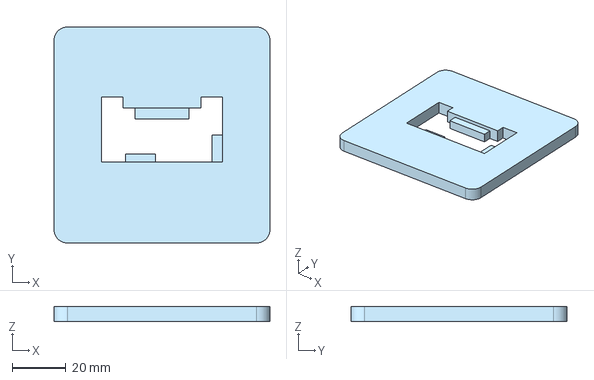
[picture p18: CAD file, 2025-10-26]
Hardware/Assembly Jigs/2s 40amp PSU 2nd side Stencil Jig.step
80.0 x 80.0 x 5.60 mm

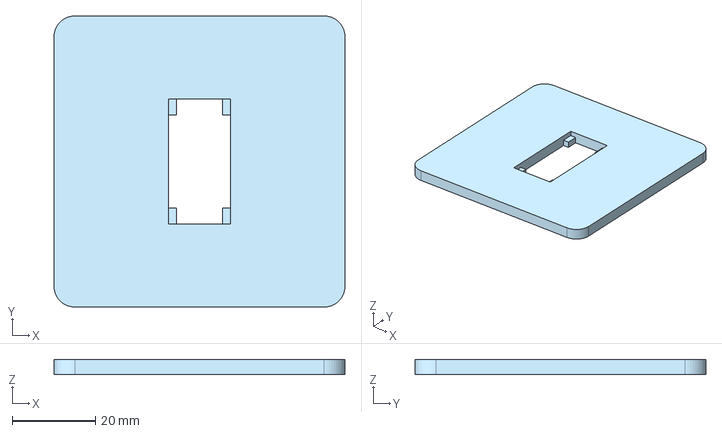
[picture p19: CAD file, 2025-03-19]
Hardware/Assembly Jigs/ESP32-S3 2nd side Stencil Jig.step
70.0 x 70.0 x 3.60 mm

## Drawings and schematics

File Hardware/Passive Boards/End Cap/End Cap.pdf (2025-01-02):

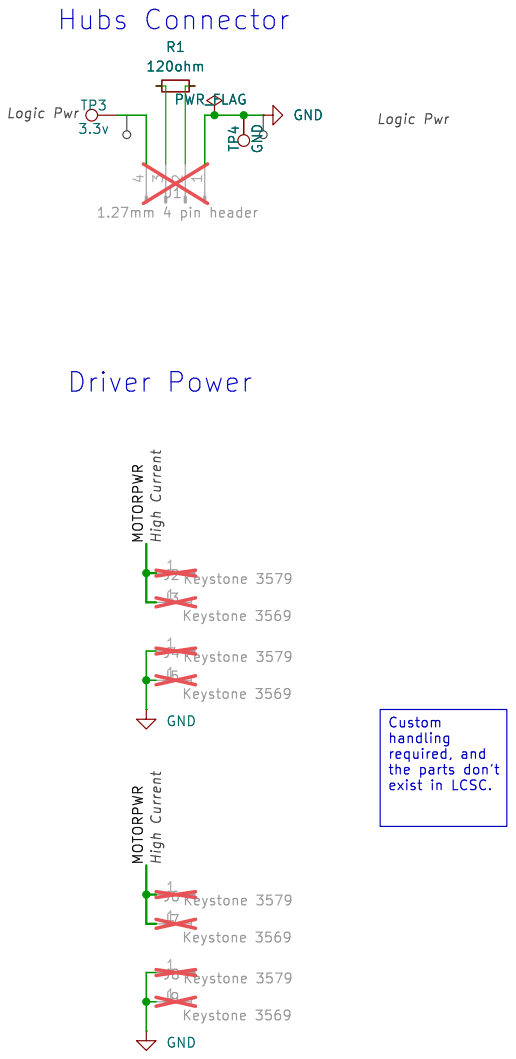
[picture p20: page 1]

Id: 1/1 Title: CACKLE Blank End Cap

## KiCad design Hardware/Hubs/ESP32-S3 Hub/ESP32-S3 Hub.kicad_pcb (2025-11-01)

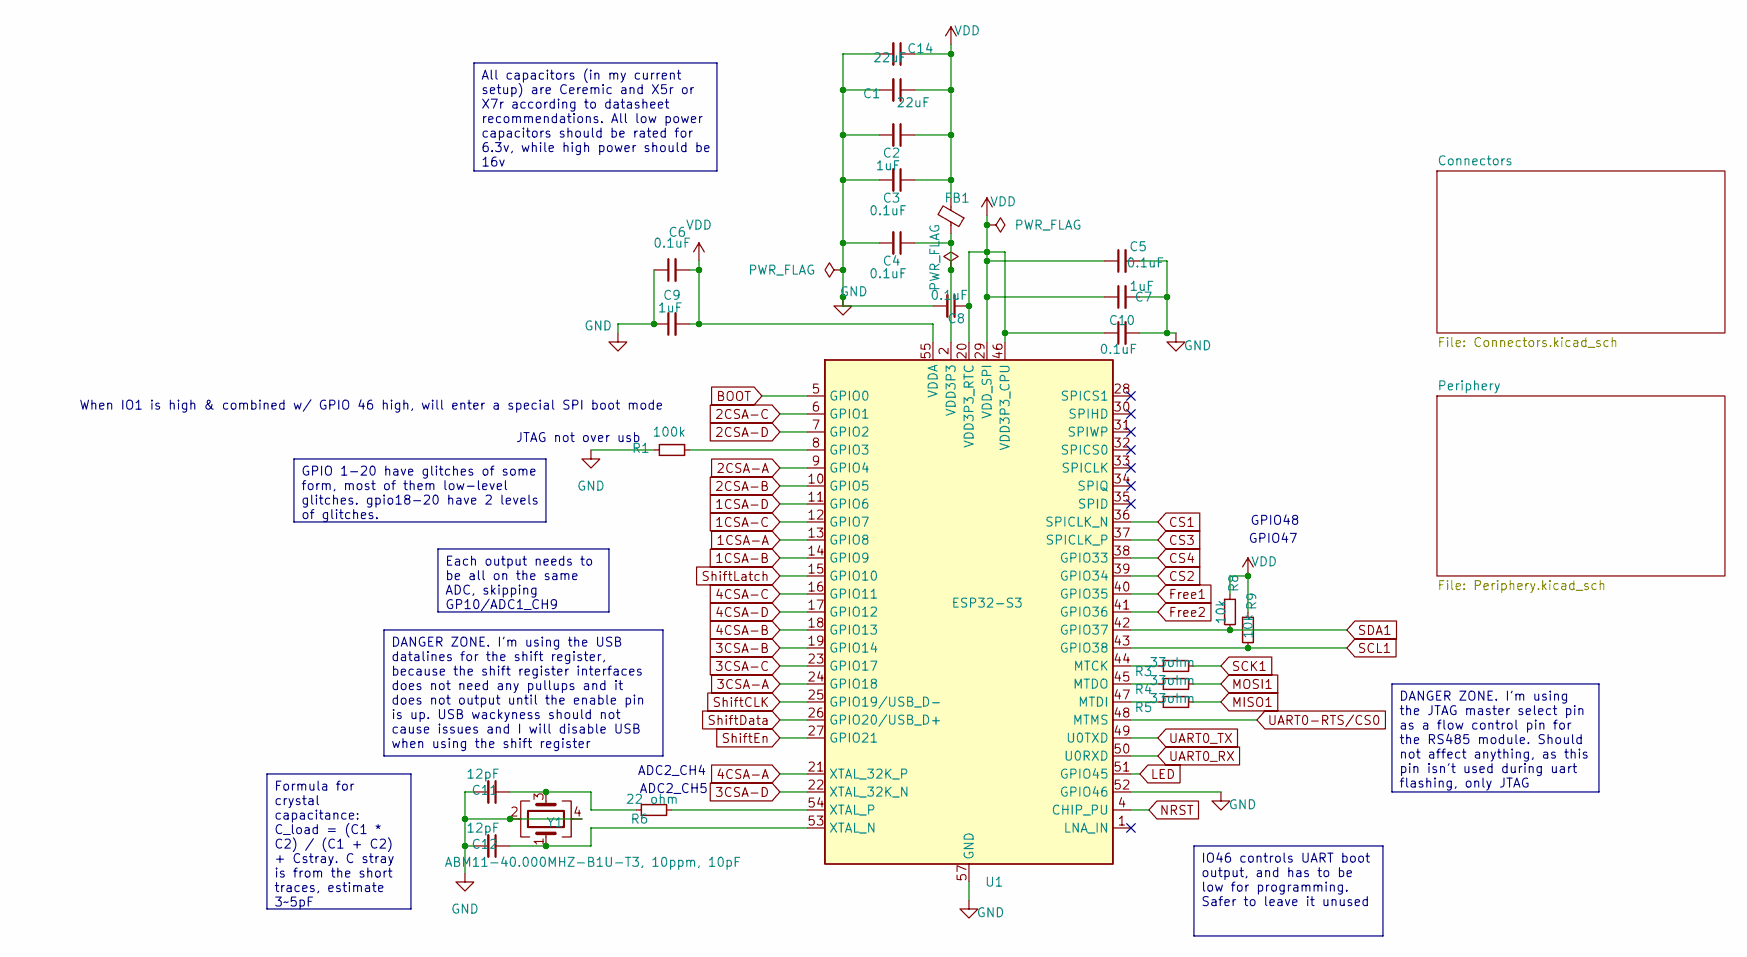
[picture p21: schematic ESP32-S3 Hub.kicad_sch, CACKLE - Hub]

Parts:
C1, C14: 22uF; C_0402_1005Metric; LCSC C415703
C2, C7, C9: 1uF; C_0402_1005Metric; LCSC C52923
C3, C4, C5, C6, C8, C10: 0.1uF; C_0402_1005Metric; LCSC C1525
C11, C12: 12pF; C_0402_1005Metric; LCSC C1547
FB1: 120ohm imp @100mhz, 1 amp; L_0402_1005Metric; LCSC C82861
R1: 100k; R_0402_1005Metric; LCSC C25741
R3, R4, R5: 33ohm; R_0402_1005Metric; LCSC C25105
R6: 22 ohm; R_0402_1005Metric; LCSC C25092
R8, R9: 10k; R_0402_1005Metric; LCSC C25744
U1: ESP32-S3; QFN-56-1EP_7x7mm_P0.4mm_EP4x4mm; LCSC C3013940
Y1: ABM11-40.000MHZ-B1U-T3, 10ppm, 10pF; Crystal_SMD_2016-4Pin_2.0x1.6mm; LCSC C648973

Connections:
1CSA-A: U1.13 (GPIO8); also elsewhere on the board
1CSA-B: U1.14 (GPIO9); also elsewhere on the board
1CSA-C: U1.12 (GPIO7); also elsewhere on the board
1CSA-D: U1.11 (GPIO6); also elsewhere on the board
2CSA-A: U1.9 (GPIO4); also elsewhere on the board
2CSA-B: U1.10 (GPIO5); also elsewhere on the board
2CSA-C: U1.6 (GPIO1); also elsewhere on the board
2CSA-D: U1.7 (GPIO2); also elsewhere on the board
3CSA-A: U1.24 (GPIO18); also elsewhere on the board
3CSA-B: U1.19 (GPIO14); also elsewhere on the board
3CSA-C: U1.23 (GPIO17); also elsewhere on the board
3CSA-D: U1.22 (XTAL_32K_N); also elsewhere on the board
4CSA-A: U1.21 (XTAL_32K_P); also elsewhere on the board
4CSA-B: U1.18 (GPIO13); also elsewhere on the board
4CSA-C: U1.16 (GPIO11); also elsewhere on the board
4CSA-D: U1.17 (GPIO12); also elsewhere on the board
BOOT: U1.5 (GPIO0); also elsewhere on the board
CS1: U1.36 (SPICLK_N); also elsewhere on the board
CS2: U1.39 (GPIO34); also elsewhere on the board
CS3: U1.37 (SPICLK_P); also elsewhere on the board
CS4: U1.38 (GPIO33); also elsewhere on the board
Free1: U1.40 (GPIO35); also elsewhere on the board
Free2: U1.41 (GPIO36); also elsewhere on the board
GND: C1.2, C2.2, C3.2, C4.2, C5.2, C6.1, C7.2, C8.2, C9.1, C10.2, C11.2, C12.2, C14.2, R1.2, U1.52 (GPIO46), U1.57 (GND), Y1.2, Y1.4; also elsewhere on the board
LED: U1.51 (GPIO45); also elsewhere on the board
MISO1: R5.2; also elsewhere on the board
MOSI1: R4.2; also elsewhere on the board
NRST: U1.4 (CHIP_PU); also elsewhere on the board
unnamed: C4.1, FB1.1, U1.2 (VDD3P3), U1.3 (VDD3P3)
unnamed: C11.1, R6.1, Y1.3
unnamed: R1.1, U1.8 (GPIO3)
unnamed: R3.1, U1.44 (MTCK)
unnamed: R5.1, U1.47 (MTDI)
unnamed: R4.1, U1.45 (MTDO)
unnamed: C12.1, U1.53 (XTAL_N), Y1.1
unnamed: R6.2, U1.54 (XTAL_P)
SCK1: R3.2; also elsewhere on the board
SCL1: R9.2, U1.43 (GPIO38); also elsewhere on the board
SDA1: R8.2, U1.42 (GPIO37); also elsewhere on the board
ShiftCLK: U1.25 (GPIO19/USB_D-); also elsewhere on the board
ShiftData: U1.26 (GPIO20/USB_D+); also elsewhere on the board
ShiftEn: U1.27 (GPIO21); also elsewhere on the board
ShiftLatch: U1.15 (GPIO10); also elsewhere on the board
UART0-RTS/CS0: U1.48 (MTMS); also elsewhere on the board
UART0_RX: U1.50 (U0RXD); also elsewhere on the board
UART0_TX: U1.49 (U0TXD); also elsewhere on the board
VDD: C1.1, C2.1, C3.1, C5.1, C6.2, C7.1, C8.1, C9.2, C10.1, C14.1, FB1.2, R8.1, R9.1, U1.20 (VDD3P3_RTC), U1.29 (VDD_SPI), U1.46 (VDD3P3_CPU), U1.55 (VDDA), U1.56 (VDDA); also elsewhere on the board

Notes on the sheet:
GPIO48
JTAG not over usb
GPIO47
When IO1 is high & combined w/ GPIO 46 high, will enter a special SPI boot mode
ADC2_CH4
ADC2_CH5
DANGER ZONE. I'm using the JTAG master select pin as a flow control pin for the RS485 module. Should not affect anything, as this pin isn't used during uart flashing, only JTAG
DANGER ZONE. I'm using the USB datalines for the shift register, because the shift register interfaces does not need any pullups and it does not output until the enable pin is up. USB wackyness should not cause issues and I will disable USB when using the shift register
All capacitors (in my current setup) are Ceremic and X5r or X7r according to datasheet recommendations. All low power capacitors should be rated for 6.3v, while high power should be 16v
IO46 controls UART boot output, and has to be low for programming. Safer to leave it unused
Each output needs to be all on the same ADC, skipping GP10/ADC1_CH9
GPIO 1-20 have glitches of some form, most of them low-level glitches. gpio18-20 have 2 levels of glitches.
Formula for crystal capacitance: C_load = (C1 * C2) / (C1 + C2) + Cstray. C stray is from the short traces, estimate 3~5pF

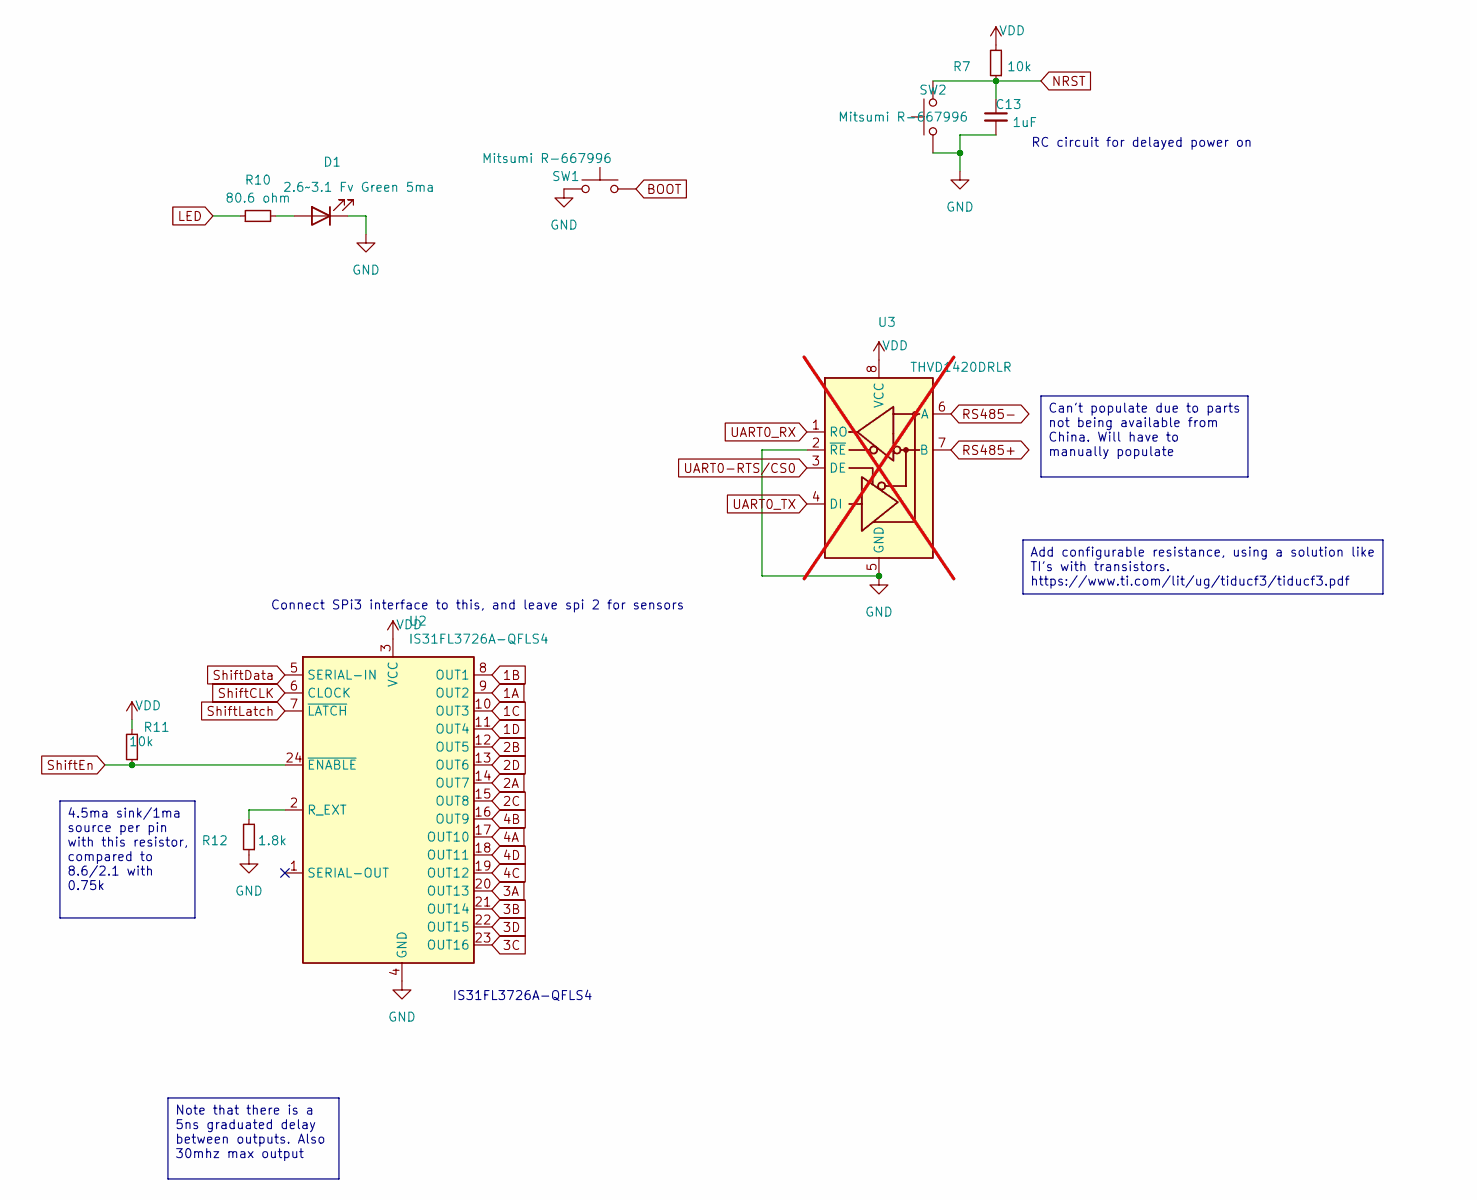
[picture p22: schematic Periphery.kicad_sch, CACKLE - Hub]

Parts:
C13: 1uF; C_0402_1005Metric; LCSC C52923
D1: 2.6~3.1 Fv Green 5ma; LED_0603_1608Metric_Pad1.05x0.95mm_HandSolder; LCSC C3028858
R7, R11: 10k; R_0402_1005Metric; LCSC C25744
R10: 80.6 ohm; R_0402_1005Metric; LCSC C185392
R12: 1.8k; R_0402_1005Metric; LCSC C25744
SW1, SW2: Mitsumi R-667996; R-667995_MIT; LCSC C4365007
U2: IS31FL3726A-QFLS4; QFN-24-1EP_4x4mm_P0.5mm_EP2.7x2.7mm
U3: THVD1420DRLR; SOT-583-8; not fitted

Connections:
1A: U2.9 (OUT2); also elsewhere on the board
1B: U2.8 (OUT1); also elsewhere on the board
1C: U2.10 (OUT3); also elsewhere on the board
1D: U2.11 (OUT4); also elsewhere on the board
2A: U2.14 (OUT7); also elsewhere on the board
2B: U2.12 (OUT5); also elsewhere on the board
2C: U2.15 (OUT8); also elsewhere on the board
2D: U2.13 (OUT6); also elsewhere on the board
3A: U2.20 (OUT13); also elsewhere on the board
3B: U2.21 (OUT14); also elsewhere on the board
3C: U2.23 (OUT16); also elsewhere on the board
3D: U2.22 (OUT15); also elsewhere on the board
4A: U2.17 (OUT10); also elsewhere on the board
4B: U2.16 (OUT9); also elsewhere on the board
4C: U2.19 (OUT12); also elsewhere on the board
4D: U2.18 (OUT11); also elsewhere on the board
BOOT: SW1.2; also elsewhere on the board
GND: C13.2, D1.1 (K), R12.1, SW1.1, SW2.1, U2.4 (GND), U2.25 (GND), U3.2 (~RE), U3.5 (GND); also elsewhere on the board
LED: R10.1; also elsewhere on the board
NRST: C13.1, R7.1, SW2.2; also elsewhere on the board
unnamed: D1.2 (A), R10.2
unnamed: R12.2, U2.2 (R_EXT)
RS485+: U3.7 (B); also elsewhere on the board
RS485-: U3.6 (A); also elsewhere on the board
ShiftCLK: U2.6 (CLOCK); also elsewhere on the board
ShiftData: U2.5 (SERIAL-IN); also elsewhere on the board
ShiftEn: R11.1, U2.24 (~ENABLE); also elsewhere on the board
ShiftLatch: U2.7 (~LATCH); also elsewhere on the board
UART0-RTS/CS0: U3.3 (DE); also elsewhere on the board
UART0_RX: U3.1 (RO); also elsewhere on the board
UART0_TX: U3.4 (DI); also elsewhere on the board
VDD: R7.2, R11.2, U2.3 (VCC), U3.8 (VCC); also elsewhere on the board

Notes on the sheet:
IS31FL3726A-QFLS4
RC circuit for delayed power on
Connect SPi3 interface to this, and leave spi 2 for sensors
Can't populate due to parts not being available from China. Will have to manually populate
Add configurable resistance, using a solution like TI's with transistors. https://www.ti.com/lit/ug/tiducf3/tiducf3.pdf
Note that there is a 5ns graduated delay between outputs. Also 30mhz max output
4.5ma sink/1ma source per pin with this resistor, compared to 8.6/2.1 with 0.75k

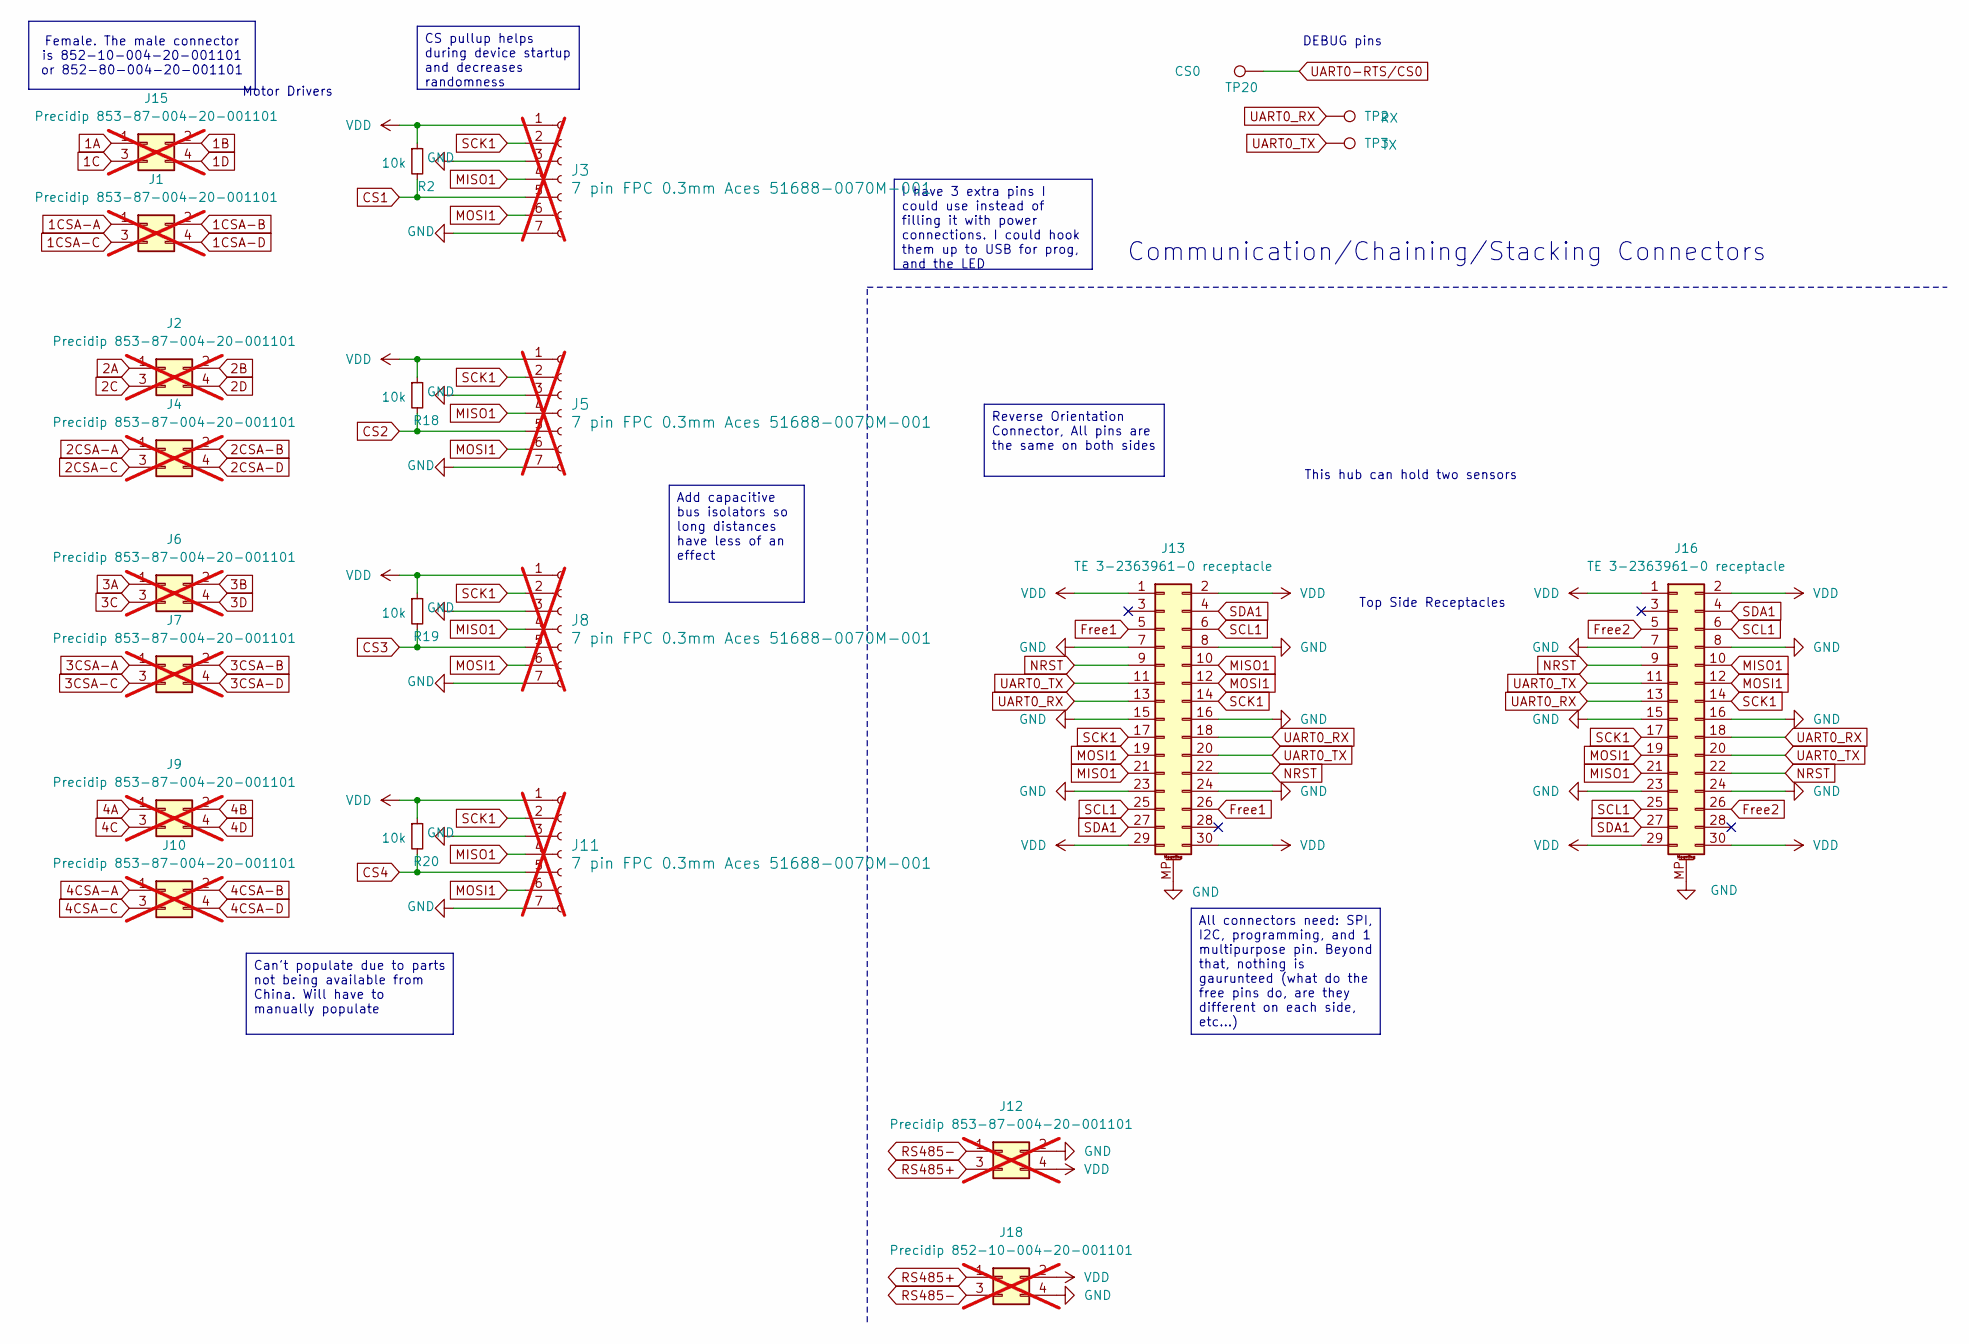
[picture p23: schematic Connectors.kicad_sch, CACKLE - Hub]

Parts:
J1, J2, J4, J6, J7, J9, J10, J12, J15: Precidip 853-87-004-20-001101; PinHeader_2x02_P1.27mm_Horizontal; not fitted
J3, J5, J8, J11: 7 pin FPC 0.3mm Aces 51688-0070M-001; fpc_7pin_0.3mm_connector Aces; not fitted
J13, J16: TE 3-2363961-0 receptacle; TE_mezzanine_rec_3-2363961-0; LCSC C425103
J18: Precidip 852-10-004-20-001101; PinHeader_2x02_P1.27mm_Horizontal; not fitted
R2, R18, R19, R20: 10k; R_0402_1005Metric; LCSC C25744
TP2: RX; TestPoint_Pad_D1.0mm
TP3: TX; TestPoint_Pad_D1.0mm
TP20: CS0; TestPoint_Pad_D1.0mm

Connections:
1A: J15.1; also elsewhere on the board
1B: J15.2; also elsewhere on the board
1C: J15.3; also elsewhere on the board
1CSA-A: J1.1; also elsewhere on the board
1CSA-B: J1.2; also elsewhere on the board
1CSA-C: J1.3; also elsewhere on the board
1CSA-D: J1.4; also elsewhere on the board
1D: J15.4; also elsewhere on the board
2A: J2.1; also elsewhere on the board
2B: J2.2; also elsewhere on the board
2C: J2.3; also elsewhere on the board
2CSA-A: J4.1; also elsewhere on the board
2CSA-B: J4.2; also elsewhere on the board
2CSA-C: J4.3; also elsewhere on the board
2CSA-D: J4.4; also elsewhere on the board
2D: J2.4; also elsewhere on the board
3A: J6.1; also elsewhere on the board
3B: J6.2; also elsewhere on the board
3C: J6.3; also elsewhere on the board
3CSA-A: J7.1; also elsewhere on the board
3CSA-B: J7.2; also elsewhere on the board
3CSA-C: J7.3; also elsewhere on the board
3CSA-D: J7.4; also elsewhere on the board
3D: J6.4; also elsewhere on the board
4A: J9.1; also elsewhere on the board
4B: J9.2; also elsewhere on the board
4C: J9.3; also elsewhere on the board
4CSA-A: J10.1; also elsewhere on the board
4CSA-B: J10.2; also elsewhere on the board
4CSA-C: J10.3; also elsewhere on the board
4CSA-D: J10.4; also elsewhere on the board
4D: J9.4; also elsewhere on the board
CS1: J3.5, R2.2; also elsewhere on the board
CS2: J5.5, R18.2; also elsewhere on the board
CS3: J8.5, R19.2; also elsewhere on the board
CS4: J11.5, R20.2; also elsewhere on the board
Free1: J13.5, J13.26; also elsewhere on the board
Free2: J16.5, J16.26; also elsewhere on the board
GND: J3.3, J3.7, J5.3, J5.7, J8.3, J8.7, J11.3, J11.7, J12.2, J13.7, J13.8, J13.15, J13.16, J13.23, J13.24, J13.MP (MountPin), J16.7, J16.8, J16.15, J16.16, J16.23, J16.24, J16.MP (MountPin), J18.4; also elsewhere on the board
MISO1: J3.4, J5.4, J8.4, J11.4, J13.10, J13.21, J16.10, J16.21; also elsewhere on the board
MOSI1: J3.6, J5.6, J8.6, J11.6, J13.12, J13.19, J16.12, J16.19; also elsewhere on the board
NRST: J13.9, J13.22, J16.9, J16.22; also elsewhere on the board
RS485+: J12.3, J18.1; also elsewhere on the board
RS485-: J12.1, J18.3; also elsewhere on the board
SCK1: J3.2, J5.2, J8.2, J11.2, J13.14, J13.17, J16.14, J16.17; also elsewhere on the board
SCL1: J13.6, J13.25, J16.6, J16.25; also elsewhere on the board
SDA1: J13.4, J13.27, J16.4, J16.27; also elsewhere on the board
UART0-RTS/CS0: TP20.1; also elsewhere on the board
UART0_RX: J13.13, J13.18, J16.13, J16.18, TP2.1; also elsewhere on the board
UART0_TX: J13.11, J13.20, J16.11, J16.20, TP3.1; also elsewhere on the board
VDD: J3.1, J5.1, J8.1, J11.1, J12.4, J13.1, J13.2, J13.29, J13.30, J16.1, J16.2, J16.29, J16.30, J18.2, R2.1, R18.1, R19.1, R20.1; also elsewhere on the board

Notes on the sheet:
Communication/Chaining/Stacking Connectors
Top Side Receptacles
Motor Drivers
This hub can hold two sensors
DEBUG pins
Reverse Orientation Connector, All pins are the same on both sides
CS pullup helps during device startup and decreases randomness
Can't populate due to parts not being available from China. Will have to manually populate
Add capacitive bus isolators so long distances have less of an effect
I have 3 extra pins I could use instead of filling it with power connections. I could hook them up to USB for prog, and the LED
All connectors need: SPI, I2C, programming, and 1 multipurpose pin. Beyond that, nothing is gaurunteed (what do the free pins do, are they different on each side, etc...)
Female. The male connector is 852-10-004-20-001101 or 852-80-004-20-001101

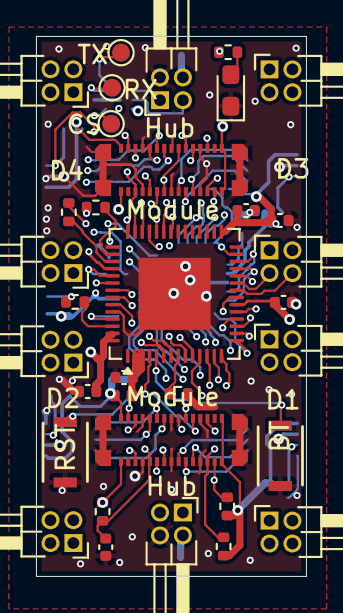
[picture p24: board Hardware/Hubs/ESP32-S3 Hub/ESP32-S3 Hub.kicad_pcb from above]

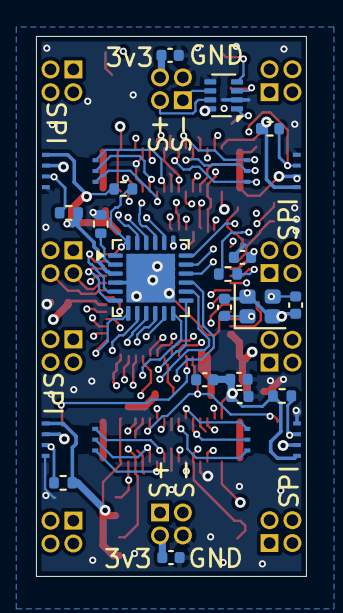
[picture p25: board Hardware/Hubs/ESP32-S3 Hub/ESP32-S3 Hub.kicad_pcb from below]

Board: 6 copper layers, 15.0 x 30.0 mm, 56 parts (22 on the bottom side), 67 nets.

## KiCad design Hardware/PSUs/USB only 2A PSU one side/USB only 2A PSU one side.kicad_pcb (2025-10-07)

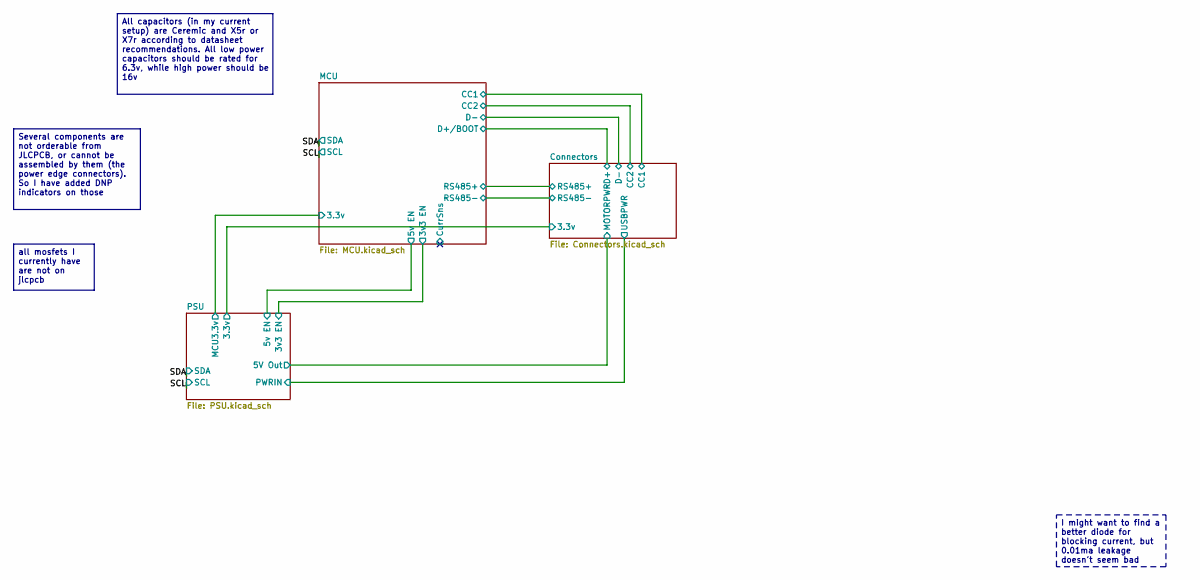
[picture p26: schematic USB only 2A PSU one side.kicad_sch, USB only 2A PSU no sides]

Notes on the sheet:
All capacitors (in my current setup) are Ceremic and X5r or X7r according to datasheet recommendations. All low power capacitors should be rated for 6.3v, while high power should be 16v
Several components are not orderable from JLCPCB, or cannot be assembled by them (the power edge connectors). So I have added DNP indicators on those
all mosfets I currently have are not on jlcpcb
I might want to find a better diode for blocking current, but 0.01ma leakage doesn't seem bad

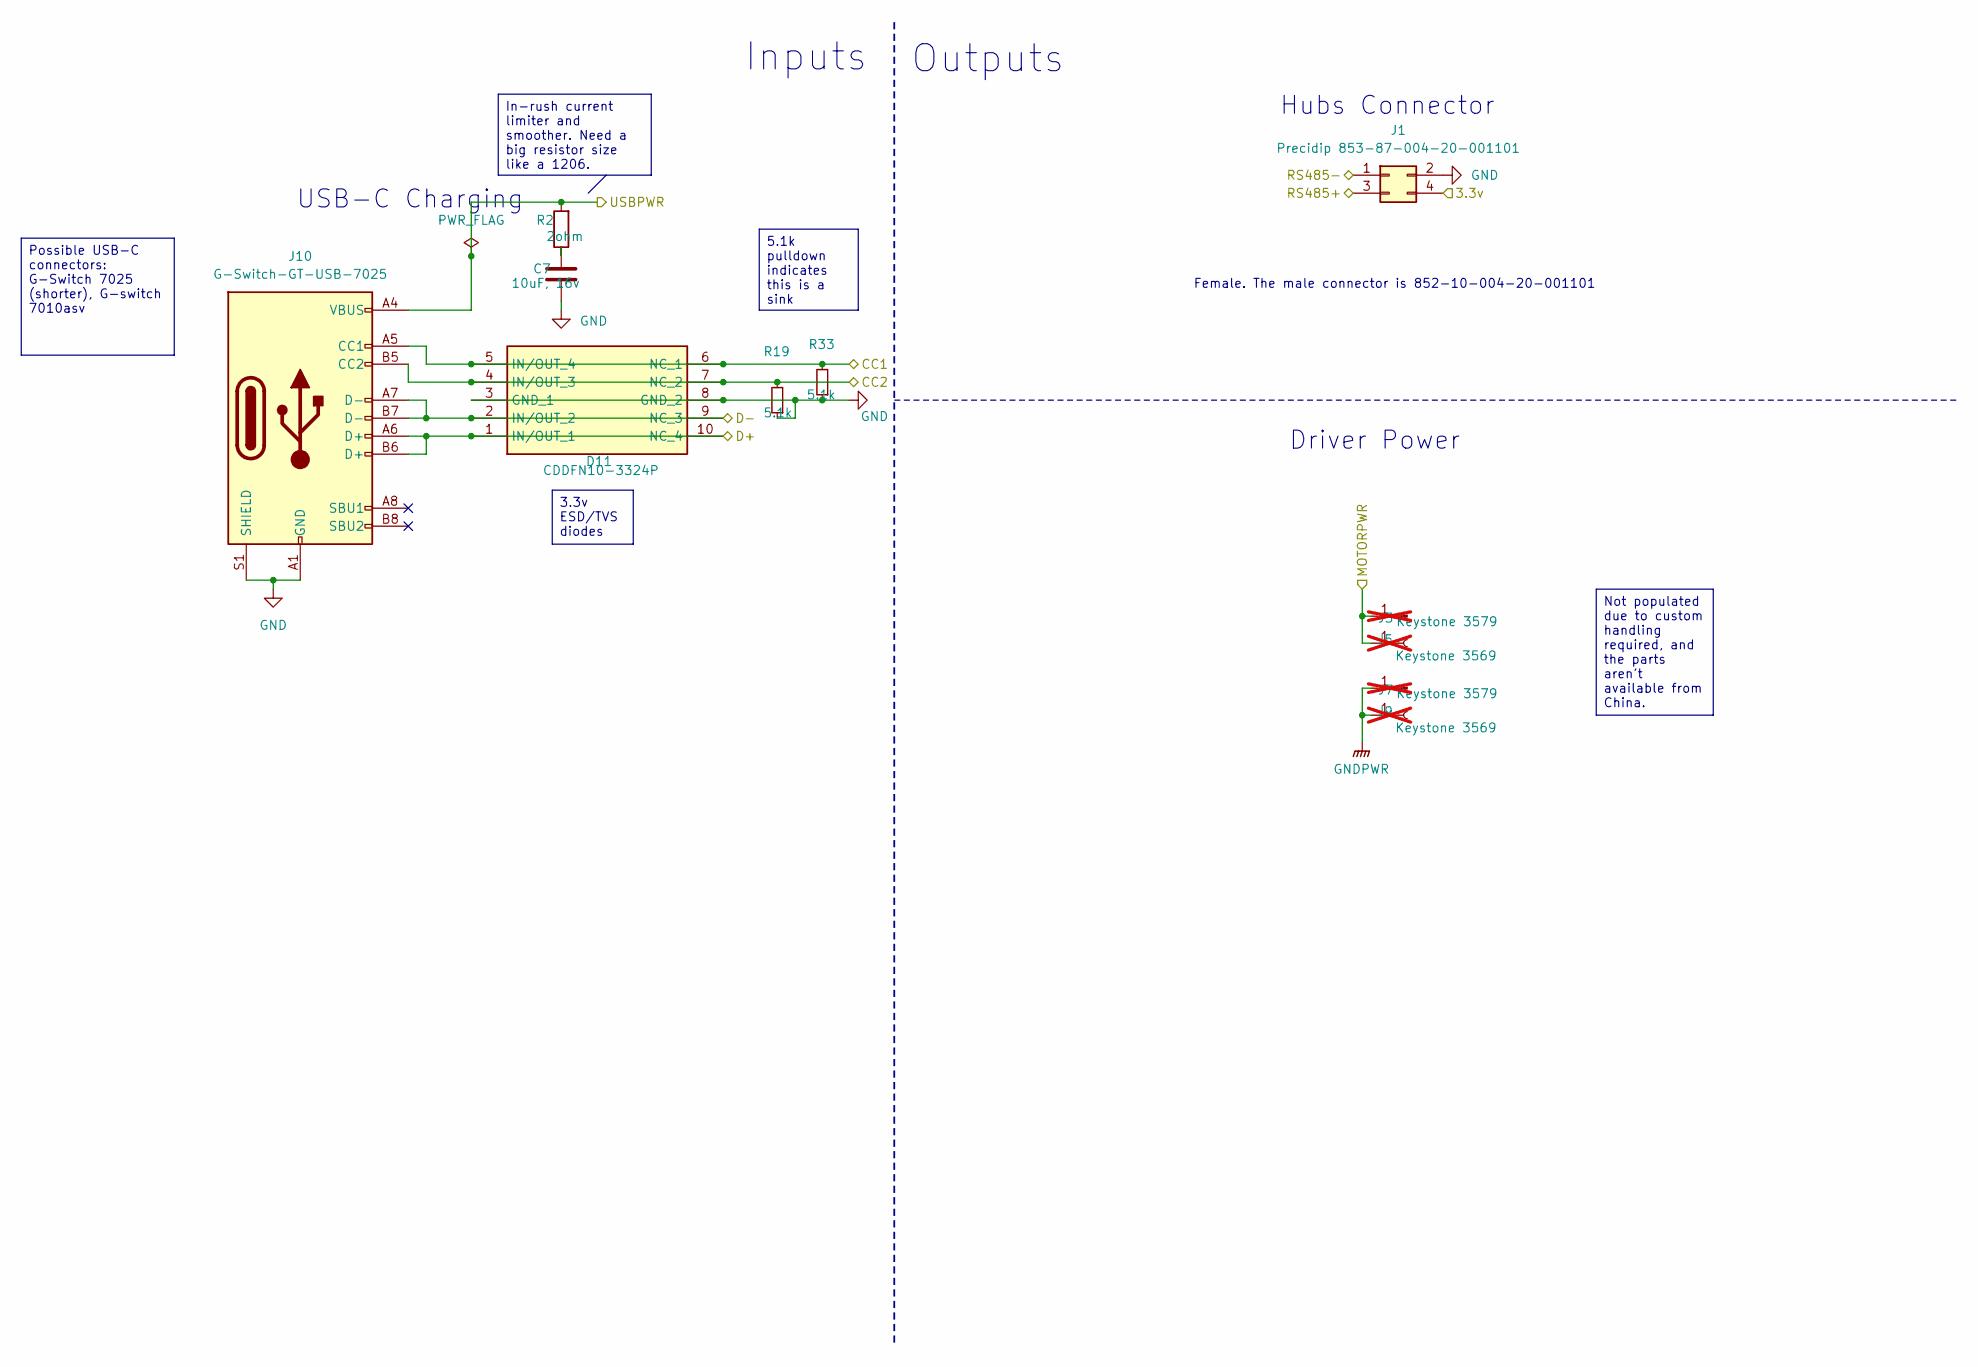
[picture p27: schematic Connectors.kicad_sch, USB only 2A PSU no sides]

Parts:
C7: 10uF, 16v; C_0805_2012Metric; LCSC C15850
D11: CDDFN10-3324P; CDDFN103324P; Mouser Part Number 652-CDDFN10-3324P
J1: Precidip 853-87-004-20-001101; PinHeader_2x02_P1.27mm_Horizontal
J3, J7: Keystone 3579; Keystone_3579; not fitted
J5, J9: Keystone 3569; Keystone_3569_half; not fitted
J10: G-Switch-GT-USB-7025; USB_C_G-Switch_GT-USB-7025-JLCPCBv; LCSC C963213
R2: 2ohm; R_0805_2012Metric; LCSC C17521
R19, R33: 5.1k; R_0805_2012Metric; LCSC C25905

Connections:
/Connectors/3.3v: J1.4; also elsewhere on the board
/Connectors/CC1: D11.5 (IN/OUT_4), D11.6 (NC_1), J10.A5 (CC1), R33.2; also elsewhere on the board
/Connectors/CC2: D11.4 (IN/OUT_3), D11.7 (NC_2), J10.B5 (CC2), R19.2; also elsewhere on the board
/Connectors/D+: D11.1 (IN/OUT_1), D11.10 (NC_4), J10.A6 (D+), J10.B6 (D+); also elsewhere on the board
/Connectors/D-: D11.2 (IN/OUT_2), D11.9 (NC_3), J10.A7 (D-), J10.B7 (D-); also elsewhere on the board
/Connectors/RS485+: J1.3; also elsewhere on the board
/Connectors/RS485-: J1.1; also elsewhere on the board
/Connectors/USBPWR: J10.A4 (VBUS), J10.A9 (VBUS), J10.B4 (VBUS), J10.B9 (VBUS), R2.2; also elsewhere on the board
/PSU/5V Out: J3.1, J5.1; also elsewhere on the board
GND: C7.2, D11.3 (GND_1), D11.8 (GND_2), J1.2, J10.A1 (GND), J10.A12 (GND), J10.B1 (GND), J10.B12 (GND), J10.S1 (SHIELD), R19.1, R33.1; also elsewhere on the board
GNDPWR: J7.1, J9.1; also elsewhere on the board
unnamed: C7.1, R2.1

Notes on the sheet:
Female. The male connector is 852-10-004-20-001101
Outputs
USB-C Charging
Inputs
Driver Power
Hubs Connector
In-rush current limiter and smoother. Need a big resistor size like a 1206.
5.1k pulldown indicates this is a sink
Possible USB-C connectors: G-Switch 7025 (shorter), G-switch 7010asv
3.3v ESD/TVS diodes
Not populated due to custom handling required, and the parts aren't available from China.

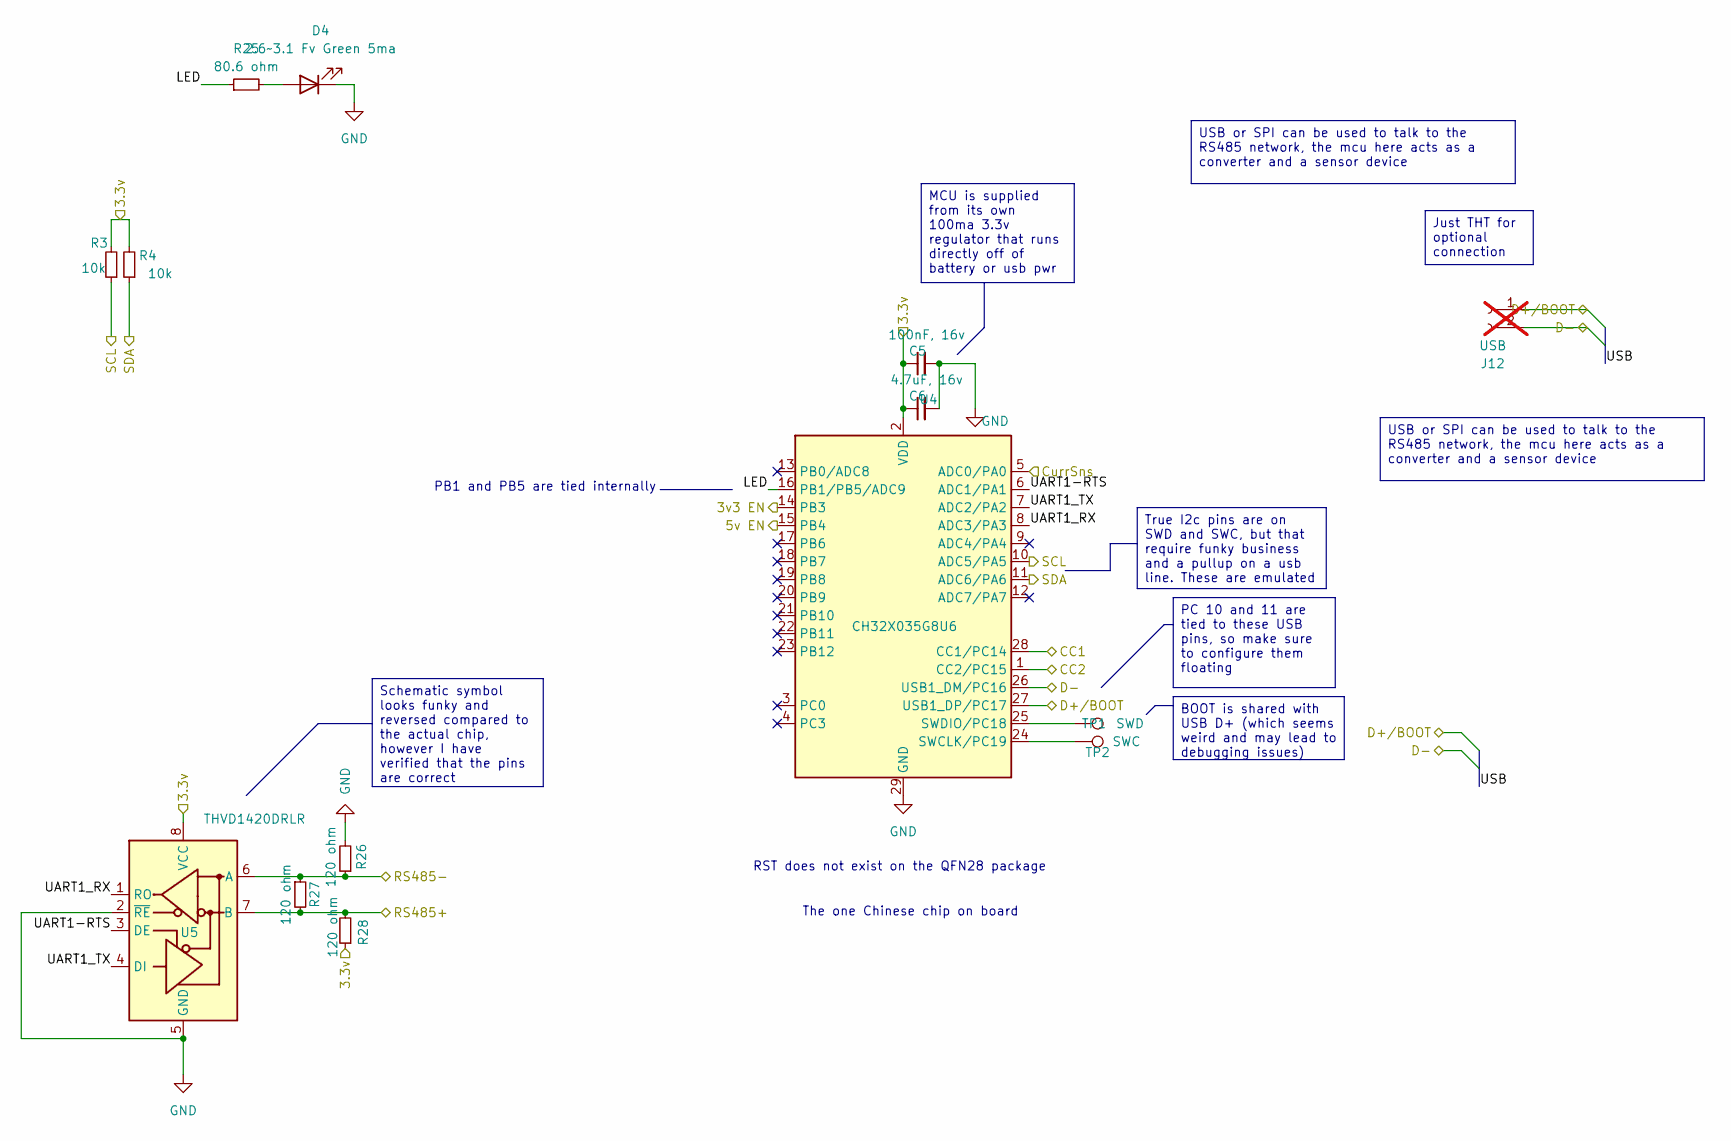
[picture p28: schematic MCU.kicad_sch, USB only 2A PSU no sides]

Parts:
C5: 100nF, 16v; C_0805_2012Metric; LCSC C1525
C6: 4.7uF, 16v; C_0805_2012Metric; LCSC C19666
D4: 2.6~3.1 Fv Green 5ma; LED_0603_1608Metric_Pad1.05x0.95mm_HandSolder; LCSC C3028858
J12: USB; PinHeader_1x02_P1.27mm_Vertical; not fitted
R3, R4: 10k; R_0805_2012Metric; LCSC C25744
R25: 80.6 ohm; R_0805_2012Metric; LCSC C185392
R26, R27, R28: 120 ohm; R_0805_2012Metric; LCSC C25079
TP1: SWD; TestPoint_Pad_D1.0mm
TP2: SWC; TestPoint_Pad_D1.0mm
U4: CH32X035G8U6; QFN-28-1EP_4x4mm_P0.4mm_EP2.8x2.8mm; LCSC C7437027
U5: THVD1420DRLR; SOT-583-8

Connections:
/Connectors/CC1: U4.28 (CC1/PC14); also elsewhere on the board
/Connectors/CC2: U4.1 (CC2/PC15); also elsewhere on the board
/Connectors/D+: J12.1, U4.27 (USB1_DP/PC17); also elsewhere on the board
/Connectors/D-: J12.2, U4.26 (USB1_DM/PC16); also elsewhere on the board
/Connectors/RS485+: R27.2, R28.2, U5.7 (B); also elsewhere on the board
/Connectors/RS485-: R26.1, R27.1, U5.6 (A); also elsewhere on the board
/MCU/3.3v: C5.1, C6.1, R3.2, R4.2, R28.1, U4.2 (VDD), U5.8 (VCC); also elsewhere on the board
/MCU/3v3 EN: U4.14 (PB3); also elsewhere on the board
/MCU/5v EN: U4.15 (PB4); also elsewhere on the board
/MCU/CurrSns: U4.5 (ADC0/PA0)
/MCU/LED: R25.1, U4.16 (PB1/PB5/ADC9)
/MCU/UART1-RTS: U4.6 (ADC1/PA1), U5.3 (DE)
/MCU/UART1_RX: U4.8 (ADC3/PA3), U5.1 (RO)
/MCU/UART1_TX: U4.7 (ADC2/PA2), U5.4 (DI)
/SCL: R3.1, U4.10 (ADC5/PA5); also elsewhere on the board
/SDA: R4.1, U4.11 (ADC6/PA6); also elsewhere on the board
GND: C5.2, C6.2, D4.1 (K), R26.2, U4.29 (GND), U5.2 (~RE), U5.5 (GND); also elsewhere on the board
unnamed: D4.2 (A), R25.2
unnamed: TP2.1, U4.24 (SWCLK/PC19)
unnamed: TP1.1, U4.25 (SWDIO/PC18)

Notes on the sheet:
PB1 and PB5 are tied internally
RST does not exist on the QFN28 package
The one Chinese chip on board
USB or SPI can be used to talk to the RS485 network, the mcu here acts as a converter and a sensor device
MCU is supplied from its own 100ma 3.3v regulator that runs directly off of battery or usb pwr
Just THT for optional connection
PC 10 and 11 are tied to these USB pins, so make sure to configure them floating
Schematic symbol looks funky and reversed compared to the actual chip, however I have verified that the pins are correct
True I2c pins are on SWD and SWC, but that require funky business and a pullup on a usb line. These are emulated
BOOT is shared with USB D+ (which seems weird and may lead to debugging issues)

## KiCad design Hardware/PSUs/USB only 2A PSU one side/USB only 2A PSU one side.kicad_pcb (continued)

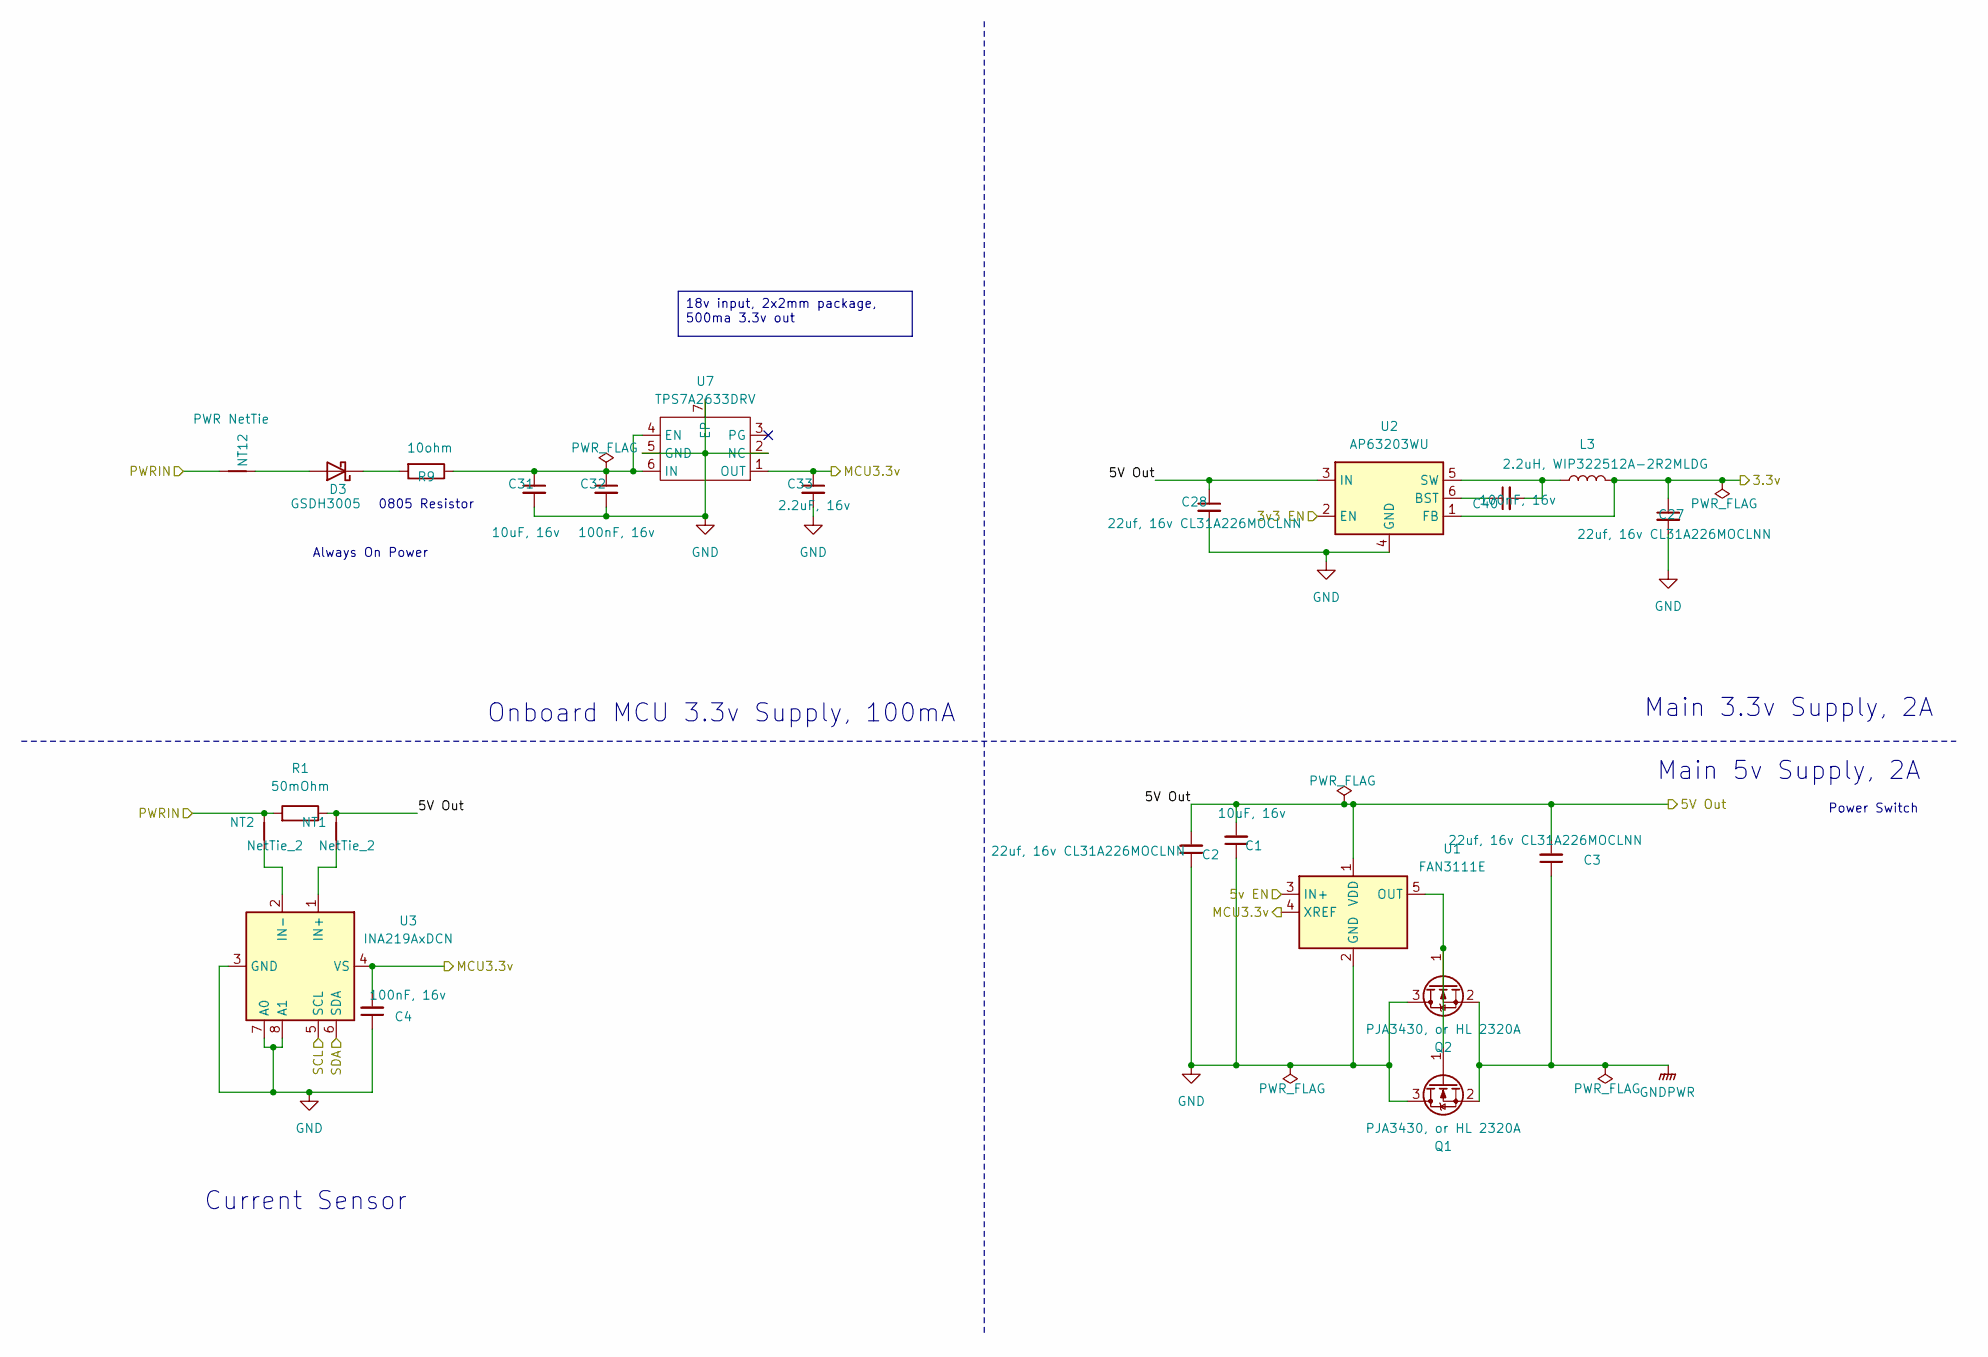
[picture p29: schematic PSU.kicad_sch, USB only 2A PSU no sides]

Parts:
C1, C31: 10uF, 16v; C_0805_2012Metric; LCSC C96446
C2, C3, C27, C28: 22uf, 16v CL31A226MOCLNN; C_1206_3216Metric; LCSC C159758
C4, C40: 100nF, 16v; C_0805_2012Metric; LCSC C14663
C32: 100nF, 16v; C_0805_2012Metric; LCSC C1525
C33: 2.2uF, 16v; C_0805_2012Metric; LCSC C12530
D3: GSDH3005; D_0402_1005Metric; LCSC C2837790
L3: 2.2uH, WIP322512A-2R2MLDG; L_1008_2520Metric; LCSC C5832372
NT1, NT2: NetTie_2; NetTie-2_SMD_Pad0.2mm
NT12: PWR NetTie; NetTie-2_SMD_Pad0.28mm
Q1, Q2: PJA3430, or HL 2320A; SC-59
R1: 50mOhm; R_2512_6332Metric
R9: 10ohm; R_0805_2012Metric; LCSC C17415
U1: FAN3111E; SOT-23-5
U2: AP63203WU; TSOT-23-6; LCSC C780769
U3: INA219AxDCN; SOT-23-8
U7: TPS7A2633DRV; WSON-6-1EP_2x2mm_P0.65mm_EP1x1.6mm; LCSC C2876256

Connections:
/Connectors/3.3v: C27.1, L3.2, U2.1 (FB); also elsewhere on the board
/Connectors/USBPWR: NT2.2, NT12.2, R1.2; also elsewhere on the board
/MCU/3.3v: C4.2, C33.1, U1.4 (XREF), U3.4 (VS), U7.1 (OUT); also elsewhere on the board
/MCU/3v3 EN: U2.2 (EN); also elsewhere on the board
/MCU/5v EN: U1.3 (IN+); also elsewhere on the board
/PSU/5V Out: C1.2, C2.2, C3.2, C28.1, NT1.2, R1.1, U1.1 (VDD), U2.3 (IN); also elsewhere on the board
/SCL: U3.5 (SCL); also elsewhere on the board
/SDA: U3.6 (SDA); also elsewhere on the board
GND: C1.1, C2.1, C4.1, C27.2, C28.2, C31.2, C32.2, C33.2, Q1.3 (D), Q2.3 (D), U1.2 (GND), U2.4 (GND), U3.3 (GND), U3.7 (A0), U3.8 (A1), U7.2 (NC), U7.5 (GND), U7.7 (EP); also elsewhere on the board
GNDPWR: C3.1, Q1.2 (S), Q2.2 (S); also elsewhere on the board
unnamed: D3.2 (A), NT12.1
unnamed: D3.1 (K), R9.2
unnamed: Q1.1 (G), Q2.1 (G), U1.5 (OUT)
unnamed: C40.1, U2.6 (BST)
unnamed: C40.2, L3.1, U2.5 (SW)
unnamed: NT1.1, U3.1 (IN+)
unnamed: NT2.1, U3.2 (IN-)
unnamed: C31.1, C32.1, R9.1, U7.4 (EN), U7.6 (IN)

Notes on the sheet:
Current Sensor
Power Switch
Always On Power
Onboard MCU 3.3v Supply, 100mA
Main 3.3v Supply, 2A
0805 Resistor
Main 5v Supply, 2A
18v input, 2x2mm package, 500ma 3.3v out

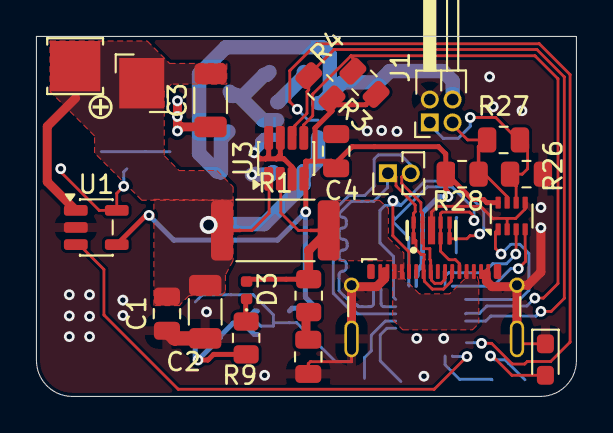
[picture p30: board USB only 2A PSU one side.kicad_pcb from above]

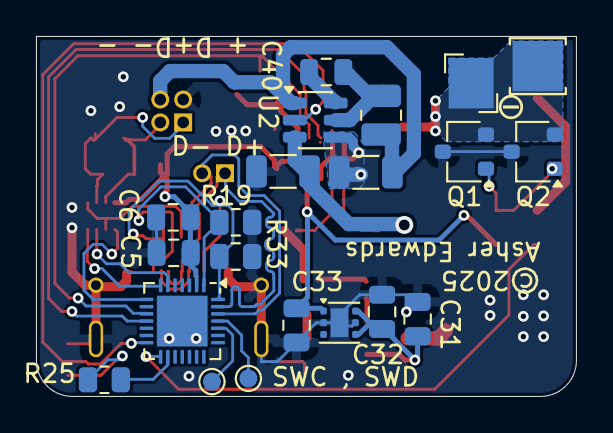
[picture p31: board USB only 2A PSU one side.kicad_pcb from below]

Board: 2 copper layers, 30.0 x 20.0 mm, 48 parts (21 on the bottom side), 32 nets.

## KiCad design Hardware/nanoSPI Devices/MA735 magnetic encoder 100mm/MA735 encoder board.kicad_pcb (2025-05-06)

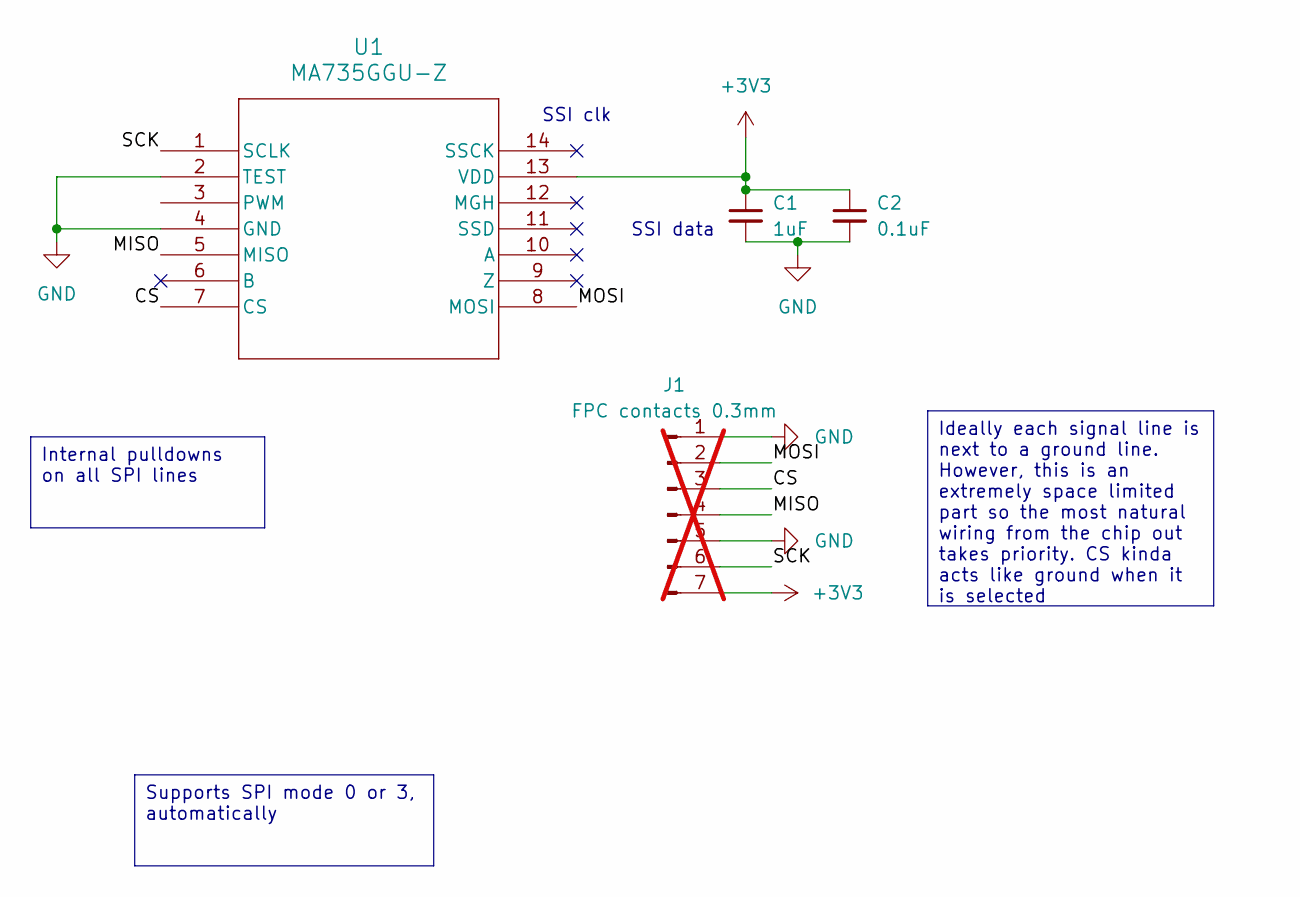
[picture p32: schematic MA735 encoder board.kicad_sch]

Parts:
C1: 1uF; C_0402_1005Metric; LCSC C52923
C2: 0.1uF; C_0402_1005Metric; LCSC C1525
J1: FPC contacts 0.3mm; 7pin_fpc_contact_0.3mmptich; not fitted
U1: MA735GGU-Z; UTQFN-14_MA735_MNP; LCSC C17233427

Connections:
+3V3: C1.1, C2.1, J1.7, U1.13 (VDD)
/CS: J1.3, U1.7 (CS)
/MISO: J1.4, U1.5 (MISO)
/MOSI: J1.2, U1.8 (MOSI)
/SCK: J1.6, U1.1 (SCLK)
GND: C1.2, C2.2, J1.1, J1.5, U1.2 (TEST), U1.4 (GND)

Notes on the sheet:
SSI clk
SSI data
Supports SPI mode 0 or 3, automatically
Ideally each signal line is next to a ground line. However, this is an extremely space limited part so the most natural wiring from the chip out takes priority. CS kinda acts like ground when it is selected
Internal pulldowns on all SPI lines


Board: 2 copper layers, 5.7 x 105.4 mm, 4 parts (0 on the bottom side), 6 nets.

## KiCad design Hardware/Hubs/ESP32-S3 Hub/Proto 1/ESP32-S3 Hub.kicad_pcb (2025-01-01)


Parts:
C1, C14: 22uF; C_0402_1005Metric; LCSC C415703
C2, C7, C9: 1uF; C_0402_1005Metric; LCSC C52923
C3, C4, C5, C6, C8, C10: 0.1uF; C_0402_1005Metric; LCSC C1525
C11, C12: 12pF; C_0402_1005Metric; LCSC C1547
FB1: 120ohm imp @100mhz, 1 amp; L_0402_1005Metric; LCSC C82861
R1: 100k; R_0402_1005Metric; LCSC C25741
R3, R4, R5: 33ohm; R_0402_1005Metric; LCSC C25105
R6: 22 ohm; R_0402_1005Metric; LCSC C25092
R8, R9: 10k; R_0402_1005Metric; LCSC C25744
TP1: S-EN; TestPoint_Pad_D1.0mm
TP4: IO46; TestPoint_Pad_D1.0mm
TP12: SRCLK; TestPoint_Pad_D1.0mm
TP14: SER; TestPoint_Pad_D1.0mm
U1: ESP32-S3; QFN-56-1EP_7x7mm_P0.4mm_EP4x4mm; LCSC C3013940
Y1: ABM11-40.000MHZ-B1U-T3, 10ppm, 10pF; Crystal_SMD_2016-4Pin_2.0x1.6mm; LCSC C648973

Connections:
1A: U1.15 (GPIO10); also elsewhere on the board
1B: U1.16 (GPIO11); also elsewhere on the board
1C: U1.17 (GPIO12); also elsewhere on the board
1CSA-A: U1.13 (GPIO8); also elsewhere on the board
1CSA-B: U1.14 (GPIO9); also elsewhere on the board
2A: U1.18 (GPIO13); also elsewhere on the board
2B: U1.19 (GPIO14); also elsewhere on the board
2C: U1.21 (XTAL_32K_P); also elsewhere on the board
2CSA-A: U1.11 (GPIO6); also elsewhere on the board
2CSA-B: U1.12 (GPIO7); also elsewhere on the board
3A: U1.22 (XTAL_32K_N); also elsewhere on the board
3B: U1.23 (GPIO17); also elsewhere on the board
3C: U1.36 (SPICLK_N); also elsewhere on the board
3CSA-A: U1.10 (GPIO5); also elsewhere on the board
3CSA-B: U1.9 (GPIO4); also elsewhere on the board
4A: U1.38 (GPIO33); also elsewhere on the board
4B: U1.39 (GPIO34); also elsewhere on the board
4C: U1.37 (SPICLK_P); also elsewhere on the board
4CSA-A: U1.6 (GPIO1); also elsewhere on the board
4CSA-B: U1.7 (GPIO2); also elsewhere on the board
BOOT: U1.5 (GPIO0); also elsewhere on the board
Free1: U1.40 (GPIO35); also elsewhere on the board
Free2: U1.41 (GPIO36); also elsewhere on the board
GND: C1.2, C2.2, C3.2, C4.2, C5.2, C6.1, C7.2, C8.2, C9.1, C10.2, C11.2, C12.2, C14.2, R1.2, U1.57 (GND), Y1.2, Y1.4; also elsewhere on the board
LED: U1.51 (GPIO45); also elsewhere on the board
MISO1: R5.2; also elsewhere on the board
MOSI1: R4.2; also elsewhere on the board
NRST: U1.4 (CHIP_PU); also elsewhere on the board
unnamed: C4.1, FB1.1, U1.2 (VDD3P3), U1.3 (VDD3P3)
unnamed: C11.1, R6.1, Y1.3
unnamed: R1.1, U1.8 (GPIO3)
unnamed: TP4.1, U1.52 (GPIO46)
unnamed: R3.1, U1.44 (MTCK)
unnamed: R5.1, U1.47 (MTDI)
unnamed: R4.1, U1.45 (MTDO)
unnamed: C12.1, U1.53 (XTAL_N), Y1.1
unnamed: R6.2, U1.54 (XTAL_P)
SCK1: R3.2; also elsewhere on the board
SCL1: R9.2, U1.43 (GPIO38); also elsewhere on the board
SDA1: R8.2, U1.42 (GPIO37); also elsewhere on the board
ShiftCLK: TP12.1, U1.25 (GPIO19/USB_D-); also elsewhere on the board
ShiftData: TP14.1, U1.26 (GPIO20/USB_D+); also elsewhere on the board
ShiftEn: TP1.1, U1.27 (GPIO21); also elsewhere on the board
ShiftRegCLK: U1.24 (GPIO18); also elsewhere on the board
UART0-RTS/CS0: U1.48 (MTMS); also elsewhere on the board
UART0_RX: U1.50 (U0RXD); also elsewhere on the board
UART0_TX: U1.49 (U0TXD); also elsewhere on the board
VDD: C1.1, C2.1, C3.1, C5.1, C6.2, C7.1, C8.1, C9.2, C10.1, C14.1, FB1.2, R8.1, R9.1, U1.20 (VDD3P3_RTC), U1.29 (VDD_SPI), U1.46 (VDD3P3_CPU), U1.55 (VDDA), U1.56 (VDDA); also elsewhere on the board

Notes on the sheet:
DANGER ZONE. I'm using the JTAG master select pin as a flow control pin for the RS485 module. When programming I REALLY need to not have anything connected
DANGER ZONE. I'm using the USB datalines for the shift register, because the shift register interfaces does not need any pullups and it does not output until the enable pin is up. USB wackyness should not cause issues and I will disable USB when using the shift register
All capacitors (in my current setup) are Ceremic and X5r or X7r according to datasheet recommendations. All low power capacitors should be rated for 6.3v, while high power should be 16v
IO46 controls UART boot output, and has to be low for programming.
GPIO 1-20 have glitches of some form, most of them low-level glitches. gpio18-20 have 2 levels of glitches.
Formula for crystal capacitance: C_load = (C1 * C2) / (C1 + C2) + Cstray. C stray is from the short traces, estimate 3~5pF
JTAG not over usb
When IO1 is high & combined w/ GPIO 46 high, will enter a special SPI boot mode


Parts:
C13: 1uF; C_0402_1005Metric; LCSC C52923
D1: 2.6~3.1 Fv Green 5ma; LED_0603_1608Metric_Pad1.05x0.95mm_HandSolder; LCSC C3028858
R7, R11: 10k; R_0402_1005Metric; LCSC C25744
R10: 80.6 ohm; R_0402_1005Metric; LCSC C185392
R21, R22, R23: 120 ohm; R_0402_1005Metric; not fitted
SW1, SW2: Mitsumi R-667996; R-667995_MIT; LCSC C4365007
SW3: DS04-254-2-04BK-SMT; SW_DIP_SPSTx04_Slide_Omron_A6S-410x_W8.9mm_P2.54mm; not fitted
U2: 74HC595; DHVQFN-16-1EP_2.5x3.5mm_P0.5mm_EP1x2mm; LCSC C730243
U3: THVD1420DRLR; SOT-583-8; not fitted

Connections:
BOOT: SW1.2; also elsewhere on the board
CS1: U2.15 (QA); also elsewhere on the board
CS2: U2.1 (QB); also elsewhere on the board
CS3: U2.2 (QC); also elsewhere on the board
CS4: U2.3 (QD); also elsewhere on the board
CS5: U2.4 (QE); also elsewhere on the board
CS6: U2.5 (QF); also elsewhere on the board
CS7: U2.6 (QG); also elsewhere on the board
CS8: U2.7 (QH); also elsewhere on the board
GND: C13.2, D1.1 (K), R23.2, SW1.1, SW2.1, U2.8 (GND), U2.17 (GND), U3.2 (~RE), U3.5 (GND); also elsewhere on the board
LED: R10.1; also elsewhere on the board
NRST: C13.1, R7.1, SW2.2; also elsewhere on the board
unnamed: D1.2 (A), R10.2
unnamed: R21.2, SW3.5
unnamed: R22.2, SW3.6
unnamed: R23.1, SW3.2
RS485+: SW3.3, SW3.4, U3.7 (B); also elsewhere on the board
RS485-: R22.1, SW3.7, U3.6 (A); also elsewhere on the board
ShiftCLK: U2.11 (SRCLK); also elsewhere on the board
ShiftData: U2.14 (SER); also elsewhere on the board
ShiftEn: R11.1, U2.13 (~OE); also elsewhere on the board
ShiftRegCLK: U2.12 (RCLK); also elsewhere on the board
UART0-RTS/CS0: U3.3 (DE); also elsewhere on the board
UART0_RX: U3.1 (RO); also elsewhere on the board
UART0_TX: U3.4 (DI); also elsewhere on the board
VDD: R7.2, R11.2, R21.1, U2.16 (VCC), U3.8 (VCC); also elsewhere on the board

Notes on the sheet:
Can't populate due to parts not being available from China. Will have to manually populate
Have pullups on all the Chip select lines to the shift reg, because I have tied the two clocks together and if the outputs are disabled they will be floating, there is no buffer
I really wanted to have Bias and termination resistors optional per device, but space constraints are real, and extra switches on board really does not make sense
RC circuit for delayed power on


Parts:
J1, J2, J4, J6, J7, J9, J10, J12: 1.27mm 3pin socket; PinHeader_1x03_P1.27mm_Vertical; not fitted
J3, J5, J8, J11: 7 pin FPC 0.3mm Panasonic Y3b; fpc_7pin_0.3mm_connector Panasonic; not fitted
J13, J16: TE 3-2363961-0 receptacle; TE_mezzanine_rec_3-2363961-0; LCSC C425103
J14, J17: TE 3-2363962-0 Connector; TE_mezzanine_conn_3-2363962-0; LCSC C425104
J21: 1.27mm 4 pin socket; PinSocket_1x04_P1.27mm_Vertical; not fitted
J22: 1.27mm 4 pin header; PinHeader_1x04_P1.27mm_Horizontal; not fitted
R2, R18, R19, R20: 10k; R_0402_1005Metric; LCSC C25744
TP2: RX; TestPoint_Pad_D1.0mm
TP3: TX; TestPoint_Pad_D1.0mm
TP20: CS0; TestPoint_Pad_D1.0mm

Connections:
1A: J1.1; also elsewhere on the board
1B: J1.2; also elsewhere on the board
1C: J1.3; also elsewhere on the board
1CSA-A: J2.1; also elsewhere on the board
1CSA-B: J2.2; also elsewhere on the board
2A: J4.1; also elsewhere on the board
2B: J4.2; also elsewhere on the board
2C: J4.3; also elsewhere on the board
2CSA-A: J6.1; also elsewhere on the board
2CSA-B: J6.2; also elsewhere on the board
3A: J7.1; also elsewhere on the board
3B: J7.2; also elsewhere on the board
3C: J7.3; also elsewhere on the board
3CSA-A: J9.1; also elsewhere on the board
3CSA-B: J9.2; also elsewhere on the board
4A: J10.1; also elsewhere on the board
4B: J10.2; also elsewhere on the board
4C: J10.3; also elsewhere on the board
4CSA-A: J12.1; also elsewhere on the board
4CSA-B: J12.2; also elsewhere on the board
CS1: J3.5, R2.2; also elsewhere on the board
CS2: J5.5, R18.2; also elsewhere on the board
CS3: J8.5, R19.2; also elsewhere on the board
CS4: J11.5, R20.2; also elsewhere on the board
CS5: J13.3, J13.28; also elsewhere on the board
CS6: J13.5, J13.26; also elsewhere on the board
CS7: J16.3, J16.28; also elsewhere on the board
CS8: J16.5, J16.26; also elsewhere on the board
Free1: J13.9, J13.22; also elsewhere on the board
Free2: J16.9, J16.22; also elsewhere on the board
GND: J3.3, J3.7, J5.3, J5.7, J8.3, J8.7, J11.3, J11.7, J13.7, J13.8, J13.15, J13.16, J13.23, J13.24, J13.MP (MountPin), J14.7, J14.8, J14.15, J14.16, J14.23, J14.24, J14.MP (MountPin), J16.7, J16.8, J16.15, J16.16, J16.23, J16.24, J16.MP (MountPin), J17.7, J17.8, J17.15, J17.16, J17.23, J17.24, J17.MP (MountPin), J21.4, J22.4; also elsewhere on the board
MISO1: J3.4, J5.4, J8.4, J11.4, J13.10, J13.21, J16.10, J16.21; also elsewhere on the board
MOSI1: J3.6, J5.6, J8.6, J11.6, J13.12, J13.19, J16.12, J16.19; also elsewhere on the board
RS485+: J13.11, J13.20, J14.12, J14.19, J16.11, J16.20, J17.12, J17.19, J21.2, J22.2; also elsewhere on the board
RS485-: J13.13, J13.18, J14.14, J14.17, J16.13, J16.18, J17.14, J17.17, J21.3, J22.3; also elsewhere on the board
SCK1: J3.2, J5.2, J8.2, J11.2, J13.14, J13.17, J16.14, J16.17; also elsewhere on the board
SCL1: J13.6, J13.25, J14.5, J14.26, J16.6, J16.25, J17.5, J17.26; also elsewhere on the board
SDA1: J13.4, J13.27, J14.3, J14.28, J16.4, J16.27, J17.3, J17.28; also elsewhere on the board
UART0-RTS/CS0: TP20.1; also elsewhere on the board
UART0_RX: TP2.1; also elsewhere on the board
UART0_TX: TP3.1; also elsewhere on the board
VDD: J3.1, J5.1, J8.1, J11.1, J13.1, J13.2, J13.29, J13.30, J14.1, J14.2, J14.29, J14.30, J16.1, J16.2, J16.29, J16.30, J17.1, J17.2, J17.29, J17.30, J21.1, J22.1, R2.1, R18.1, R19.1, R20.1; also elsewhere on the board

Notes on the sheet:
Reverse Orientation Connector, All pins are the same on both sides
CS pullup helps during device startup and decreases randomness
Can't populate due to parts not being available from China. Will have to manually populate
The CS pins can be used as a generic digital output, connected to the shift register. Each half of the board has its own pair of CS pins
I have 3 extra pins I could use instead of filling it with power connections. I could hook them up to USB for prog, and the LED
Communication/Chaining/Stacking Connectors
Top Side Receptacles
Motor Drivers
Hubs can stack vertically or horizontally, and can hold two sensors per side
DEBUG pins
Bottom Side Plugs



Board: 6 copper layers, 15.0 x 30.0 mm, 61 parts (30 on the bottom side), 59 nets.

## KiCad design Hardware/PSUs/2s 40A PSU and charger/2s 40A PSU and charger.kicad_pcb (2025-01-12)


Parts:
D2, D3: GSDH3005; D_0402_1005Metric; LCSC C2837790
NT10, NT12: PWR NetTie; NetTie-2_SMD_Pad0.28mm
R9: 10ohm; R_0805_2012Metric; LCSC C17415

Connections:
/Battery Balancer/+BAT: NT10.2; also elsewhere on the board
/Battery Charger/Always On PWR: R9.1; also elsewhere on the board
/Battery Charger/IN: NT12.2; also elsewhere on the board
unnamed: D2.2 (A), NT10.1
unnamed: D2.1 (K), D3.1 (K), R9.2
unnamed: D3.2 (A), NT12.1

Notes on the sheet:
All capacitors (in my current setup) are Ceremic and X5r or X7r according to datasheet recommendations. All low power capacitors should be rated for 6.3v, while high power should be 16v
Several components are not orderable from JLCPCB, or cannot be assembled by them (the power edge connectors). So I have added DNP indicators on those
all mosfets I currently have are not on jlcpcb
I might want to find a better diode for blocking current, but 0.01ma leakage doesn't seem bad
0805 Resistor

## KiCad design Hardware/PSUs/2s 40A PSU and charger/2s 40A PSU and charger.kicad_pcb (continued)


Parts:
C7: 10uF, 16v; C_0805_2012Metric; LCSC C15850
D11: CDDFN10-3324P; CDDFN103324P; Mouser Part Number 652-CDDFN10-3324P
H1: Bat+; MountingHole_2.2mm_M2_Pad_Via
H2: Bat-; MountingHole_2.2mm_M2_Pad_Via
J1, J3, J6, J7: Keystone 3579; Keystone_3579; not fitted
J2: JST XH-S Balance Plug; JST_XH_S3B-XH-A_1x03_P2.50mm_Horizontal; LCSC C161860; not fitted
J4, J5, J8, J9: Keystone 3569; Keystone_3569_half; not fitted
J10: G-Switch-GT-USB-7025; USB_C_G-Switch_GT-USB-7025-JLCPCBv; LCSC C963213
J11: 1.27mm 4 pin socket; PinSocket_1x04_P1.27mm_Vertical; not fitted
R2: 2ohm; R_0805_2012Metric; LCSC C17521
R19, R33: 5.1k; R_0402_1005Metric; LCSC C25905

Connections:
/Battery Balancer/+BAT: H1.1, J2.1; also elsewhere on the board
/Battery Balancer/-BAT: H2.1, J2.3; also elsewhere on the board
/Battery Balancer/Bat Cell 1: J2.2; also elsewhere on the board
/Battery Charger/IN: J10.A4 (VBUS), J10.A9 (VBUS), J10.B4 (VBUS), J10.B9 (VBUS), R2.2; also elsewhere on the board
/Battery Charger/MOTORPWR: J1.1, J3.1, J4.1, J5.1; also elsewhere on the board
/Connectors/3.3v: J11.1; also elsewhere on the board
/Connectors/CC1: D11.5 (IN/OUT_4), D11.6 (NC_1), J10.A5 (CC1), R33.2; also elsewhere on the board
/Connectors/CC2: D11.4 (IN/OUT_3), D11.7 (NC_2), J10.B5 (CC2), R19.2; also elsewhere on the board
/Connectors/D+: D11.1 (IN/OUT_1), D11.10 (NC_4), J10.A6 (D+), J10.B6 (D+); also elsewhere on the board
/Connectors/D-: D11.2 (IN/OUT_2), D11.9 (NC_3), J10.A7 (D-), J10.B7 (D-); also elsewhere on the board
/Connectors/RS485+: J11.2; also elsewhere on the board
/Connectors/RS485-: J11.3; also elsewhere on the board
GND: C7.2, D11.3 (GND_1), D11.8 (GND_2), J6.1, J7.1, J8.1, J9.1, J10.A1 (GND), J10.A12 (GND), J10.B1 (GND), J10.B12 (GND), J10.GND, J10.S1 (SHIELD), J11.4, R19.1, R33.1; also elsewhere on the board
unnamed: C7.1, R2.1

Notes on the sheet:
In-rush current limiter and smoother. Need a big resistor size like a 1206.
5.1k pulldown indicates this is a sink
Possible USB-C connectors: G-Switch 7025 (shorter), G-switch 7010asv
3.3v ESD/TVS diodes
Not populated due to custom handling required, and the parts aren't available from China.
Outputs
USB-C Charging
Inputs
Driver Power
Hubs Connector
Battery Plugs


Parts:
C5: 1nF, 16v; C_0402_1005Metric
C6, C17: 47nF, 16v; C_0603_1608Metric
C9, C10, C11, C21, C22, C23: 100nF, 16v; C_0402_1005Metric
C12, C14, C20: 10uF, 16v; C_0805_2012Metric
C15: 1uf, 16v; C_0402_1005Metric
C24: 2.2uf, 16v; C_0603_1608Metric
C29, C30: 100pF; C_0402_1005Metric
L2: 6.8uH HPC HPC5040NF-6R8M; L_Bourns_SDR0604
NT2, NT3, NT14: Sense NetTie; NetTie-2_SMD_Pad0.2mm
NT4: Charge NetTie; NetTie-2_SMD_Pad0.8mm
Q1, Q2, Q4, Q5: PJA3430, or HL 2320A; SC-59
Q3: Vishay sir404dp, or SiR500DP; PQFN-8-EP_6x5mm_P1.27mm_Generic; LCSC C3289487
R1: 10mOhm, 1W; R_1206_3216Metric
R7, R8, R10: 4.02k; R_0402_1005Metric
R12, R21, R22: 10ohm; R_0402_1005Metric
R18: 5mOhm, 10W, 2818; R_Vishay_2818
R20, R23, R24: 10k; R_0402_1005Metric
R30, R31: 866k; R_0402_1005Metric
U3: BQ24780SRUYR; RUY0028A

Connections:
/Battery Balancer/+BAT: C20.2, C22.2, C23.1, R18.1, R22.1, R30.2; also elsewhere on the board
/Battery Charger/Always On PWR: C15.1, U3.28 (VCC); also elsewhere on the board
/Battery Charger/Charger IADP: C29.1, U3.7 (IADP); also elsewhere on the board
/Battery Charger/Charger IDCHG: C30.1, U3.8 (IDCHG); also elsewhere on the board
/Battery Charger/Charger PROCHOT: U3.10 (PROCHOT_N); also elsewhere on the board
/Battery Charger/IN: C5.1, Q1.3 (D); also elsewhere on the board
/Battery Charger/MCU3.3v: R23.1, R24.1; also elsewhere on the board
/Battery Charger/MOTORPWR: C12.2, C14.2, NT3.2, NT4.2, Q3.5 (D), Q3.6 (D), Q3.7 (D), Q3.8 (D), R1.1; also elsewhere on the board
/Battery Charger/PWRON: U3.6 (ACDET); also elsewhere on the board
/Battery Charger/REGN: C24.1, R20.2, U3.24 (REGN)
/SCL: U3.12 (SCL); also elsewhere on the board
/SDA: U3.11 (SDA); also elsewhere on the board
GND: C9.1, C11.2, C12.1, C14.1, C15.2, C20.1, C21.1, C23.2, C24.2, C29.2, C30.2, Q5.2 (S), R31.1, U3.22 (GND), U3.29 (PAD); also elsewhere on the board
unnamed: C21.2, C22.1, L2.2, Q3.1 (S), Q3.2 (S), Q3.3 (S), R12.1, R18.2, R21.1
unnamed: NT14.1, R7.2
unnamed: C5.2, C6.2, Q1.1 (G), Q2.1 (G), R8.2
unnamed: C6.1, NT14.2, Q1.2 (S), Q2.2 (S)
unnamed: NT2.2, Q2.3 (D), R1.2
unnamed: Q3.4 (G), R10.1
unnamed: NT4.1, Q4.3 (D)
unnamed: Q4.1 (G), U3.26 (HIDRV)
unnamed: C17.2, L2.1, Q4.2 (S), Q5.3 (D), U3.27 (PHASE)
unnamed: Q5.1 (G), U3.23 (LODRV)
unnamed: R8.1, U3.4 (ACDRV)
unnamed: C10.2, C11.1, NT3.1, U3.1 (ACN)
unnamed: R23.2, U3.5 (ACOK)
unnamed: C9.2, C10.1, NT2.1, U3.2 (ACP)
unnamed: R10.2, U3.18 (BATDRV)
unnamed: U3.14 (CMPOUT), U3.15 (BATPRES_N)
unnamed: R12.2, U3.17 (BATSRC)
unnamed: C17.1, U3.25 (BTST)
unnamed: R30.1, R31.2, U3.13 (CMPIN)
unnamed: R7.1, U3.3 (CMSRC)
unnamed: R20.1, U3.21 (ILIM)
unnamed: R22.2, U3.19 (SRN)
unnamed: R21.2, U3.20 (SRP)
unnamed: R24.2, U3.16 (TB_STAT_N)

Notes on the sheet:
To support hybrid power boost mode, input current must be higher than 1536 mA for 10 mΩ input current sensing resistor. When input current is higher than 107% of input current limit in REG0x3F(), charger IC allows battery discharge and charger converter changes from buck converter to boost converte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
Batt plugged in, CMP is triggered and pulls batpres low
Inductor selection: With a 1mhz switching freq 6.8uH recommended Isat >= Ichg + 1/2 Iripple Iripple=(Vin*D*(1-D))/(Fs*L) D is duty cycle (Vout/Vin), the max ripple occurs at 50% This is a 2 cell charger, with battery ranging from 7.4v to 8.4v and input voltage at 9v. Iripple will at max be 0.4 amps.
It is really difficult to find an ideal power path controller. I need something that has Hybrid boost mode or DPPM, and is standalone, low component count, has external FETs for high system current, and cheap ( < $5). This is almost impossible. I found a few options for 1 cell batteries, but anythi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
Requires an i2c master to function. It is up to the host to control the charge cycles, like CC/CV, ultra low charge, and time delays every 100ms
Cgs should be 40× or higher than Cgd to avoid ACFET false turn on during adapter hot plug-in
Current sense resistor can only be scaled double or half. Right here I have it at half
Override adaptor detection with MCU logic. Saves a mosfet for USB-C power control
Adaptor must be above battery voltage (8.4v) to charge. I'm thinking 9 volt is pretty good
REGN is a 6v 100ma/13ma output
An alternative to Panjit transistors is 2320A from HL
- ProcHot indicates system limit failure - PMON is total system power scaled down, so it needs an ext res - IDAP and IDCHG indicates adaptor and discharge current w/ Voltage - Acok is adaptor present indicator - TB_Stat indicated hybrid boost mode ILIM and ACOK should not be left floating
GSDH3005 is a 30v, 500ma Schotkey diode 0402 package
Disable HW limit, set in software


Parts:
C25: 100nF, 16v; C_0402_1005Metric; LCSC C1525
C26: 4.7uF, 16v; C_0603_1608Metric; LCSC C19666
D4: 2.6~3.1 Fv Green 5ma; LED_0603_1608Metric_Pad1.05x0.95mm_HandSolder; LCSC C3028858
J12: USB; PinHeader_1x02_P1.27mm_Vertical; not fitted
R11, R29: 10k; R_0402_1005Metric; LCSC C25744
R25: 80.6 ohm; R_0402_1005Metric; LCSC C185392
R26, R27, R28: 120 ohm; R_0402_1005Metric; LCSC C25079
TP1: SWC; TestPoint_Pad_D1.0mm
TP2: CS; TestPoint_Pad_D1.0mm
TP3: SCK; TestPoint_Pad_D1.0mm
TP4: SWD; TestPoint_Pad_D1.0mm
TP5: SDI; TestPoint_Pad_D1.0mm
TP6: SDO; TestPoint_Pad_D1.0mm
U5: THVD1420DRLR; SOT-583-8; not fitted
U6: CH32X035G8U6; QFN-28-1EP_4x4mm_P0.4mm_EP2.8x2.8mm; LCSC C7437027

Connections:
/Battery Balancer/Balancer Alert: U6.14 (PB3); also elsewhere on the board
/Battery Charger/Charger IADP: U6.5 (ADC0/PA0); also elsewhere on the board
/Battery Charger/Charger IDCHG: U6.13 (PB0/ADC8); also elsewhere on the board
/Battery Charger/Charger PROCHOT: U6.15 (PB4); also elsewhere on the board
/Battery Charger/MCU3.3v: C25.1, C26.1, R11.2, R28.1, R29.2, U5.8 (VCC), U6.2 (VDD); also elsewhere on the board
/Battery Charger/PWRON: U6.17 (PB6); also elsewhere on the board
/Connectors/CC1: U6.28 (CC1/PC14); also elsewhere on the board
/Connectors/CC2: U6.1 (CC2/PC15); also elsewhere on the board
/Connectors/D+: J12.1, U6.27 (USB1_DP/PC17); also elsewhere on the board
/Connectors/D-: J12.2, U6.26 (USB1_DM/PC16); also elsewhere on the board
/Connectors/RS485+: R27.2, R28.2, U5.7 (B); also elsewhere on the board
/Connectors/RS485-: R26.1, R27.1, U5.6 (A); also elsewhere on the board
/MCU/CS: TP2.1, U6.9 (ADC4/PA4)
/MCU/LED: R25.1, U6.16 (PB1/PB5/ADC9)
/MCU/MISO: TP5.1, U6.11 (ADC6/PA6)
/MCU/MOSI: TP6.1, U6.12 (ADC7/PA7)
/MCU/SCLK: TP3.1, U6.10 (ADC5/PA5)
/MCU/UART1-RTS: U5.3 (DE), U6.6 (ADC1/PA1)
/MCU/UART1_RX: U5.1 (RO), U6.8 (ADC3/PA3)
/MCU/UART1_TX: U5.4 (DI), U6.7 (ADC2/PA2)
/SCL: R11.1, TP1.1, U6.24 (SWCLK/PC19); also elsewhere on the board
/SDA: R29.1, TP4.1, U6.25 (SWDIO/PC18); also elsewhere on the board
GND: C25.2, C26.2, D4.1 (K), R26.2, U5.2 (~RE), U5.5 (GND), U6.29 (GND); also elsewhere on the board
unnamed: D4.2 (A), R25.2

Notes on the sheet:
i2c pins are shared with swd pins, and BOOT is shared with USB D+ (which seems weird and may lead to debugging issues)
MCU is supplied from its own 100ma 3.3v regulator that runs directly off of battery or usb pwr
USB or SPI can be used to talk to the RS485 network, the mcu here acts as a converter and a sensor device
Just THT for optional connection
PC 10 and 11 are tied to these USB pins, so make sure to configure them floating
PWRON triggers the charger Adaptor detector which enables the FETs
Can't populate due to parts not being available from China. Will have to manually populate
Schematic symbol looks funky and reversed compared to the actual chip, however I have verified that the pins are correct
Are i2c pullups a problem for SWD? Its in the spec, but the programmer might already have them
RST does not exist on the QFN28 package
PB1 and PB5 are tied internally


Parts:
C2: 2.2uf, 16v; C_0603_1608Metric; LCSC C23630
C3, C4: 100nF, 16v; C_0402_1005Metric; LCSC C1525
C13, C18, C19: 220nF, 16v; C_0402_1005Metric; LCSC C16772
D1: GSDH3005; D_0402_1005Metric; LCSC C2837790
NT1, NT11: Sense NetTie; NetTie-2_SMD_Pad0.2mm
NT7, NT8, NT9: PWR NetTie; NetTie-2_SMD_Pad0.28mm
Q6: Vishay sir404dp, or SiR500DP; PQFN-8-EP_6x5mm_P1.27mm_Generic; LCSC C3289487
R3, R4, R5: 100ohm; R_0402_1005Metric; LCSC C25076
R6: 5.1k; R_0402_1005Metric; LCSC C25905
R14: 1mOhm, 6W; R_2512_6332Metric_6W; LCSC C19270875
R15, R16, R17: 10ohm; R_0402_1005Metric; LCSC C25077
U1: BQ76905RGRR; VQFN20_RGR_TEX; LCSC C22394458

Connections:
/Battery Balancer/+BAT: NT8.2, NT9.1; also elsewhere on the board
/Battery Balancer/-BAT: C2.2, NT1.1, NT7.2, R14.2, U1.8 (TS), U1.11 (VSS), U1.21 (GND); also elsewhere on the board
/Battery Balancer/Balancer Alert: U1.14 (ALERT); also elsewhere on the board
/Battery Balancer/Bat Cell 1: R16.2; also elsewhere on the board
/Battery Balancer/Low: C19.1, R17.1, U1.5 (VC0)
/Battery Balancer/Mid: C13.2, C18.1, R16.1, U1.1 (VC3A), U1.2 (VC3B), U1.3 (VC2), U1.4 (VC1), U1.19 (VC4A), U1.20 (VC4B)
/Battery Balancer/Up: C13.1, R15.1, U1.18 (V5)
/SCL: U1.12 (SCL); also elsewhere on the board
/SDA: U1.13 (SDA); also elsewhere on the board
GND: C4.2, Q6.5 (D), Q6.6 (D), Q6.7 (D), Q6.8 (D); also elsewhere on the board
unnamed: C3.1, NT1.2, R4.2
unnamed: C3.2, NT11.2, R5.2
unnamed: C4.1, NT11.1, Q6.1 (S), Q6.2 (S), Q6.3 (S), R14.1
unnamed: C18.2, C19.2, NT7.1, R17.2
unnamed: D1.2 (A), NT9.2
unnamed: D1.1 (K), R3.1
unnamed: NT8.1, R15.2
unnamed: Q6.4 (G), R6.2
unnamed: C2.1, R3.2, U1.16 (REGSRC), U1.17 (BAT)
unnamed: R6.1, U1.9 (DSG)
unnamed: R5.1, U1.7 (SRN)
unnamed: R4.1, U1.6 (SRP)

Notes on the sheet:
This must be connected to battery ground to operate in shutdown mode and recover
Can be configured standalone, but requires TI specialist programming and an I2C lockdown
Have to short sense lines together for fewer cells


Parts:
C27, C28: 22uf, 16v CL31A226MOCLNN; C_1206_3216Metric; LCSC C159758
C31: 10uF, 16v; C_0603_1608Metric; LCSC C96446
C32: 100nF, 16v; C_0402_1005Metric; LCSC C1525
C33: 2.2uF, 16v; C_0402_1005Metric; LCSC C12530
C40: 100nF, 16v; C_0603_1608Metric; LCSC C14663
L3: 2.2uH, WIP322512A-2R2MLDG; L_1008_2520Metric; LCSC C5832372
U2: AP63203WU; TSOT-23-6; LCSC C780769
U7: TPS7A2633DRV; WSON-6-1EP_2x2mm_P0.65mm_EP1x1.6mm; LCSC C2876256

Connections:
/Battery Charger/Always On PWR: C31.1, C32.1, U7.4 (EN), U7.6 (IN); also elsewhere on the board
/Battery Charger/MCU3.3v: C33.1, U7.1 (OUT); also elsewhere on the board
/Battery Charger/MOTORPWR: C28.1, U2.2 (EN), U2.3 (IN); also elsewhere on the board
/Connectors/3.3v: C27.1, L3.2, U2.1 (FB); also elsewhere on the board
GND: C27.2, C28.2, C31.2, C32.2, C33.2, U2.4 (GND), U7.2 (NC), U7.5 (GND), U7.7 (EP); also elsewhere on the board
unnamed: C40.1, U2.6 (BST)
unnamed: C40.2, L3.1, U2.5 (SW)

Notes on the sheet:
18v input, 2x2mm package, 500ma 3.3v out
Onboard MCU 3.3v Supply, 100mA
Main 3.3v Supply, 2A



Board: 4 copper layers, 45.0 x 20.0 mm, 112 parts (55 on the bottom side), 77 nets.

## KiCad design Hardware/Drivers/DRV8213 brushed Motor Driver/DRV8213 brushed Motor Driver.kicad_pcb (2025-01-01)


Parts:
C1, C2, C3, C4, C5, C7: 10uF, 16v; C_0603_1608Metric; LCSC C96446
C6, C8: 100nF, 16v; C_0402_1005Metric; LCSC C1525
C9: 2.2uF, 10v; C_0402_1005Metric; LCSC C12530
J1, J4, J5, J8: Keystone 3569; Keystone_3569_half; not fitted
J2, J3, J6, J7: Keystone 3579; Keystone_3579; not fitted
J9: JST PH 2mm horizontal; JST_PH_S2B-PH-K_1x02_P2.00mm_Horizontal; LCSC C160237
J10, J11: 1.27mm pin header; PinHeader_1x03_P1.27mm_Horizontal; not fitted
R1: 10k; R_0402_1005Metric; LCSC C25744
R2: 3.3k; R_0402_1005Metric; LCSC C25890
TP1: tinrush; TestPoint_Pad_D1.0mm
TP2: Fault; TestPoint_Pad_D1.0mm
U1: DRV8213RTER; WQFN-16-1EP_3x3mm_P0.5mm_EP1.68x1.68mm_ThermalVias; not fitted
U2: LP2981-3.3; SOT-23-5; LCSC C129997

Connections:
+3.3V: C9.1, R1.1, TP2.1, U1.2 (VCC), U1.11 (SMODE), U1.15 (IMODE), U1.16 (VREF), U2.5 (VOUT)
/CSA-A: J11.1, J11.2, R2.1, U1.1 (IPROPI)
/Fault: J11.3, R1.2, U1.3 (STALL_N), U1.4 (FAULT_N)
GNDPWR: C1.2, C2.2, C3.2, C4.2, C5.2, C6.2, C7.2, C8.2, C9.2, J5.1, J6.1, J7.1, J8.1, R2.2, U1.7 (PGND), U1.9 (GND), U1.14 (GAINSEL), U1.17 (Thermal_Pad), U2.2 (GND)
unnamed: J9.1, U1.6 (OUT1)
unnamed: J9.2, U1.8 (OUT2)
unnamed: J10.1, U1.13 (IN1)
unnamed: J10.2, U1.12 (IN2)
unnamed: TP1.1, U1.10 (TINRUSH)
VDD: C1.1, C2.1, C3.1, C4.1, C5.1, C6.1, C7.1, C8.1, J1.1, J2.1, J3.1, J4.1, U1.5 (VM), U2.1 (VIN), U2.3 (ON/~OFF)

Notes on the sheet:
GAIN sel to ground has 205uA/A gain, allowing the max current
R2 converts current mirror to a voltage. Tieing the gain to ground means it is 205uA/A
VIPROPI (V) = IPROPI (A) x RIPROPI (Ω) Max of 2.05v on output w/3.3v VM. Needs 1.25v headroom to maintain accuracy. OCP is = (VVREF (V) / RIPROPI (Ω)) / AIPROPI (μA/A) In my case, that is 4.7 A
- tINRUSH = 6.5 x 10^6 x CINRUSH, to set inrush time - Current regulation Enabled at all times - Stall detection Enabled
JLC doesn't have these parts, and I need to add some custom processing to cut the 3569 parts in half, so not populated
JLC doesn't have the right version of the chip
Any capacitors on the power supply line should be rated above my intended voltage range of 3.7-7.4v The bulk capacitance on VM should also be really high
INPUT Chain
OUTPUT Chain



Board: 4 copper layers, 15.0 x 15.0 mm, 26 parts (15 on the bottom side), 10 nets.

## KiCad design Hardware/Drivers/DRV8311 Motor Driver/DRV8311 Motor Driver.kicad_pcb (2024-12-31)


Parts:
C1: 4.7uF, 10v; C_0402_1005Metric
C2, C6: 100nF, 16v; C_0603_1608Metric
C3, C7: 100nF, 16v; C_0402_1005Metric
C4, C5, C8, C9, C10: 10uF, 16v; C_0603_1608Metric
J1, J2: 1.27mm pin header; PinHeader_1x03_P1.27mm_Horizontal; not fitted
J3, J7, J9, J11: Keystone 3579; Keystone_3579; not fitted
J4: Molex Picoblade; Molex_PicoBlade_53048-0310_1x03_P1.25mm_Horizontal
J5, J6, J8, J10: Keystone 3569; Keystone_3569_half; not fitted
NT1: NetTie_2; NetTie-2_SMD_Pad0.2mm
R1: 300k; R_0402_1005Metric
R2: 100k; R_0402_1005Metric
R3: 47k; R_0402_1005Metric
TP3: Fault; TestPoint_Pad_D1.0mm
TP4: GND; TestPoint_Pad_D1.0mm
TP5: 3.3v; TestPoint_Pad_D1.0mm
U1: DRV8311HRRWR; DRV8311_0.3mmVias

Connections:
+3.3V: C1.2, C7.2, TP5.1, U1.2 (CSAREF), U1.17 (AVDD), U1.18 (INLA), U1.19 (INLB), U1.20 (INLC), U1.23 (MODE)
GND: C1.1, C7.1, NT1.2, R2.1, R3.1, TP4.1, U1.16 (AGND)
GNDPWR: C3.2, C4.2, C5.2, C6.2, C8.2, C9.2, C10.2, J3.1, J5.1, J10.1, J11.1, NT1.1, U1.9 (PGND), U1.25 (PowerPAD)
unnamed: J1.1, U1.5 (SOA)
unnamed: J1.2, U1.4 (SOB)
unnamed: J1.3, U1.3 (SOC)
unnamed: J2.1, U1.15 (INHA)
unnamed: J2.2, U1.14 (INHB)
unnamed: J2.3, U1.13 (INHC)
unnamed: J4.1, U1.10 (OUTA)
unnamed: J4.2, U1.11 (OUTB)
unnamed: J4.3, U1.12 (OUTC)
unnamed: C2.1, U1.6 (CP)
unnamed: TP3.1, U1.1 (FAULT_N)
unnamed: R3.2, U1.21 (GAIN)
unnamed: R1.1, R2.2, U1.24 (SLEEP_N)
VDD: C2.2, C3.1, C4.1, C5.1, C6.1, C8.1, C9.1, C10.1, J6.1, J7.1, J8.1, J9.1, R1.2, U1.7 (VIN_AVDD), U1.8 (VM)

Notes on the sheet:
Internal pulldown nSLEEP is 230kO. I need it always enabled, so I have a voltage divider on motor power.
Can't populate due to parts not being available from China, and custom processing required. Will have to manually populate
Slew rate not connected is 180 V/us. Gain connected to ground is 0.25V/A, or 0.5 when tied to 47k gnd. Formula for CSA out volts is Vref/2 +- gain*I
Datasheet has separation of powers and grounds to prevent EMI, with the joint through the power pad. I'm separating gnds and joining at the pad only
Any capacitors on the power supply line should be rated above my intended voltage range of 3.7-7.4v The bulk capacitance on VM should also be really high
INPUT Chain
OUTPUT Chain



Board: 4 copper layers, 15.0 x 15.0 mm, 29 parts (17 on the bottom side), 17 nets.

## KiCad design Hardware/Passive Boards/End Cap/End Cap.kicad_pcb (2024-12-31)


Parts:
J1: 1.27mm 4 pin header; PinHeader_1x04_P1.27mm_Vertical; not fitted
J2, J4, J6, J8: Keystone 3579; Keystone_3579; not fitted
J3, J5, J7, J9: Keystone 3569; Keystone_3569_half; not fitted
R1: 120ohm; R_0402_1005Metric; LCSC C25079
TP3: 3.3v; TestPoint_Pad_D1.0mm
TP4: GND; TestPoint_Pad_D1.0mm

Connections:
/MOTORPWR: J2.1, J3.1, J6.1, J7.1
GND: J1.1, J4.1, J5.1, J8.1, J9.1, TP4.1
unnamed: J1.2, R1.2
unnamed: J1.3, R1.1
unnamed: J1.4, TP3.1

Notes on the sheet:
Custom handling required, and the parts don't exist in LCSC.
Hubs Connector
Driver Power



Board: 2 copper layers, 45.0 x 5.0 mm, 12 parts (7 on the bottom side), 5 nets.

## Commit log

2024-09-24 Initial adaption of DRV8311 board
    I had this from a previous test pcb. It works really well after fixing the errata, so I will only make a few minor changes to the physical design for the card.
    [DRV8311 Motor Driver BOM.csv, DRV8311 Motor Driver.kicad_pcb, DRV8311 Motor Driver.kicad_sch]
2024-09-24 Replaced external connectors
    I have keystone smd low profile contacts for the power, and 1.27mm pitch headers for the data pins.
    [DRV8311 Motor Driver.kicad_pcb, DRV8311 Motor Driver.kicad_sch]
2024-09-24 Finished basic layout for motor driver card
    The power connectors as of now have no way of contacting adjacent cards. The layout will need some tuning, but I think the components for the most part can stay in the same place.
    [DRV8311 Motor Driver.kicad_pcb, DRV8311 Motor Driver.kicad_sch]
2024-09-25 Re-arranged components for better mating
    The power connectors now should make contact. The difficulty will be getting them in, because they are supposed to go forward and I'm causing the connectors to slide in sidewards.
    [DRV8311 Motor Driver.kicad_pcb]
2024-09-25 Finished basic routing
    I still need to optimize it, and work out how to improve conductivity and thermal properties
    [DRV8311 Motor Driver.kicad_pcb]
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2024-10-09 Finished ESP32-S3 Hub Schematic
    This is a rough draft, but the schematic has most of the basic things worked out. ERC has not been run
    [Connectors.kicad_sch, ESP32-S3 Hub.kicad_pcb, ESP32-S3 Hub.kicad_sch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]
2024-10-13 Fixed ERC errors, stopped tracking a few .obsidian files
    The only errors that popped up were the dual labeling of CS0 and Uart RTS, a power flag spot, and a modified footprint error.
    [Connectors.kicad_sch, ESP32-S3 Hub.kicad_sch, Periphery.kicad_sch]
2024-10-14 Switched out Mezzanine Connectors
    I'm going with some 30-pin TE mezzanine connectors, which are cheaper than before and have a few extra pins if I need them in the future.
    [Connectors.kicad_sch, Periphery.kicad_sch]
2024-10-14 Started Layout
    I added the footprints on the PCB file. My goal is to fit everything within a 15x30mm package. We will see!
    [ESP32-S3 Hub.kicad_pcb, ESP32-S3 Hub.kicad_sch]
2024-10-15 Switching out footprints for smaller variants, dropping rs485 resistors
    Space is tight, so I had to downsize the crystal and the reset switches. I also don't have space for the rs485 termination resistors configurable per device, so I have excluded this from the board.
    [Connectors.kicad_sch, ESP32-S3 Hub.kicad_pcb, ESP32-S3 Hub.kicad_sch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]
2024-10-16 Finished basic layout
    Everything is crammed in there, I do have some extras bit of space up top for an extra component or two. I probably should take advantage of that space somehow. For routing this thing, I really think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
    [Connectors.kicad_sch, ESP32-S3 Hub.kicad_pcb, ESP32-S3 Hub.kicad_sch]
2024-10-18 Swapping register pins
    I tryid to simplify the layout a little bit. I also added a note about the potential danger of the i2c lines on low level glitching pins.
    [Connectors.kicad_sch, ESP32-S3 Hub.kicad_sch, Periphery.kicad_sch]
2024-10-18 Fixed potential glitch problems caused by pullup resistors
    I2c w/ pullups will likely have problems with glitching on those first 20 pins, so I have shifted all the motor pwm pins down, and stuck the FREEx pins and the i2c pins near the end. Now, only the motor pins and the analog pins will have glitching. Since it is a low level glitch, and there are no pullups on those lines, it should be fine.
    I also added a note about a weird state on GPIO1
    [ESP32-S3 Hub.kicad_sch]
2024-10-18 Switched to 6 layer design
    I still need to arrange the stackup correctly
    [ESP32-S3 Hub.kicad_pcb]
2024-10-19 Changed layer stack
    I now have a layer stack of Sig/Gnd/Sig/Pwr/Gnd/Sig, which appears to be a common arrangement except I've reversed the order. I added a lot of signals in the middle of the power layer though, because I need more space and I previously had too many signals on my dedicated ground plane.
    I also connected Free2 to the correct connectors in the schematic, something I missed when I changed the esp32 pin assignments.
    [Connectors.kicad_sch, ESP32-S3 Hub.kicad_pcb]
2024-10-19 Removed unneeded via for CS2
    I routed directly to the connector, no via necessary.
    [ESP32-S3 Hub.kicad_pcb]
2024-10-19 Added ground keepouts and series resistor to crystal
    The ground keepouts are mostly to prevent random areas of ground copper where I have limited space. The keepout was required for the crystal though.
    I also added a 22 ohm series resistor to the crystal path, because many examples have that.
    [ESP32-S3 Hub.kicad_pcb, ESP32-S3 Hub.kicad_sch]
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2024-10-19 Shifting vias to route i2c
    I spent a solid 3 hours trying to get this one trace through without cutting off other traces, finally managed to do it now. It was a lot of playing around with vias until everything fit.
    [ESP32-S3 Hub.kicad_pcb]
2024-10-19 Routed UART, buttons, and flipped analog power cap
    I needed a capacitor near the power input at the top, because otherwise the power is flowing directly from the plane through the one via. I'm still not sure that I've fixed a problem, its seems likely that the main power flowing so close to the chips pins is a bad idea.
    [ESP32-S3 Hub.kicad_pcb]
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2024-10-19 Swapped header logical numbers
    I realized my numbering scheme was off with the actual board layout. So in the schematic I swapped the connectors without rewiring so that the numbers are more logical. CS7, CS8, and Free2 are now for the top mezzanine connector, which is closer to the pins on the chips. It also falls in line with my bottom up numbering scheme.
    [Connectors.kicad_sch, ESP32-S3 Hub.kicad_pcb, ESP32-S3 Hub.kicad_sch]
2024-10-20 Finished routing PWM motor pins
    I did have to sacrifice the continuity of one of my ground planes to make it happen though. I tried to keep it to a minimum
    [ESP32-S3 Hub.kicad_pcb]
2024-10-20 Finished basic routing
    Now I have to fix some things to try and reduce crosstalk, and improve signal integrity. The likelihood of me being able to completely fix it is low, due to limited space. I also have to run the DRC, and fix the silkscreen.
    [Connectors.kicad_sch, ESP32-S3 Hub.kicad_pcb, ESP32-S3 Hub.kicad_sch]
2024-10-20 Cleaned up wires, added IO46 testpad, added license to design files
    I also added a ground plane to In3.
    [Connectors.kicad_sch, ESP32-S3 Hub.kicad_pcb, ESP32-S3 Hub.kicad_sch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]
2024-10-20 Removed problem connections on bottom connector
    We don't want several masters fighting over gpio pins or the SPI bus, so I have removed all connections on the bottom side except the multi-master capable busses.
    [Connectors.kicad_sch, ESP32-S3 Hub.kicad_pcb]
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2024-10-20 Fixed DRC errors
    There were a lot of board clearance issues with the magnetic sensor connectors. I had to change the copper to edge distance to 0.28mm from 0.3, as well as move the connectors a smidge back from the edge.
    [ESP32-S3 Hub.kicad_pcb]
2024-10-20 Fixing board edge pin header 3d models
    I tried first switching out the footprint entirely, but that resulted in the 3d models pointing in to the board. I rotated all the connections in the schematic and the board, but that came with a billion errors because the pin one is a square and way to many traces are close to the pins. I instead used my current vertical footprint and manually changed the 3d model for each. I may have problems if these headers are put in a pick and place, because they will point inward by default, but in most cases these should be hand soldered.
    [Connectors.kicad_sch, ESP32-S3 Hub.kicad_pcb]
2024-10-21 Started switchout of motor power connectors
    It looks like I may actually have gotten connectors a bit TOO big! I don't know if it will fit!
    [DRV8311 Motor Driver.kicad_pcb, DRV8311 Motor Driver.kicad_sch]
2024-10-21 Redesigned Motor Driver module for higher current
    I doubled up the connectors on the edge, and I switched to a cheaper version of the same edge connector from Keystone. I'm planning on cutting the receptor in half because the male connector does not fully use the length, and I can save space and time. This is why the footprint is sticking off the edge
    [DRV8311 Motor Driver BOM.csv, DRV8311 Motor Driver.kicad_pcb, DRV8311 Motor Driver.kicad_sch]
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2024-10-25 Finished Brushed motor driver DRV8213
    It can handle 4 amps, and uses a JST PH connector for the motor.
    [DRV8213 brushed Motor Driver BOM.csv, DRV8213 brushed Motor Driver.kicad_pcb, DRV8213 brushed Motor Driver.kicad_sch]
2024-10-26 Started designing PSU board
    Based on the test board that I did.
    [2s 40A PSU and charger.kicad_pcb, 2s 40A PSU and charger.kicad_sch, PSU.kicad_sch]
2024-10-26 Rearranged schematic hierarchy
    It should be clearer than the original design from my testing board. I haven't changed any of the design things except getting the correct small transistor footprint (errata from before)
    [2s 40A PSU and charger.kicad_pcb, 2s 40A PSU and charger.kicad_sch, Battery Balancer.kicad_sch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]
2024-11-20 Fixed OE pin by adding pullup, updated silkscreen
    The silkscreen looks really nice now, I have all the port labels.
    [Connectors.kicad_sch, ESP32-S3 Hub.kicad_pcb, ESP32-S3 Hub.kicad_sch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]
2024-11-29 Reworked PSU to use CH32X035 and USB-PD
    This will save a few bucks and will actually be a cooler solution than just a DC jack connected to some pads
    [2s 40A PSU and charger.kicad_pcb, 2s 40A PSU and charger.kicad_sch, Battery Balancer.kicad_sch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]
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2024-12-01 Added use of Net Class Directives to speed up routing
    I don't have to manually change wire sizes now
    [2s 40A PSU and charger.kicad_pcb, 2s 40A PSU and charger.kicad_sch, Battery Balancer.kicad_sch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]
2024-12-01 Updated Sheet Properties
    My author name is now in there, and I've added the proper project name.
    [2s 40A PSU and charger.kicad_pcb, 2s 40A PSU and charger.kicad_sch, Battery Balancer.kicad_sch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]
2024-12-01 Adjusted board thickness to have 2 oz outer copper and 0.5 oz inner copper
    [2s 40A PSU and charger.kicad_pcb]
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2024-12-19 Merged Always on PWR for multiple devices
    The diode OR and the 10 ohm resistor are now shared between the MCU and the battery charger
    [2s 40A PSU and charger.kicad_pcb, 2s 40A PSU and charger.kicad_sch, Battery Charger.kicad_sch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]
2024-12-20 Switched out always on 3v3 reg to smaller WSON-6
    This is more expensive, but a bit smaller and still has the same input voltage range
    [2s 40A PSU and charger.kicad_pcb, PSU.kicad_sch]
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2024-12-21 Removed snubber from USB shield and connected direct to GND
    This saves on components, and as far as good/bad RF practicalities go, many people are split on the practicality of it. I will go with the simpler method
    [2s 40A PSU and charger.kicad_pcb, Connectors.kicad_sch]
2024-12-21 Disconnect REGN from unneeded output pullups
    These pullups will instead be pulled to 3v3, which should be closer locally. I don't use them but pullups are required for internal detection.
    [2s 40A PSU and charger.kicad_pcb, 2s 40A PSU and charger.kicad_sch, Battery Charger.kicad_sch]
2024-12-21 Fixed Always On PWR connection
    I had it connected to motor power and battery power, what it should have been connected to was USB-C and battery, no barriers whatsoever
    [2s 40A PSU and charger.kicad_sch]
2024-12-21 Fixed Logic Pwr netclass
    I had renamed it at some point from "Logic Power" to "Logic Pwr". This messed up some of my net class wire sizes
    [2s 40A PSU and charger.kicad_sch, Battery Balancer.kicad_sch, PSU.kicad_sch]
2024-12-21 Finished Layout of PSU
    Gosh, this has taken a long time on and off, almost 2 months!
    [2s 40A PSU and charger.kicad_pcb, Connectors.kicad_sch, MCU.kicad_sch]
2024-12-21 Updated 3v3 psu traces and capacitor position
    I rotated the input capacitor to make a more compact shape, and I played around with some of the trace thicknesses
    [2s 40A PSU and charger.kicad_pcb, PSU.kicad_sch]
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2024-12-24 Fixed incorrect mosfet pin assignments
    This was an issue from the last test board I designed that I didn't catch. The mosfets have different pin assignments for drain, gate, and source, and I had messed those up in the schematic by choosing the wrong symbol. This should be fixed now
    [2s 40A PSU and charger.kicad_pcb, 2s 40A PSU and charger.kicad_sch, Battery Balancer.kicad_sch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]
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2024-12-27 Fixed routing of DRV8213 board and updated 3d models
    I swapped the current sense and the PWM input headers accidentally! I fixed that now. I also added the proper 3d models and footprints. I exported a 3d model of the board. The last change I made ws cleaning up the inner layers to only be power planes.
    [DRV8213 brushed Motor Driver BOM.csv, DRV8213 brushed Motor Driver.kicad_pcb, DRV8213 brushed Motor Driver.kicad_sch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]
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2024-12-28 Created 2 connector sensor breakout board to avoid needing a spacer
    The bottom is completely flat, and there is little extra room beyond the connectors
    [2 connector Sensor Board.kicad_pcb, 2 connector Sensor Board.kicad_sch, 2 connector Sensor Board.step]
2024-12-28 Fixed left side swapped headers, tuned RS485 skew
    The left side shouldn't have been mirrored, it should be rotated 180. I had to swap the CSA and the PWM output headers, which was a hassle. I also tuned the RS485 trace skews finally, something I forgot when I "finished" the board a month ago.
    [ESP32-S3 Hub.kicad_pcb, ESP32-S3 Hub.kicad_sch]
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2024-12-29 Fixed headers and connectors miss-alignments
    Almost everything was misaligned. The holes on the hub to hub headers must be 2.9mm from the edge, the header holes on the motor drivers must be 4.5mm from the edge, and the centers of the power connectors(either gender) must be 2.15mm from the edge
    [2s 40A PSU and charger.kicad_pcb, 2s 40A PSU and charger.step, DRV8213 brushed Motor Driver.kicad_pcb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]
2024-12-29 Fixed 0.2mm offset in 3d model of Keystone 3579 connector
    It was inset into the pcb a little which was causing some vertical misalignment in the CAD model. This affects nothing in real life, just a nice quality of life thing.
    [2s 40A PSU and charger.kicad_pcb, 2s 40A PSU and charger.step, Connectors.kicad_sch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]
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2024-12-31 Fixed Current sense resistor footprints, adjusted current GND blocks
    I had to source alternative resistors and change the footprints as well. I didn't realize though that the 2818 footprint I had was wrong though, 2816 is not quite compatible!
    Another thing I did was fix gnd guides and added horse shoe shapes around the sensitive component vias.
    [2s 40A PSU and charger Main BOM.csv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]
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2025-01-12 Fixed issue with USB-C pad spacing on 2oz copper
    The minimum spacing between tracks on 2oz copper is 0.16mm, and I had explicitly ignored the USB-C connector pin spacing 0.12mm in a custom DRC rule, which turned out to be a problem. I removed that rule and modified the USB-C connector pads to be slightly narrower to give more gap.
    [2s 40A PSU and charger-B_Cu.gbl, 2s 40A PSU and charger-B_Mask.gbs, 2s 40A PSU and charger-B_Paste.gbp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]
2025-01-13 Changed link names for schematic embeds not displayin
    In Obsidian I can see the pdf embeds perfectly fine, but Github doesn't want to show embedded PDFs. I changed the link alias to "Schematic PDF" so people know what the link is when it doesn't display
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2025-09-26 Started replacement of MCU with STM32
    [MCU.kicad_sch]
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2025-10-10 Revert Separation of hardare versions
    This folder versioning will be limited to production files only now
    [Connectors.kicad_sch, ESP32-S3 Hub Main BOM.csv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]
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2025-10-12 Updated component arrangements and fixed pinout on upstream port
    [Connectors.kicad_sch, ESP32-S3 Hub.kicad_pcb]
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2025-10-17 Add 5mil traces & 0.4mm vias, started via placement
    I am decreasing the size further to speed up routing and avoid pain. The cost will be higher, but not that much higher from 0.3mm to 0.2mm and 0.6mm to 0.4mm vias. I can route more items.
    [ESP32-S3 Hub.kicad_pcb]
2025-10-17 Fix some track sizes and clearance issues
    [ESP32-S3 Hub.kicad_pcb]
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2025-10-26 Swapped out footprints on pcb, started routing
    [ESP32-S3 Hub.kicad_pcb]
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2025-11-01 Swapped around pins and routed main driver outputs
    [ESP32-S3 Hub.kicad_pcb, ESP32-S3 Hub.kicad_sch, Periphery.kicad_sch]
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

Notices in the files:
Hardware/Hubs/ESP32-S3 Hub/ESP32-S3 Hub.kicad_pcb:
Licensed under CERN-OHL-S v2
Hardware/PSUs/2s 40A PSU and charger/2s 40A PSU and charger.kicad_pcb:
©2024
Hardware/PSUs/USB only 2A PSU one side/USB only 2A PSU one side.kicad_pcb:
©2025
